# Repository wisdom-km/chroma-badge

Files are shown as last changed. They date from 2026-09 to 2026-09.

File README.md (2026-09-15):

# chroma-badge（BADGE-42C）：4.2 寸四色墨水屏 NFC 工牌

> **当前：** [状态](docs/06-current-status.md) · [交接](docs/03-handoff.md) · [流程](docs/09-process.md)（许可证 / CI / 贴胶 / 生产包）。2026-09-14 复审是**旧 564 段板**档案，不要当现板。

仓库：https://github.com/wisdom-km/chroma-badge

一块 **6.3 mm 厚**的电子工牌：4.2" 黑白红黄四色墨水屏 + ESP32-C3（Wi-Fi/BLE/原生 USB）+ ST25DV64KC NFC + ≤2 mm 超薄锂电 + USB-C。固件目前是 v0.2 上电自检；手机传图（F2）未写。

| 背面 PCB 渲染 | 外壳（FreeCAD） |
|---|---|
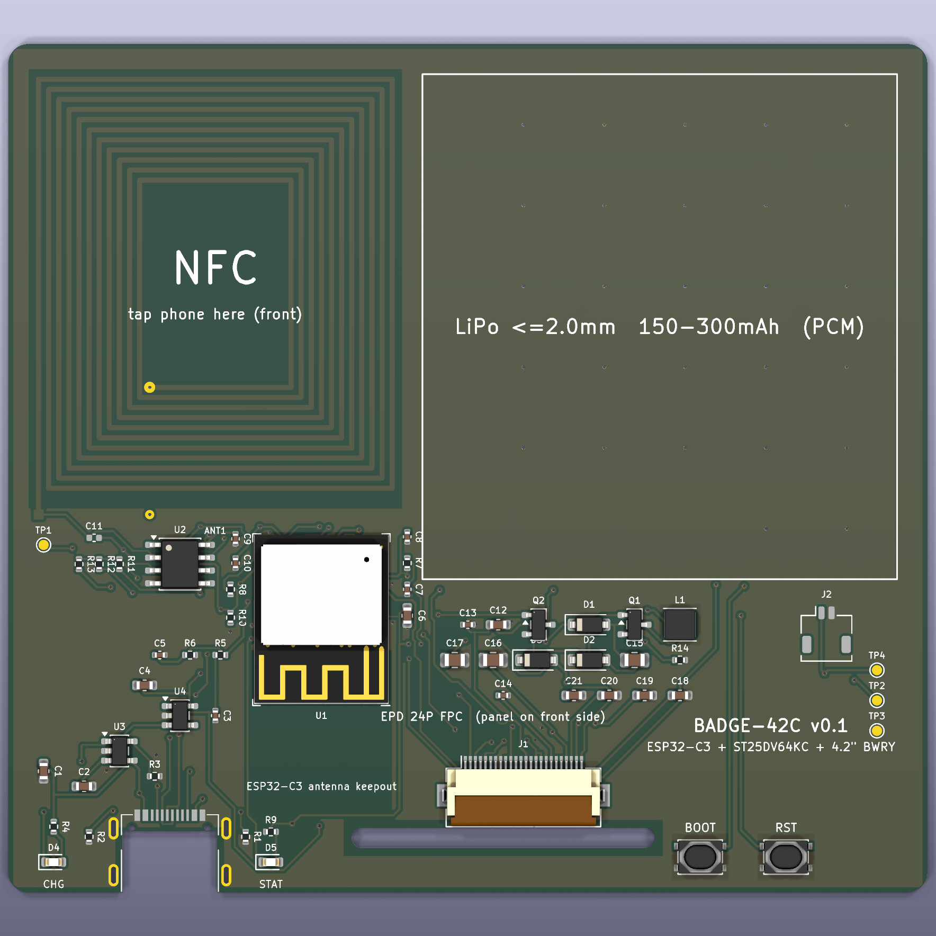
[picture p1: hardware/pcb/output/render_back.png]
pcb
|  | 见 `hardware/enclosure/output/badge_assembly.step` |

## 在本地接着做

```bash
git clone https://github.com/wisdom-km/chroma-badge.git
cd chroma-badge
```

用 Cursor **打开这个文件夹**（本地 Agent）。根目录 `AGENTS.md` 和 `.cursor/rules/badge.mdc` 会带上约定。

## 仓库

- `LICENSE.md`：硬件 CERN-OHL-P-2.0，固件/脚本 MIT
- `AGENTS.md`：硬性约定与当前进度
- `docs/01-architecture-decisions.md`：选型
- `docs/02-bom-and-cost.md`：BOM；屏贴胶 3M 467MP
- `docs/03-handoff.md`：复现步骤与**当前板**指纹
- `docs/09-process.md`：CI、生产包、贴胶
- `hardware/pcb/`：由 `scripts/design.py` 生成
- `firmware/README.md`：v0.2 自检；不要覆盖 `output/badge-42c-v0.1*.bin`

## 快速开始

全量 ERC/DRC 需要 KiCad **10.0.6**。不要把 `gen_pcb.py` 当日常命令（会清布线）。日常检查：

```bash
cd hardware/pcb
python3 scripts/check_netlist.py
./scripts/export.sh --check-only
```

自动布线流程见 `docs/03-handoff.md` 第 3 节。

## 状态

**H2（2026-09-15）：** 58 封装，PCB **680 段 / 115 过孔**，J1.7 NC。KiCad 10.0.6 全量 ERC/DRC 0。USB **0.8 mm**。固件 **v0.2 F1**。没有生产 zip。

下一步：打样实机；F2 须选定一条传图路线。

## 第三方内容

- 乐鑫 KiCad 库（ESP32-C3-MINI-1）：CC-BY-SA 4.0
- HRO TYPE-C-31-M-14 封装：jenschr/USB-C-Connectors，公有领域
- 其余符号/封装来自 KiCad 官方库

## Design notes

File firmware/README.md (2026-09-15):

# 固件

硬件引脚以 `hardware/pcb/scripts/design.py` 为准。本目录是 **v0.2 上电自检**：USB 日志、电池 ADC、ST25DV I²C 探测；正常启动后串口 5 s 内发 `W` 则按官方 OTP 刷一屏白（不要按住 BOOT 复位，那是 ROM 下载）。然后深睡，只由 `NFC_GPO`（GPIO1）低电平唤醒。GPIO9 不是深睡唤醒源。

屏：GDEM042F86 / SSD2683ZA，400×300，2 bit/像素（00 黑 01 白 10 黄 11 红）。初始化抄规格书 2026-06-17 **第 31 页** LUT from OTP，不写波形 RAM。

## 构建

ESP32-C3-MINI-1，原生 USB-Serial-JTAG（没有外置 UART）。

预编译基线（2026-09-14，不要覆盖）：

- `output/badge-42c-v0.1.bin`（应用，296 512 B）
- `output/badge-42c-v0.1-bootloader.bin`
- `output/badge-42c-v0.1-partitions.bin`

v0.2 用 `pio run` 生成到 `.pio/build/`，有板后再拷新版本号，不要覆盖上面三份。

```bash
cd firmware
pio run
pio run -t upload
pio device monitor
```

没有 PlatformIO 时：安装 [pio](https://platformio.org/) 或 Arduino-ESP32（板选 ESP32C3 Dev Module，CDC on boot）。不要把 PlatformIO IDE 的 `.vsix` 装进 Cursor（那是 VS Code 扩展）。

## 上电行为

1. GPIO2（`EPD_PWR_EN`）保持高：P-MOS 关，屏断电。
2. USB CDC 打 `BADGE-42C firmware v0.2`、电池电压、ST25DV 是否 ACK。
3. USB CDC 就绪后 **5 s 内发字符 `W`**：刷全白（约 20 s），BUSY 未完成周期则报 `TIMEOUT` 并断电。
4. 否则闪三下状态灯，深睡。只唤醒 `NFC_GPO`。**按住 BOOT + RESET = ROM 下载，不是刷白。**

还没做：NDEF URL、FTM 邮箱收图、完整工牌画面。

## 引脚表（ESP32-C3-MINI-1）

| GPIO | 信号 | 方向 | 说明 |
|---|---|---|---|
| 0 | `BAT_SENSE` | ADC1_CH0 | 电池电压 ÷2（1 MΩ / 1 MΩ），满电 4.2 V → 2.1 V |
| 1 | `NFC_GPO` | 输入，RTC 唤醒 | ST25DV GPO，开漏，100 kΩ 上拉。RF 场 / 邮箱新消息拉低 |
| 2 | `EPD_PWR_EN` | 输出 | 低有效。10 kΩ 上拉，P-MOS 默认关（strapping，上电为高） |
| 3 | `EPD_BUSY` | 输入 | 忙时为低（规格书 note 5-4） |
| 4 | `I2C_SDA` | I²C | ST25DV，4.7 kΩ 上拉 |
| 5 | `I2C_SCL` | I²C | 同上 |
| 6 | `EPD_SCK` | SPI CLK | 4 线 SPI（BS1 接地） |
| 7 | `EPD_MOSI` | SPI MOSI | |
| 8 | `LED_STAT_n` | 输出，低有效 | 绿色状态灯（strapping，空闲为高） |
| 9 | `BOOT_n` | 输入 | BOOT / 用户键 SW2，10 kΩ 上拉 |
| 10 | `EPD_CS` | 输出 | |
| 18 | `USB_D-` | USB | 原生 USB-Serial-JTAG |
| 19 | `USB_D+` | USB | |
| 20 | `EPD_DC` | 输出 | |
| 21 | `EPD_RST` | 输出 | |
| EN | RESET | | SW1，10 kΩ + 1 µF |

## 器件地址

- ST25DV64KC：I²C `0x53`（用户区）、`0x57`（系统区），FTM 邮箱 256 B
- 屏：GDEM042F86 = SSD2683ZA；不要用 GDEY042F51（HX8717）的 LUT

## 预算

- 每次刷新（含收图）：1.7–3 J
- 待机目标：≤ 15 µA

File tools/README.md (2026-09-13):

# 本机工具（Windows）

大软件装系统（KiCad / Git / 可选 FreeCAD），可移植的放这里。不要把 KiCad 或 FreeCAD 整个拷进仓库。

## 已约定路径

| 工具 | 路径 |
|---|---|
| KiCad 9 | `C:\Users\19612\AppData\Local\Programs\KiCad\9.0\` （当前用户安装；不是 `C:\Program Files\KiCad\9.0\`） |
| `kicad-cli` | `C:\Users\19612\AppData\Local\Programs\KiCad\9.0\bin\kicad-cli.exe` |
| KiCad Python | `C:\Users\19612\AppData\Local\Programs\KiCad\9.0\bin\python.exe` |
| 符号/封装库 | `...\9.0\share\kicad\symbols` 与 `...\9.0\share\kicad\footprints` |
| Freerouting 2.4.1 | `tools/freerouting/freerouting.jar` |
| 便携 JRE 25 | `tools/jre/bin/java.exe` |

`design.py` 会自动探测 `Program Files\KiCad` 和 `%LOCALAPPDATA%\Programs\KiCad`，并优先 9.x。若你改了安装位置，把实际路径写在上表。

## 装 KiCad 9（不要 8，也不要用 winget 默认的 10）

```powershell
winget install --id KiCad.KiCad -e --version 9.0.8 --accept-package-agreements --accept-source-agreements
```

装完**新开终端**，把 KiCad 加进 PATH（当前会话）：

本机实际路径（winget 当前用户安装）：

```powershell
$kicadBin = "$env:LOCALAPPDATA\Programs\KiCad\9.0\bin"
$env:Path = "$kicadBin;" + $env:Path
git --version
kicad-cli --version
where.exe kicad-cli
& "$kicadBin\python.exe" -c "import pcbnew; print('pcbnew ok')"
```

Git Bash：

```bash
export PATH="$LOCALAPPDATA/Programs/KiCad/9.0/bin:$PATH"
kicad-cli --version
```

`sexpdata` 必须装进 **KiCad 自带的 Python**，不是系统 Python：

```powershell
$py = "$env:LOCALAPPDATA\Programs\KiCad\9.0\bin\python.exe"
& $py -m pip install sexpdata
& $py -c "import sexpdata; print('sexpdata ok')"
```

## Freerouting 2.4.1 + 便携 JRE

jar 和 JRE 都 gitignore 了（体积大）。在仓库根目录执行：

```powershell
New-Item -ItemType Directory -Force -Path tools\freerouting, tools\_download | Out-Null

# Freerouting 2.4.1（不要 1.x）
curl.exe -L --fail -o tools\freerouting\freerouting.jar `
  https://github.com/freerouting/freerouting/releases/download/v2.4.1/freerouting-2.4.1.jar

# Eclipse Temurin JRE 25 x64 zip
curl.exe -L --fail -o tools\_download\OpenJDK25U-jre_x64_windows.zip `
  https://github.com/adoptium/temurin25-binaries/releases/download/jdk-25.0.4.1%2B1/OpenJDK25U-jre_x64_windows_hotspot_25.0.4.1_1.zip
```

把 zip 解压后，把里面那层 `jdk-*-jre\` 的内容挪到 `tools\jre\`，保证存在 `tools\jre\bin\java.exe`。

验证（相对路径；Freerouting 的 `-do` 必须在 `output` 目录下用相对文件名，绝对路径会得到 0 字节 `.ses`）：

```powershell
tools\jre\bin\java.exe -version
```

`route_pcb.py` 会优先用仓库里的 jar / JRE，找不到再回退 `/opt/freerouting/...` 或 PATH 里的 `java`。

**不要用 Python `subprocess` 跑 Freerouting。** 必须 `cd output` 再用相对 `-de`/`-do`。详见 `docs/03-handoff.md` 第 3 节。

## 冒烟测试

在仓库根目录：

```powershell
$kicadBin = "$env:LOCALAPPDATA\Programs\KiCad\9.0\bin"
$env:Path = "$kicadBin;" + $env:Path
cd hardware\pcb
& "$kicadBin\python.exe" scripts\check_netlist.py
# 若还没有 output\badge.net：
# kicad-cli sch export netlist -o output\badge.net badge.kicad_sch

kicad-cli pcb drc --severity-error --format json -o output\drc_tmp.json badge.kicad_pcb
```

期望：`netlist matches design.py`；`drc_tmp.json` 里 `violations` / `unconnected_items` 为空。

不要跑 `gen_pcb.py`（会清布线）。不要跑 Freerouting，除非要做 NFC 盖绿油。

## `export.sh`

Windows 用 Git Bash（不要改成只支持 cmd）：

```bash
cd hardware/pcb
export PATH="$LOCALAPPDATA/Programs/KiCad/9.0/bin:$PATH"
bash ./scripts/export.sh
```

`export.sh` 里的 `python3` 若找不到，用 KiCad Python 跑网表检查（KiCad 的 `python.exe` 一般没有 `python3` 这个名字）：

```bash
export PATH="$LOCALAPPDATA/Programs/KiCad/9.0/bin:$PATH"
"$LOCALAPPDATA/Programs/KiCad/9.0/bin/python.exe" scripts/check_netlist.py
```

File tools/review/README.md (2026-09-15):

# Cursor / Codex 本机审查执行手册（Windows）

本目录是**隔离审查工具**，不是替换 `hardware/pcb/scripts/export.sh` 的生产发布流程。它不重建PCB、不启动Freerouting、不修改产品固件。`postprocess_probe.py`在第二份副本上验证原`--skip-route`，不会碰工作区PCB。

阅读顺序：根AGENTS → 原交接/ADR → [当前状态](../../docs/06-current-status.md) → [合并计划](../../docs/reviews/2026-09-14/integrated-plan.md)。本轮基准的已知缺陷会使一些检查返回非零；正确记录失败，不要通过删掉警告获得“全绿”。

## 1. 环境发现与前置

本轮可用：KiCad9.0.8安装在 `D:/chroma-badge/agent-tools/kicad-9.0.8`；FreeCAD1.1.3在 `D:/FreeCAD`；PlatformIO6.2.0在 `D:/PlatformIO/penv`；MinGW GCC13.1.0来自CLion工具目录。工具体积大，`agent-tools/`在gitignore中，不入库。其他机器按实际路径修改变量。

```powershell
Set-Location D:/chroma-badge
git status --short
git log -5 --oneline
$kicadBin = 'D:/chroma-badge/agent-tools/kicad-9.0.8/bin'
$freecadPy = 'D:/FreeCAD/bin/python.exe'
$pio = 'D:/PlatformIO/penv/Scripts/pio.exe'
$gitBash = 'G:/BaseWare/Git/bin/bash.exe'
$compiler = 'G:/BaseWare/CodeProgram/CLion 2023.3.4/bin/mingw/bin/g++.exe'
& "$kicadBin/kicad-cli.exe" --version
& "$kicadBin/python.exe" -c "import pcbnew; print(pcbnew.Version())"
& $freecadPy -c "import FreeCAD, Part; print(FreeCAD.Version())"
& $pio --version
& $compiler --version
```

必须确认KiCad为9，不能因PATH上有10就直接采用。原文档记载的用户9.0路径在本轮开始时不存在，本机已有10。winget把安装9当成升级已有包而拒绝；本轮从`winget show --id KiCad.KiCad -e --version 9.0.8`查询官方安装包，校验SHA256后独立安装，没有卸载10。

9.0.8安装包SHA256：`f853f81dd6a90c769c521a35c438c5657fe39aaebe9967c8a74e743540920eb5`。
官方下载：[kicad-9.0.8-x86_64.exe](https://github.com/KiCad/kicad-source-mirror/releases/download/9.0.8/kicad-9.0.8-x86_64.exe)。静默安装需同时指定`/currentuser /S`，最后一个参数才是`/D=安装路径`；仅`/S`本轮返回666660。[KiCad官方打包问题记录](https://gitlab.com/kicad/packaging/kicad-win-builder/-/work_items/135)。安装软件前仍遵循当前任务授权，不把本文当无限安装授权。

受限运行环境可能无法访问用户安装目录/工具缓存。此时先核对权限与路径，不删除PlatformIO缓存、不反复重装。KiCad无需打开GUI即可执行这些测试。

## 2. 新建隔离输入副本

```powershell
$auditRoot = Join-Path (Get-Location) ('agent-tools/review-' + (Get-Date -Format 'yyyyMMdd-HHmmss'))
python tools/review/prepare.py --out $auditRoot
if ($LASTEXITCODE -ne 0) { throw 'prepare failed' }
```

`prepare.py`复制Git已跟踪的hardware/firmware文件，记录工作区输入SHA256、源提交与起始git状态。审查副本的`.kicad_pro`使用HEAD版本，原本机修改单独保存为`local-project.kicad_pro`。**如果硬件或固件文件有未提交修改，它们会被复制并在manifest中留痕，不能把该副本谎称纯HEAD。** 本轮只有工程配置有既有修改，已明确隔离。

输出目录必须全新；不复用已归档的 `docs/reviews/.../evidence`。安装器、SDK、模型和厂商PDF不得放到待提交集合。

## 3. KiCad全量检查与诊断导出

```powershell
python tools/review/kicad_checks.py --audit $auditRoot --kicad-bin $kicadBin --export
$auditExit = $LASTEXITCODE
Get-Content "$auditRoot/kicad/summary.json"
Get-Content "$auditRoot/kicad/commands.json"
```

这个审查程序故意继续收集完整诊断数据；任何子命令非零，最终程序返回1。**返回1不是可以忽略的发布成功**，应读 `commands.json` 与对应报告。不会发布制造包。

它逐项执行：

- 全量ERC、error级ERC，均加`--exit-code-violations`。
- 全量DRC加`--schematic-parity`、error级DRC；保留原始JSON。
- 重新导出网表后执行仓库原`check_netlist.py`。
- pcbnew读取PCB，逐个核对设计引脚/显式NC、板尺寸/层数、走线/过孔、网络宽度、3D模型引用和阻焊状态。
- `--export`时诊断导出Gerber、钻孔、BOM、位置、完整STEP，以及全板背面和J1特写。

本轮基准期望：error ERC0/DRC0/未连接0；全量ERC1条warning、DRC含parity148条warning；全量CLI返回5，审查程序返回1。报告类型：57 text_height、1 silk_over_copper、6 silk_overlap、62 footprint_symbol_mismatch、22 net_conflict。后三种不能都视为真实短路，详见复审解释。

模型文件缺失时KiCad STEP仍可能返回0，必须结合`board-audit.json`和`step.log`判断模型覆盖。板尺寸`91×84`取Edge.Cuts端点极值；含0.1mm线条笔画的包围盒是`91.1×84.1`，不要据此改板框。

补充原理图/板图诊断导出以及历史Gerber比较：

```powershell
python tools/review/extra_exports.py --audit $auditRoot --kicad-bin $kicadBin
if ($LASTEXITCODE -ne 0) { throw 'extra diagnostic export failed' }
Get-Content "$auditRoot/kicad/extra-exports.json"
```

比较只移除四类生成日期行，不移除坐标/孔径/属性；gbrjob单独未比较。本轮13份Gerber/钻孔文件中12份一致，背面丝印不同，不能交付旧ZIP当当前完整制造包。`--compare-only`可只重算已存在输出的比较。

## 4. 后处理幂等性（副本测试）

先验证原理图和NFC封装生成（可选扩展，本轮已执行）：

```powershell
& "$kicadBin/python.exe" -m pip install --target agent-tools/review-python-deps sexpdata==1.0.2
if ($LASTEXITCODE -ne 0) { throw 'generator dependency install failed' }
python tools/review/generators_probe.py --audit $auditRoot --kicad-bin $kicadBin --python-deps agent-tools/review-python-deps
if ($LASTEXITCODE -ne 0) { throw 'schematic/NFC generation probe failed' }
```

这会新建第三份副本，运行原生成器，再导出网表、运行原检查器和error ERC。KiCad自带Python的启动路径在本轮未采用外部PYTHONPATH，因此包装器显式添加隔离依赖目录；不改原生成器或Python安装。**不运行gen_pcb.py**。

```powershell
python tools/review/postprocess_probe.py --audit $auditRoot --kicad-bin $kicadBin
if ($LASTEXITCODE -ne 0) { throw 'postprocess changed routing or failed' }
Get-Content "$auditRoot/postprocess/summary.json"
```

它另复制一份PCB，执行两次`--skip-route`，每次保留原始日志和error级DRC，再比较走线/过孔的数量与精确坐标、层、网络、宽度、孔径指纹，以及设计网络分配。本轮三次快照均564/128、相同指纹。原路由日志仍可能写“若干几何islands未stitch”；本轮它们电气连通，不能用这句替代最终未连接检查。

这不验证“从未布线板重新Freerouting”的全链，也不证明任意新设计幂等。`--skip-route`源码仍可能修补走线，只在本轮输入上证实未改变。

## 5. FreeCAD生成和扩展交叠检查

```powershell
& $freecadPy tools/review/mechanical.py --snapshot "$auditRoot/snapshot" --out "$auditRoot/mechanical-saved-step.json"
if ($LASTEXITCODE -ne 0) { throw 'saved STEP geometry check failed' }
& $freecadPy tools/review/mechanical.py --snapshot "$auditRoot/snapshot" --step "$auditRoot/kicad/badge-fresh.step" --out "$auditRoot/mechanical-fresh-step.json"
if ($LASTEXITCODE -ne 0) { throw 'fresh STEP geometry check failed' }
& $freecadPy "$auditRoot/snapshot/hardware/enclosure/badge_enclosure.py"
if ($LASTEXITCODE -ne 0) { throw 'enclosure generation failed' }
& $freecadPy "$auditRoot/snapshot/hardware/enclosure/render_views.py"
if ($LASTEXITCODE -ne 0) { throw 'enclosure render failed' }
```

`mechanical.py`仅在内存中移除外壳脚本末尾`main()`调用后加载几何函数，原源文件不修改。实际原生成器另在副本运行。扩展检查5类物体两两10组，体积交叠容限0.05mm³并检查solid有效性。本轮都为0；但USB/电池座缺模型、FPC和电池等包络不完整，不能批准实装。检查源码后再检查对准的图；遵循`docs/05-visual-check.md`。

## 6. 固件构建、源映射和异常探测

```powershell
$env:PLATFORMIO_BUILD_DIR = Join-Path $auditRoot 'firmware-clean-build'
& $pio run -d firmware *> "$auditRoot/firmware-clean-build.log"
if ($LASTEXITCODE -ne 0) { throw 'firmware build failed' }
python tools/review/static_audit.py --out "$auditRoot/static.json" --build "$auditRoot/firmware-clean-build/badge-42c"
if ($LASTEXITCODE -ne 0) { throw 'source/pin audit failed' }
python tools/review/host_probes.py --compiler $compiler --out "$auditRoot/host"
if ($LASTEXITCODE -ne 0) { throw 'EPD characterization changed or compiler failed' }
python tools/review/fault_probes.py --bash $gitBash --out "$auditRoot/faults"
if ($LASTEXITCODE -ne 0) { throw 'failure-path characterization changed' }
```

这些probe里，**固件** host_probes 在 F1 之后：仅 `normal` 报成功；BUSY 恒高、卡低、关电超时、刷新超时必须失败。测试通过意味着假成功已堵住，不是实屏通过。H1 之后 `fault_probes.py` 已改为 **F04/F19 回归**：旧 DRC 报告注入必须失败；ERC/DRC 失败不得走到 Gerber。所有模拟输出中的毫秒都是替身时钟，不是屏幕测量。

静态审查比较模组符号脚名、design和pins.h，避免只照抄GPIO注释；检查9份原脚本AST、BOM/位置、旧ZIP目录一致性和三份bin哈希。它只记录ZIP/BOM问题，不把发现自动删除或重写。

## 7. export.sh（H1 之后）

H1 已改 `hardware/pcb/scripts/export.sh`：error 级 ERC/DRC 加 `--exit-code-violations`，去掉 DRC `|| true`；解释器为 `python3` / `python` / `py -3`；zip 用 `zip_dir.py`，不依赖 `zip` 命令。默认写入 `output/exports/<stamp>-candidate/`，**禁止**覆盖 `output/gerbers` 与 `output/badge_gerbers.zip`。`--production` 拒绝。全量 warning 见 `docs/hardware/drc-warning-register.md`，全部未豁免。

`fault_probes.py` 中的假 `kicad-cli` 仅用于隔离流程测试。不要仅放一个假的 python3 返回 0 来让真实脚本过关。候选目录不是生产包。

## 8. 证据与提交

本轮原始证据在`docs/reviews/2026-09-14/evidence/`，公开文件都列SHA256。今后新审查用新日期/轮次，不覆盖历史证据；不要提交整个`agent-tools`、安装包、SDK、缓存、厂商PDF或无关用户文件。

每次提交前检查：本轮变更是否只在预期范围、输入哈希是否还对应、报告是否保留失败、全量警告是否明确、网表/DRC是否当次运行、实际测试与未测是否分开。用户没有授权修硬件时不改网络，没有授权新PR时不创建PR；推送只按当前会话授权执行，禁止force push。

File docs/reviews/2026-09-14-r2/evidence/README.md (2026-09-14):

# 2026-09-14-r2 证据索引

隔离复跑目录：`agent-tools/review-20260914-234456`。本目录只收 **可入库的摘要与小文件**，不是生产包，也不覆盖 [首轮证据](../../2026-09-14/evidence/README.md)。大型 STEP/Gerber/SDK 留在 `agent-tools/`。

硬件/固件基准内容：`ee978f0`。审查时 HEAD：`11ab832`。

| 文件 | 用途 |
|---|---|
| [execution-summary.json](../execution-summary.json) | 退出码与“缺陷复现 vs 产品通过”区分 |
| [inputs.json](inputs.json) | 工作区 SHA256、起始 ` M badge.kicad_pro` / `?? tools/freerouting/` |
| [kicad-summary.json](kicad-summary.json)、[commands.json](commands.json) | 当次分类计数与命令返回码 |
| [erc-all.json](erc-all.json)、[erc-errors.json](erc-errors.json) | 全量 1 warning；error 0 |
| [drc-all-parity.json](drc-all-parity.json)、[drc-errors.json](drc-errors.json) | 148 warning；error/未连接 0 |
| [board-audit.json](board-audit.json) | 57/564/128、91×84×0.8、J2/J3 模型缺失、网络类别未进工程 |
| [extra-exports.json](extra-exports.json) | 诊断导出；B.Silk 归一化不相等 |
| [postprocess-summary.json](postprocess-summary.json) | 布线指纹三次相同 |
| [generators-summary.json](generators-summary.json) | 未跑 `gen_pcb.py` |
| [static.json](static.json) | AST、GPIO 映射、ZIP 内部一致、bin 哈希 |
| [firmware-clean-build.log](firmware-clean-build.log) | 干净目录构建 SUCCESS |
| [epd-probes.json](epd-probes.json)、[host-compile.log](host-compile.log) | 20 次替身；含假成功 |
| [faults.json](faults.json) | 旧 DRC 报告与 DRC 吞错 |
| [mechanical-*.json](mechanical-saved-step.json) | 10 组交叠 0；缺 FPC/真电池包络 |
| [original-export.log](original-export.log) | 原 export.sh：本轮 Git Bash 无 python3 |
| [step.log](step.log) | STEP 仍返回 0 |

预览是本轮新渲，不是实物照片：

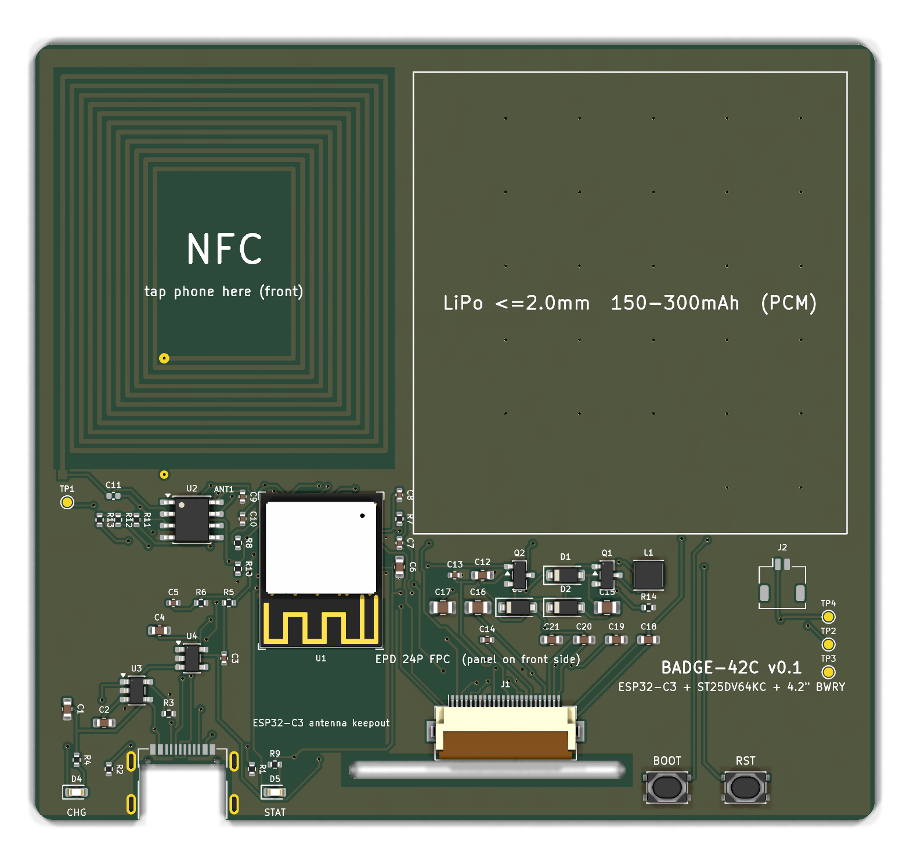
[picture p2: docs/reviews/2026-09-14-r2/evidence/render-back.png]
背面全板


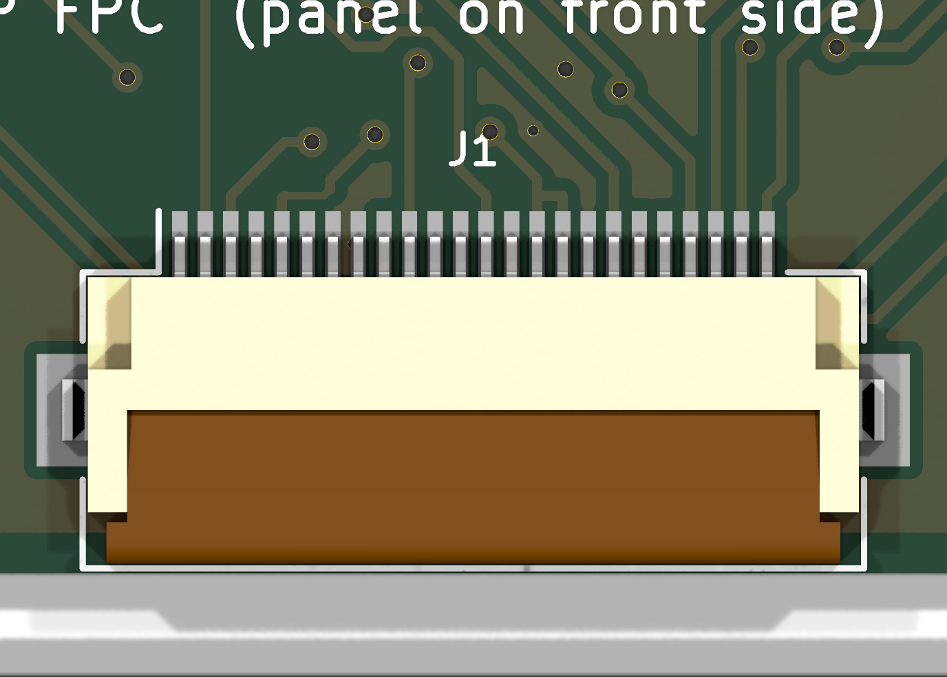
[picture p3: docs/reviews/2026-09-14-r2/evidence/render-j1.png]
J1 特写


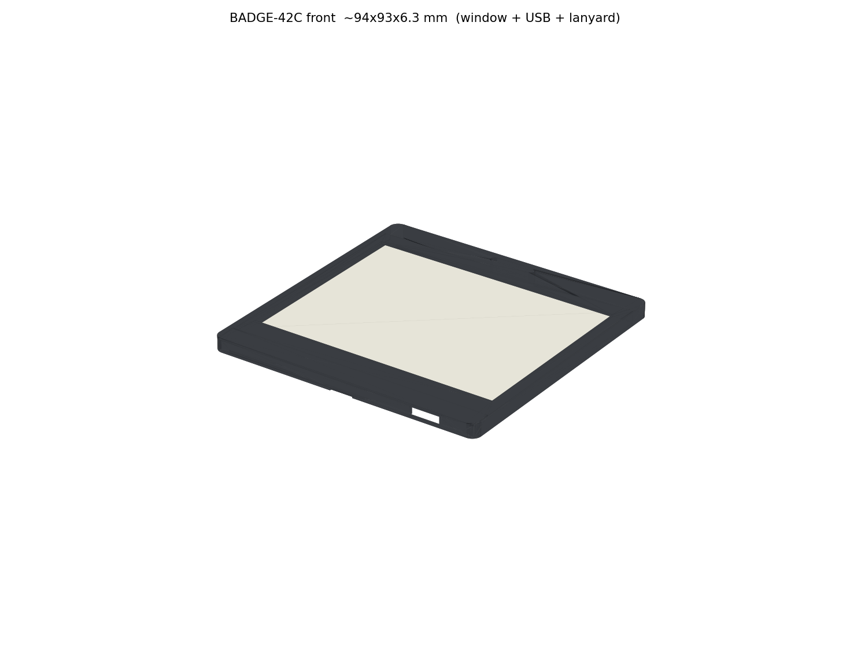
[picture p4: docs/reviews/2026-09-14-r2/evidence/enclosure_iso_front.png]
外壳正面结构


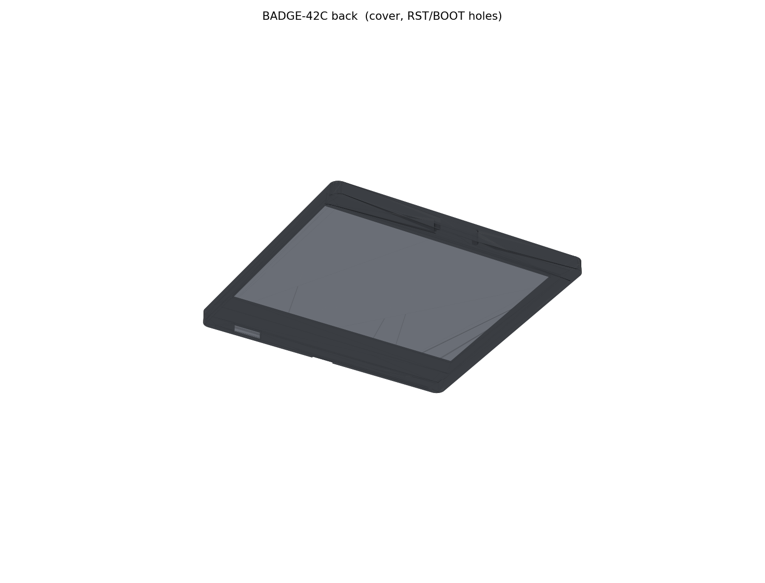
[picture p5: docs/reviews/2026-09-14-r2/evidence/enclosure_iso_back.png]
外壳背面结构


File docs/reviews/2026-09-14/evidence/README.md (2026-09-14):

# 2026-09-14 本机复审证据索引

硬件/固件基准：`ee978f08cbdb7b61bbe2c78fea0e9c7cd2c34a7b`。本目录包含诊断证据，**不是生产发布包**。缺陷仍未修复，实机测试尚未执行。完整结论见 [独立复审](../local-review.md) 和 [合并计划](../integrated-plan.md)。

## 输入与完整性

| 文件 | 内容 |
|---|---|
| [inputs.json](inputs.json) | 审查开始时工作区已跟踪文件的SHA256/大小、源commit和起始状态；审查副本用提交版工程配置 |
| [sources.json](sources.json) | 用户原审查、确切屏PDF、KiCad安装包SHA256；屏PDF印刷日期2026/06/17、Revision1.0、40页；PDF未入库 |
| [preservation.json](preservation.json) | 确认所有原硬件/固件及其输出文件字节未变；保留起始本机`.kicad_pro`改动 |
| [manifest.json](manifest.json) | 本目录各证据文件SHA256和字节数；清单不包含自身 |

目录属性禁止Git换行转换，以便原始日志与报告SHA256在不同机器检出仍一致。`inputs.json`的输入哈希描述审查时的工作区字节，而非声称所有输入文件等于Git规范化blob字节。

## 检查结果与原始报告

| 文件 | 结果与用途 |
|---|---|
| [commands.json](commands.json)、[summary.json](summary.json) | 当次KiCad命令/返回值和全量分类统计 |
| [erc-all.json](erc-all.json)、[erc-errors.json](erc-errors.json) | 全量1警告，error0；U1库符号问题未关闭 |
| [drc-all-parity.json](drc-all-parity.json)、[drc-errors.json](drc-errors.json) | 64板级+84parity警告，error0、未连接0 |
| [drc-localsettings.json](drc-localsettings.json) | 起始本机未提交配置下error级DRC仍0；使用的是副本 |
| [netlist-check.log](netlist-check.log)、[netlist-export.log](netlist-export.log) | 新导出网表后运行原检查器，匹配设计、63原理图网络 |
| [generators-summary.json](generators-summary.json)、[generated-erc.json](generated-erc.json) | 原理图/NFC生成器真实复跑；网表匹配、error ERC0；NFC封装忽略换行相同 |
| [execution-summary.json](execution-summary.json) | 补充命令退出码与测试性质，区分产品通过与旧缺陷复现 |
| [board-audit.json](board-audit.json) | 57封装/564段/128孔/91×84×0.8mm、引脚映射、网络统计、模型缺项、NFC阻焊与未落地类别 |
| [postprocess-summary.json](postprocess-summary.json) | 原板→第一次→第二次`--skip-route`的路由指纹一致 |
| [postprocess-cycle-1.log](postprocess-cycle-1.log)、[postprocess-cycle-2.log](postprocess-cycle-2.log) | 原后处理过程，未启动Freerouting；日志里几何岛描述不是未连接判定 |
| [postprocess-cycle-1-drc.json](postprocess-cycle-1-drc.json)、[postprocess-cycle-2-drc.json](postprocess-cycle-2-drc.json) | 两次独立最终error报告，违规/未连接均空 |
| [static.json](static.json) | 9份原Python脚本AST、13个GPIO映射、BOM/位置、当前ZIP内部比较、三份固件哈希 |
| [firmware-clean-build.log](firmware-clean-build.log) | 全新目录编译，包括真实依赖/内存占用；三份bin与原版本字节一致 |
| [epd-probes.json](epd-probes.json)、[host-compile.log](host-compile.log) | 20次原EPD代码的替身调用；有两种已复现假成功；fake_elapsed_ms不是实测时间 |
| [faults.json](faults.json) | ERC进程失败可阻断；DRC失败被吞；`drc_json`返回旧报告的故障注入 |
| [original-export.log](original-export.log)、[bash-prerequisites.log](bash-prerequisites.log) | 原导出脚本实际执行到python3退出49；WindowsApps别名及缺zip，不是制造包生成成功 |

## 制造与机械

| 文件 | 结果与局限 |
|---|---|
| [extra-exports.json](extra-exports.json) | 原理图PDF/SVG、PCB SVG、裸板STEP命令成功；13份新旧Gerber/孔数据的日期归一化比较 |
| [manufacturing-diff.json](manufacturing-diff.json)、[back-silkscreen.diff](back-silkscreen.diff) | 旧背面丝印与新导出真实坐标不同；旧ZIP内部一致却仍带旧丝印 |
| [step.log](step.log) | J3、J2模型无法加入，但完整STEP命令仍返回0 |
| [mechanical-saved-step.json](mechanical-saved-step.json) | 既有STEP下实体有效、扩展10组交叠为0 |
| [mechanical-fresh-step.json](mechanical-fresh-step.json) | 新导出STEP下同样通过；缺实体仍不能检验相应干涉 |
| [enclosure-generation.log](enclosure-generation.log)、[enclosure-render.log](enclosure-render.log) | 原FreeCAD生成器/5张预览真正运行，产物都在副本 |

其他同名`.log`保留对应CLI原输出。大型STEP、生成器副本、SDK、安装包、厂商PDF和模拟可执行文件留在忽略目录，不入库。新生成的Gerber只是诊断，不覆盖原制造包；既有生产包的来源不因本报告而获得批准。

## 对准的预览

这些是本轮新生成图片，不是实物照片。J1特写已对准连接器和槽；J2/J3缺外形必须与模型解析日志结合看，不能推断没放PCB元件。FreeCAD两图用于看结构，严格干涉判断来自OCC数值。

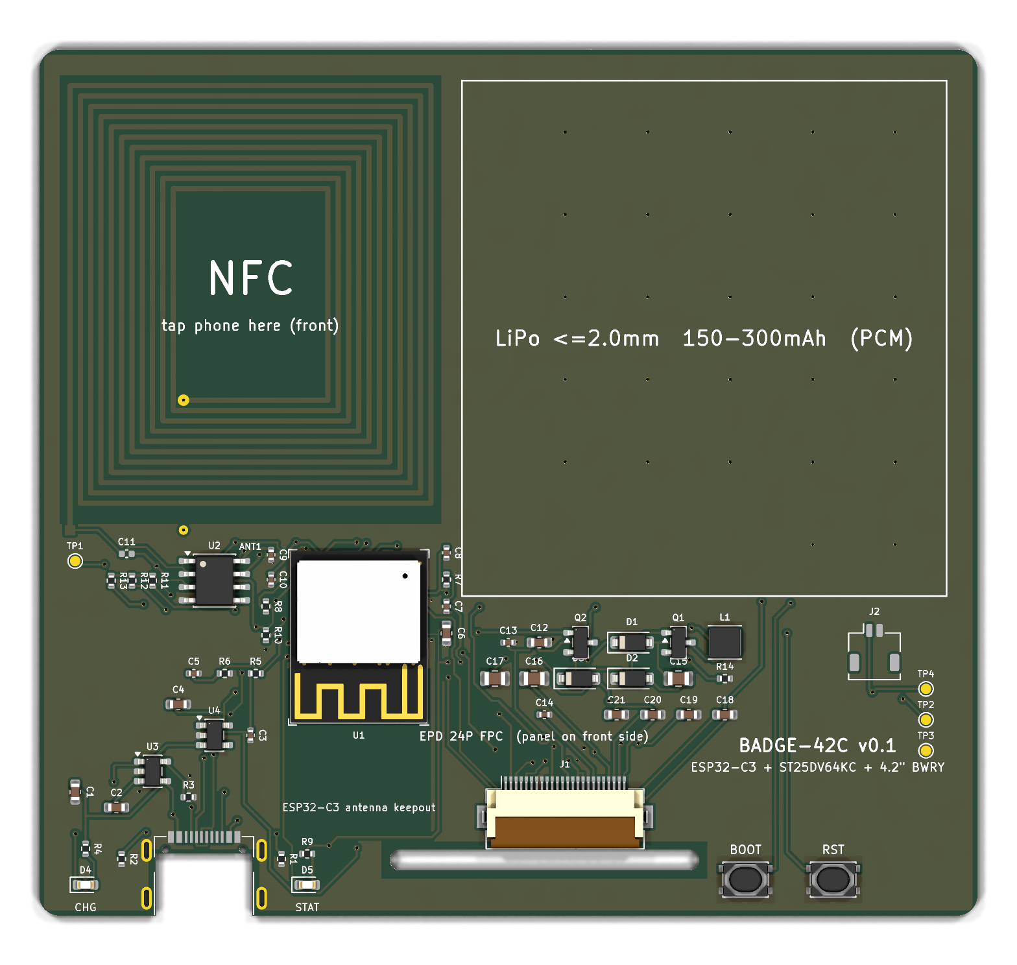
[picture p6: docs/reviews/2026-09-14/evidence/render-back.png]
本轮KiCad背面全板


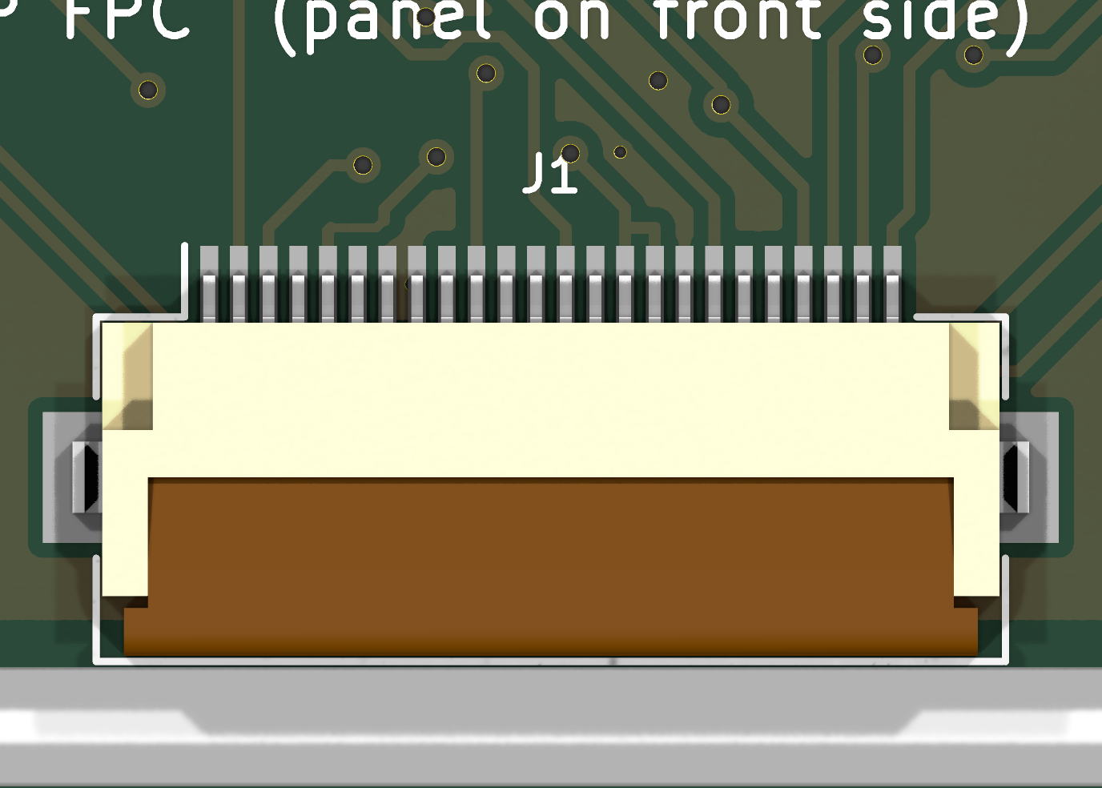
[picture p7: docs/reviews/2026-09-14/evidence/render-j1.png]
J1与FPC槽的对准特写


FreeCAD前框预览

FreeCAD后盖预览

## 复跑和判读

执行 [工具手册](../../../../tools/review/README.md)，每轮使用新的隔离目录。全量检查返回5表示发现违规，审查收集程序最终返回1是保留失败，不是测试工具意外全部崩溃。`host_probes`和`fault_probes`是旧缺陷特征测试；通过意味着缺陷被复现，修复后必须改成新的防回归预期。

能得出的结论：设计数据/当前error规则检查、编译及有限几何验证有证据；存在已确认缺陷和交付不同步。不能得出的结论：真实USB/显示/RF/充电/续航/装配已通过，或可立即生产。

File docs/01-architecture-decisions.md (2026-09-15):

# 架构决策记录（ADR）

本文记录 4.2 寸彩色墨水屏工牌的关键选型和取舍。所有数字来自 2026 年 9 月检索到的厂商公开资料，价格为参考价。

## 1. 屏幕：4.2 寸四色（BWRY），而不是六色

### 为什么 4.2 寸没有六色可选

E Ink Spectra 6（六色）目前的小尺寸型号只有 1.54"、1.69"、3.6"、3.7"、4.0"、5.9"、7.3"，**没有 4.2 寸**。
最接近的是 4.0 寸 GDEP040E01（600×400，外形 99×66 mm，偏宽屏）和 3.7 寸 GDEH037E01（480×720，58×85.6 mm，竖版）。

### 四色 vs 六色 显示效果

| | 4.2" 四色 GDEM042F86 | 4.0" 六色 GDEP040E01 |
|---|---|---|
| 颜色 | 黑 / 白 / 红 / 黄 | 黑 / 白 / 红 / 黄 / 蓝 / 绿 |
| 分辨率 / PPI | 400×300 / 119 | 600×400 / 180 |
| 全刷 | 20 s（快刷 12 s） | 14–19 s |
| 刷新功耗 | 12 mW（VCI=3.0 V） | < 70 mW |
| 工作温度 | 0–40 ℃ | 0–50 ℃ |
| 裸屏价格 | ≈ ¥70–100 | ≈ ¥100–330 |
| 驱动库 | 佳显官方 ESP32 示例；GxEPD2 支持同系列 HX8717 版 | GxEPD2 不支持 4.0"，需自写 |

**结论**：
- 显示"彩色照片 / 渐变 logo"六色明显更好（PPI 高 50%，色域大一倍）。
- 显示"姓名 + 职位 + 二维码 + 品牌色块"这类工牌内容，四色已经够用，红黄两色足够做强调色和公司标识。
- 六色刷新功耗是四色的 5–6 倍，直接决定了下面的供电方案能不能做薄、能不能无源。

因此 v1 选 **4.2 寸四色**。板子的屏接口是标准 24 pin 0.5 mm FPC，同族的
GDEM042F86（SSD2683ZA，现行型号）、Waveshare 4.2inch e-Paper (G)、GDEY042F51（HX8717，已 EOL）都能接，只需换固件驱动。

## 2. 供电：超薄锂电 + USB-C，而不是纯 NFC 无源

用户偏好是"最好不加电池"。这一节解释为什么自研板 v1 不走无源路线，以及无源路线怎么走。

### 2.1 一次刷新要多少能量

- 屏本身：12 mW × 20 s ≈ 0.24 J，加升压损耗按 ×1.3 → **≈ 0.32 J**
- 若用 ESP32-C3 收图（不开 Wi-Fi，只走 NFC 邮箱）：约 20 mA × 3.3 V × 25 s ≈ 1.7 J
- 若开 BLE 收图：约 3 J；开 Wi-Fi：5–9 J

### 2.2 手机 NFC 能供多少

| 芯片 | 手机场强下可采集功率 | 说明 |
|---|---|---|
| ST25DV64KC（ST） | "数 mW"，无规格值，不稳压 | 只能给 MCU 待机/唤醒，不够刷屏 |
| NTAG 5 boost（NXP） | 低场强模式 ≤ 20 mW，稳压 | 勉强够 12 mW 的屏，MCU 没余量 |
| FM1280（复旦微） | 足够驱动 4.2" 四色 | 佳显 NFC-D4-042 无源驱动板用的就是它 |
| TN2115S2（Chivotech） | 典型 60–150 mW，最高 300 mW | Waveshare 无源系列用它；已停产，佳显 DENFC-M01 因此不再支持二次开发 |

### 2.3 结论

**4.2 寸四色无源 NFC 是可行的，市面上有成品**：大连佳显 NFC-D4-042 驱动板（FM1280，91×77×1.0 mm，
刷新功率 ≤ 15 mW，兼容单色/三色/四色，配 App，官网有原理图），配 GDEM042F86 屏就是一块无电池工牌。

但作为**自研开源 PCB**，无源路线有三个硬伤：

1. 能做到的芯片只有 FM1280 / TN2115S2 这类"NFC 取电 MCU"，公开资料稀少，SDK 不对个人开放，
   Waveshare 的固件是社区逆向出来的。做成开源项目会卡在固件上。
2. 手机必须贴着不动 20–30 s（传图 + 刷新），iPhone 还有 20 s 会话限制需要特殊处理。
3. 无源方案没有 Wi-Fi/BLE，"网站图传"只能靠手机 NFC 中转，无法做到"网页点一下工牌自己更新"。

所以 v1 采用：

- **超薄锂电**：≤ 2.0 mm 厚软包，150–300 mAh，自带保护板（PCM），例如 202545 / 232535 规格
- **USB-C 充电**（沉板式 TYPE-C-31-M-14，Mid-mount，只高出板面约 1.6 mm）。
  座子产品页按 0.75 mm 板；嘉立创无 0.75 档，v1 **按 0.8 mm 打样**（2026-09-14）
- 预留无线充电升级：v2 可在电池仓背面贴 Qi 接收线圈（0.5–1 mm 厚）+ BQ51013B 类接收 IC；
  NFC 能量采集（mW 级）给锂电充电没有实际意义，不做。

### 2.4 续航估算

- 每次更新：1.7–3 J ≈ 0.13–0.23 mAh @3.7 V → 250 mAh 电池 ≈ **1000 次以上更新**
- 待机电流：**待测**。常供电 SO8 ST25DV 规格书典型待机约 76 µA，不能再用「ESP 5 + ST25DV <1 + LDO 5 + 分压 2 ≈ 13 µA / 两年」作为承诺。有板号、温度、电池、USB 断开条件的电流数据之前，禁止写续航年数。

## 3. NFC：ST25DV64KC 动态标签

作用：
- **手机碰一碰唤醒**：RF 场检测 → GPO 拉低 → 唤醒深睡的 ESP32-C3
- **NDEF 引导**：手机读到 URL，自动打开编辑网页（无需装 App）
- **快速传输模式（FTM）**：256 B 邮箱，RF 侧写入速率约 26 kbit/s，一张 400×300×2 bit = 30 KB 的图
  纯 NFC 传输约 10–15 s；也可以只传 Wi-Fi/BLE 配对信息，图走 BLE / SoftAP
- 双接口：I²C 连 MCU，同一片 EEPROM 手机和 MCU 都能读写

天线：PCB 环形天线，位于板上不与电池重叠的区域。ST25DV 内置调谐电容 28.5 pF，
目标电感 ≈ 4.8 µH。手机从**正面**贴屏幕右侧即可（NFC 场可穿透墨水屏玻璃，Waveshare/佳显无源方案的天线同样在屏背面）。

## 4. 主控：ESP32-C3-MINI-1 模组

- Wi-Fi + BLE 5，为后续"网页图传"保留能力
- 原生 USB（GPIO18/19）：USB-C 直接烧录和串口调试，不需要 CH340
- 模组厚 2.4 mm，是整机厚度的决定因素之一；选模组而不是裸片是为了避开天线匹配和认证风险
- 400 KB SRAM，30 KB 帧缓冲无压力

## 5. 厚度堆叠（目标 ≤ 6 mm）

从正面到背面：

| 层 | 厚度 |
|---|---|
| 前框（ABS/PETG 3D 打印，或后期开模） | 0.8 mm |
| 墨水屏 GDEM042F86 | 1.0 mm |
| PCB（2 层，0.8 mm） | 0.8 mm |
| 元件区 / 电池区（取最大：ESP32-C3-MINI-1 2.4 mm；电池 2.0 mm） | 2.4 mm |
| 后盖 | 0.8 mm |
| **合计** | **5.8 mm** |

对比：Waveshare 4.2" 无源 NFC 成品 9.9 mm；佳显 GDN042BW 10.2 mm。

屏 **91×77×1.0** 贴在 PCB 正面；PCB 在屏下加 7 mm 条（USB/按键），所以板是 **91×84×0.8**。FPC 从槽绕到背面插 J1。上表 5.8 mm 是目标叠层；FreeCAD 前框 `BEZEL_T=1.0` 加后腔间隙后整机约 **6.3 mm**。

## 6. 不做的事（v1）

- 固件与手机/网页端：另行开发，本仓库只给出引脚表和接口约定
- 无线充电：v2
- 六色屏：若后续需要，换 4.0" GDEP040E01 需重新设计外壳（99×66 mm）和升压电路参数

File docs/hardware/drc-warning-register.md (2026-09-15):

# 全量 ERC/DRC warning 登记表（非豁免）

日期：2026-09-15。检查器：**KiCad 10.0.6**（`C:\Users\19612\AppData\Local\Programs\KiCad\10.0\bin`）。来源：本机 `hardware/pcb/output/erc_all_h2.json`、`drc_all_h2.json`（官方 `sym-lib-table` + `KICAD10_SYMBOL_DIR` + 工程 `hardware/pcb/sym-lib-table`）。

**本表不是豁免批准。** 当前全量 warning **0**。error 级 0 仍不等于「可以下生产包」——候选 Gerber ≠ 生产 zip。

逐条列表：[drc-warning-register.csv](drc-warning-register.csv)（现为空）。2026-09-14 r2 的 148 条是旧 57 件板档案，不要和本表混用。KiCad 9.0.8 读不了工程 `Espressif.kicad_sym`（KiCad 10 格式）；全量以 10.0.6 为准。

## 规则

| 字段 | 含义 |
|---|---|
| 状态 | `未豁免` = 仍算未通过全量检查 |
| 对 error 级候选导出 | 不阻断（`--severity-error`） |
| 对生产包 | 阻断，直到有批准人或已修复 |
| 失效条件 | 换 KiCad 版本、改丝印/封装生成、改网络规则后必须重跑全量 |

## 汇总（H2 板：58 封装，680 段 / 115 过孔）

| 类型 | 条数 | 说明 |
|---|---|---|
| ERC 全量 | **0** | U1 `Espressif:ESP32-C3-MINI-1` 53 脚与封装、`design.py` 一致 |
| DRC 全量（含丝印） | **0** | 含 `schematic_parity` |
| 未连接 | **0** | |

## KiCad 10 相对 KiCad 9 已对齐的项

| 项 | 做法 |
|---|---|
| U1 符号库 | 用 KiCad 10 读工程 `lib/Espressif.kicad_sym`；引脚 1–53 与 `badge:ESP32-C3-MINI-1`、GPIO 映射一致 |
| J3 外壳脚 | KiCad 10 符号为 `SH`；封装/板上焊盘由 `S1` 改为 `SH`（四只沉板支架，仍接 GND） |
| Q1 封装 | 官方 10.0 SOT-323 已重生；活板实例写入 `badge:SOT-323_SC-70`，避免和官方库比丝印 |
| 字段 | Description / Datasheet / LCSC 在封装上隐藏于 `B.Fab` |
| 原理图 | `gen_schematic.py` 按 KiCad 10 符号库嵌入（不再剥 v10 token） |

不要为丝印再跑 `gen_pcb.py` / Freerouting。不要把候选 Gerber 当生产包。

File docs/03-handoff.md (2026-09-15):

# 项目交接文档

进度快照：**2026-09-15 H2 + 固件 v0.2 F1**。历史 2026-09-14 旧板（57 件 / 564 段 / 脚 7 GND）只在第 7 节。

给接手的下一位（人或 AI）：先读 [AGENTS.md](../AGENTS.md)、本文、[01-architecture-decisions.md](01-architecture-decisions.md)、[09-process.md](09-process.md)。**不要推翻 ADR。** 硬件改动一律先改 `hardware/pcb/scripts/design.py`，再跑生成脚本。不要手改 `.kicad_sch`。

## 新会话请直接粘贴这段

```
继续 BADGE-42C（4.2 寸四色墨水屏 NFC 工牌）。先读 AGENTS.md、docs/03-handoff.md、docs/01-architecture-decisions.md、docs/09-process.md。

用户 Wisdom，始终用中文回复。硬件改动从 hardware/pcb/scripts/design.py 开始，不要手改 .kicad_sch；不要跑 gen_pcb.py 除非铜皮/焊盘/板框变了并准备好重新 Freerouting（会清布线）。只改阻焊/丝印用 apply_hygiene.py，不要重布。Freerouting 必须按 docs/03-handoff.md 第 3 节从交互 shell、相对路径启动。文档和板上事实冲突时先问用户。3D/截图不确定时先读 docs/05-visual-check.md。

当前板：58 封装、680 段 / 115 过孔，J1.7 NC Keep Open。KiCad 10.0.6 全量 ERC/DRC 0。固件 v0.2 F1（深睡仅 GPIO1；串口 W 刷白）。不要覆盖 firmware/output/badge-42c-v0.1*.bin。不要把候选 Gerber 当生产包。

下一步：有板实测 USB/充电/BUSY/NFC/电流；F2 须 Wisdom 选定 NDEF/FTM 或 BLE/SoftAP 一条路线。

提交前：hardware/pcb 下 python scripts/check_netlist.py；有 KiCad 时 ./scripts/export.sh --check-only。不要建 PR，除非用户明确要求。
```

---

## 0. 一句话

4.2 寸四色墨水屏 NFC 工牌（**BADGE-42C**）：ESP32-C3-MINI-1-N4 + ST25DV64KC + 超薄锂电 + USB-C，整机约 6.3 mm。

**当前板已通过 KiCad 10.0.6 全量 ERC/DRC。** USB 按 0.8 mm 打样。J1.7 NC。固件 v0.2 是上电自检，不是工牌传图。没有授权生产 zip。

## 1. 仓库结构

```
LICENSE.md / LICENSES/MIT.txt     硬件 CERN-OHL-P-2.0；固件/脚本 MIT
.github/workflows/ci.yml          网表 + host_probes + pio（不是 DRC）
docs/
  01-architecture-decisions.md    选型（先读）
  02-bom-and-cost.md              人读 BOM；屏贴胶 3M 467MP
  03-handoff.md                   本文
  04-review-checklist.md          打样前人工复核
  05-visual-check.md              3D/截图：拍错 vs 板上问题
  06-current-status.md            审查状态入口
  07-defect-fix-project.md        H/F 工作包
  08-h2-h3-questions.md           已关闭拍板记录
  09-process.md                   许可证 / CI / 贴胶 / 生产包
  hardware/drc-warning-register.md  全量 warning（现为 0）
hardware/pcb/                     KiCad 工程（原理图由脚本生成）
  scripts/design.py               **唯一事实来源**
  scripts/gen_schematic.py
  scripts/gen_pcb.py              清全部布线；仅铜皮/焊盘/板框
  scripts/apply_hygiene.py        活板丝印/FPID/NC；不动走线
  scripts/route_pcb.py            导入 + GND 缝合 + DRC
  scripts/export.sh               默认候选目录，不是生产包
firmware/                         PlatformIO v0.2 自检；output/ 里 v0.1 是基线 bin
```

全量 ERC/DRC 用 **KiCad 10.0.6**（`C:\Users\19612\AppData\Local\Programs\KiCad\10.0\bin`）。KiCad 9 读不了工程里的 `Espressif.kicad_sym`（10 格式）。`pcbnew` 脚本（`apply_hygiene.py`）仍可用本机 KiCad 9 Python，以免改写板文件格式。

## 2. 环境

| 工具 | 版本 / 位置 |
|---|---|
| KiCad 全量检查 | **10.0.6**，`C:\Users\19612\AppData\Local\Programs\KiCad\10.0\bin` |
| KiCad pcbnew 脚本 | 可选 9.0.x `python.exe`（`apply_hygiene` / 部分生成） |
| FreeCAD | 本机 Windows：`D:\FreeCAD\bin\freecadcmd.exe`（1.1.3） |
| Freerouting | 2.4 + Java 25；jar 本机自备，不入库 |
| PlatformIO | **6.2.0** + `espressif32@7.1.3`（见 `firmware/platformio.ini`） |
| 固件 host 探针 | g++（本机 MinGW 13.1.0） |

## 3. 完整复现流程

不要把下面 `gen_pcb.py` 当成日常命令。只改丝印/阻焊：`apply_hygiene.py`。只补 GND：`--skip-route`。

```bash
cd hardware/pcb
python3 scripts/gen_nfc_footprint.py
python3 scripts/gen_schematic.py
kicad-cli sch export netlist -o output/badge.net badge.kicad_sch && python3 scripts/check_netlist.py
python3 scripts/gen_pcb.py                # 会清掉全部布线
python3 -c "import pcbnew; b=pcbnew.LoadBoard('badge.kicad_pcb'); pcbnew.ExportSpecctraDSN(b,'output/badge.dsn')"
cd output && rm -f badge.ses && java -jar <freerouting.jar> \
      -de badge.dsn -do badge.ses -mp 100 -mt 1 > freerouting.log 2>&1 && cd ..
python3 scripts/route_pcb.py --import-only
./scripts/export.sh --check-only          # 日常；不要 --production
```

Freerouting 必须从**交互 shell、相对路径**启动，输出重定向到文件。Python `subprocess` 或绝对 `-do` 会得到 0 字节 `.ses`。

只补 GND、不动走线：

```bash
cd hardware/pcb
python3 scripts/route_pcb.py --skip-route
```

只动丝印/封装前缀/NC 网（不清布线）：

```bash
cd hardware/pcb
python3 scripts/apply_hygiene.py
python3 scripts/gen_schematic.py
```

**已知坑**

1. Freerouting 必须交互 shell + 相对路径，见上。
2. `ZONE_FILLER` 对内存中新建的 `BOARD()` 会段错误，必须先保存再 `LoadBoard`。
3. `FOOTPRINT.Flip(LEFT_RIGHT)` 后要用 `GetOrientationDegrees()+rot` 叠加。
4. 乐鑫符号是 **KiCad 10** 格式。全量检查用 10.0.6；`gen_schematic.py` 按 10 嵌入，**不要再剥 v10 token**。
5. `.kicad_sch` 的 `lib_symbols` 子单元名必须是裸的 `Name_0_1`。
6. 板边铜间距 0.1 mm（沉板 USB-C 外壳焊盘贴边）。
7. **只改阻焊不要重布线。** 旧文档曾写「改 NFC 封装必须 `gen_pcb.py`」。线圈铜皮没变时清布线会丢掉已验证走线。
8. 文档和板上事实冲突：**先问用户**，不要自行换流程或 Freerouting。
9. 3D/截图看不清：`docs/05-visual-check.md`。拍错自己修图。
10. `export.sh --production` 会直接拒绝。候选目录不是下单包。

## 4. 当前状态（H2 板）

| 项 | 状态 |
|---|---|
| 原理图 | **58** 元件；KiCad 10.0.6 全量 ERC 0；网表 == `design.py`。J1 pin **7 = NC Keep Open** |
| PCB | 91×84 mm，2 层 0.8 mm，元件全在 B.Cu。**680 段 / 115 过孔**。全量 DRC 0、未连接 0、parity 0 |
| 线宽 | Power ≥0.3 mm（GND 靠铺铜）；NFC 0.5 mm；USB 0.8 mm |
| 过孔 | 最小 0.4 mm、钻孔 0.2 mm |
| U2 | `Badge:ST25DV64KC-SO8N`（8 脚，不是官方 UFDFPN+EP） |
| NFC 线圈 | 11 圈约 35×41.5 mm；SMD 盖绿油；通孔 pad 2 仍开窗；C11 **DNP** |
| 外壳 | 约 94×93×6.3 mm；`ACTIVE_TOP=6.7` |
| 固件 | **v0.2 F1**：USB 日志、VBAT、I²C ACK、串口 `W` 刷白、深睡仅 GPIO1。v0.1 bin 在 `firmware/output/` 作基线 |
| 制造 | 无生产 zip。旧 `output/gerbers` 不要当下单文件 |

`output/drc_all_h2.json` / `erc_all_h2.json`：全量 0。`drc_final.json`：error 级 0。全量 0 ≠ 生产包。

## 5. 下一步

1. 授权生产包后再打样（新目录 + manifest）。见 [09-process.md](09-process.md)。
2. 有板：USB、充电、`W` 刷白、NFC 唤醒、电流。
3. F2：Wisdom 选定 **一条** 传图路线后再写。
4. 不要重开 USB 0.8 mm、NFC 绿油、脚 7 NC。

## 6. 约定

- 硬件从 `design.py` 起手；`gen_pcb.py` 会清布线。
- 单位 mm。PCB：正面视角、原点左上、Y 向下。
- 提交前：`check_netlist.py`；有 KiCad 则 `export.sh --check-only`。
- 用户 Wisdom，回复中文。不要推翻 ADR。
- 许可证与 CI 见 [09-process.md](09-process.md)。

## 7. 历史：2026-09-14 旧板（不要当现板）

当时指纹：**57 件、564 段、128 过孔、J1.7 被后处理接到 GND**。复审证据在 `docs/reviews/2026-09-14/`。H2 已重布为 680/115，脚 7 空网；`apply_extra_gnd_pads` **禁止再把脚 7 接地**。

GND 缝合策略仍在 `route_pcb.py --skip-route`（现板应保持 680/115 幂等）。不要用「每个几何孤岛都打孔」或 `ZONE_CONNECTION_NONE` 那套已否决路径。

NFC 盖绿油的正确做法未变：只改 ANT1 SMD 的 Mask/Paste，不要为此 `gen_pcb.py`。

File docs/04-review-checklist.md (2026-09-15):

# 打样前人工复核清单

对照规格书逐项打勾。结论先写「通过 / 有风险 / 必须改」，再写页码或 URL。
`design.py` 是唯一事实来源；改脚序或电阻必须先改它再 `gen_schematic.py`。

**「还开着」= 还没拍板或还没实机，不是脚本没跑完。** 官方 GDEM042F86 规格书（2026-06-17，40 页）已对照。H2 规格项已落地，见 [08-h2-h3-questions.md](08-h2-h3-questions.md)。

已勾：USB 0.8 mm、脚 7 NC、RESE=2.2 Ω、ACTIVE_TOP=6.7、NFC 绿油。贴胶规格见 [09-process.md](09-process.md)（3M 467MP）。

仍要实机/生产授权的：电流、充电、USB 枚举、NFC 谐振、**生产 Gerber**（候选包不算）。

已用官方 PDF 勾掉：脚序（6/7=NC，8=BS1）、RESE=2.2 Ω、ACTIVE_TOP=6.7 mm（第 6 页机械图）。

调研日期：2026-09-13。GDEM042F86 官方 PDF 下载被站点 WAF 拦截，下列屏脚主要依据 **Waveshare 4.2inch e-Paper (G)** 用户手册（与 GDEM042F86 同外形 91×77、同 400×300 BWRY、同 24P 0.5 mm）。**打板前必须用佳显官方规格书复核。**

## 1. 屏幕 GDEM042F86 / 24P FPC

| 项 | 设计现状 | 调研结论 | 状态 |
|---|---|---|---|
| 外形 / 有效区 | 91×77×1.0，有效 84.8×63.6 | 与佳显产品页、Waveshare G 一致 | 通过（尺寸） |
| 驱动 IC | SSD2683ZA | 佳显产品页 | 通过 |
| 24P 脚序 | J1：2 GDR, 3 RESE, 5 VSH2, **7 NC**, 8 GND, 9 BUSY, 10 RST, 11 DC, 12 CS, 13 SCK, 14 MOSI, 15–16 VCI, 17 GND, 18 VDD, 20 VSH1, 21 VGH, 22 VSL, 23 VGL, 24 VCOM；NC = 1,4,6,**7**,19 | **GDEM042F86 第 7 页**：1/4/6/7 NC Keep Open。pin 8 接 GND = 4 线 SPI | **通过（H2 已按脚表：脚 7 空网）** |
| RESE（R14） | 2.2 Ω | 官方第 29 页参考电路 R2=**2.2 Ω**（RESE 到地） | **通过** |
| FPC 出线 | `FPC_SLOT=(27,77.6,57,79.6)`，J1 at (40, 73, 0) | 第 6 页：FPC 从短边下沿出，弯折区在屏下方。槽在板底、开口朝槽 | **通过** |

资料：

- 佳显产品页：https://www.good-display.com/product/1048.html
- 官方规格书 GDEM042F86（2026-06-17，40 页）：本机 `c:\Users\19612\Downloads\GDEM042F86.pdf`（版权文件，不入库）
- Waveshare G 手册（交叉核对）：https://files.waveshare.com/wiki/4.2inch%20e-Paper%20Module%20(G)/4.2inch_e-Paper_(G).pdf
- 不要用这份老 4.2" 规格（脚 6/7 是 TSCL/TSDA）：https://files.waveshare.com/upload/6/6a/4.2inch-e-paper-specification.pdf

## 2. USB-C TYPE-C-31-M-14

| 项 | 设计现状 | 调研结论 | 状态 |
|---|---|---|---|
| 型号 / LCSC | HRO TYPE-C-31-M-14，C223907 | 16P USB2.0 沉板母座 | 通过（选型） |
| 板厚 | `BOARD_THICKNESS=0.8` | 韩荣产品页写沉板 **0.75 mm**。嘉立创生产档只有 0.4/0.6/**0.8**/1.0/1.2/1.6/2.0，无 0.75。T&lt;1.0 mm 公差 ±0.1 → 下 0.8 实物 0.7–0.9，含 0.75 | **通过（拍板 0.8）**：2026-09-14 按嘉立创可做厚度打样，不换座。首件仍可量台阶 |
| 开口 | 板底边开槽，J3 at (75.0, BOARD_H-2.7) | 沉板中置，与外壳 USB 孔对准。外壳按 `PCB_T=0.8` | **通过（外壳 STEP）**：frame/cover vs USB 干涉 0 |

资料：LCSC C223907；https://en.krhro.com/Product-Details/728.html

## 3. LDO XC6220B331MR vs AP2112K

| 项 | 设计现状 | 调研结论 | 状态 |
|---|---|---|---|
| 符号 | `AP2112K-3.3` 符号，`U4` 取值 `XC6220B331MR-G` | SOT-25 脚序相同：1 VIN, 2 VSS/GND, 3 CE/EN, 4 NC, 5 VOUT | **通过（封装兼容）** |
| 电气 | 目标 Iq 8 µA、1 A | XC6220：1 A、PS 模式 ~8 µA；AP2112K：600 mA、~55 µA。BOM 主选 XC6220 正确 | 通过 |
| CE | 脚 3 接 `VBAT`，常使能 | 两颗都是高电平使能 | **通过** |

Torex XC6220 PDF：https://www.torexsemi.com/file/xc6220/XC6220.pdf

## 4. FPC 连接器 FH12-24S-0.5SH

| 项 | 设计现状 | 调研结论 | 状态 |
|---|---|---|---|
| 型号 | Hirose FH12-24S-0.5SH 或 JUSHUO AFC07-S24FCA-00，LCSC C262657 | 0.5 mm、24P、**Bottom contact**、前翻盖 ZIF、高 2.0 mm | 通过（型号） |
| 开口方向 | 元件在 B.Cu，J1 在槽上方 | Bottom contact：FPC 导电面朝 PCB。插拔方向应朝板下缘 `FPC_SLOT` | **通过（2026-09-14 3D）**：棕色翻盖朝槽，焊脚朝 ESP。图：`output/j1_back_close.png`、`j1_from_slot.png`。不用转 180° |
| FPC 厚度 | 未在设计里写 | FH12 推荐 0.30 mm FPC | 买屏时确认补强厚度 |

Hirose FH12：https://www.hirose.com/product/series/FH12

## 5. 外壳开窗 `ACTIVE_TOP`

| 项 | 设计现状 | 调研结论 | 状态 |
|---|---|---|---|
| `ACTIVE_TOP=6.7` | `design.py` → 外壳 | 官方第 6 页：外形 91.00×77.00×1.00，AA 84.80×63.60，左右各 **3.10**。竖直方向 AA 居中：(77−63.60)/2 = **6.70**。旧值 4.5 会挡住画面顶约 2.2 mm | **已改为 6.7**（2026-09-14） |

水平：左右各 (91-84.8)/2 = 3.1 mm，脚本用 `(PANEL_W-ACTIVE_W)/2`，与此一致。

## 6. 其它打样项（未在本轮展开）

- USB D+/D− 是否等长：Freerouting 结果能用但不好看，C3 全速不严格要求差分。
- 升压回路 L1/Q1/D1/C16 尽量短（已集中在 24–43, 57–65 一带）。
- 电池仓无零件（B.Cu rule area）。
- NFC 线圈盖绿油（ANT1 SMD 无 Mask；通孔 pad 2 仍开窗）。光线追踪里线圈是**绿的**（油盖铜），不是黄的；黄 = 露铜。圈内小黄点是通孔。铜皮 11 圈仍在，见 `output/nfc_coil_close.png`。
- 外壳脚本从 `design.py` 读 SW1/SW2、FPC 槽、电池仓、LED（2026-09-14 已按 PCB 对齐：BOOT `(22.5, 80.5)`，槽 `(27,77.6,57,79.6)`）。
- 屏贴胶：首件 **3M 467MP**（0.06 mm），只贴非 AA 边框。PETG 粘框用 300LSE。见 `docs/09-process.md`。

## 7. 建议的「通过才下单」门槛

1. ~~USB-C 沉板与 0.8 mm 板匹配或改料号~~：已拍板 0.8，见第 2 节。
2. 脚 7：官方 NC Keep Open，**H2 已空网**。不要再缝 GND。
3. ~~FH12 开口朝槽 / NFC 盖绿油 / ACTIVE_TOP=6.7 / RESE=2.2 Ω / 贴胶 467MP~~ 已写进 BOM 与 `docs/09-process.md`。
4. 生产包仍须 Wisdom 授权；CI 绿和全量 DRC 0 都不是下单文件。

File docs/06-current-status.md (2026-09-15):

# BADGE-42C 当前状态与接手入口

更新：2026-09-15 **H2 规格已按授权改到板上**（动线已完成）。H1 门禁仍有效。2026-09-14 复审档案仍是旧 57 件/564 段板的证据，不要和当前工程混读。

**当前阶段：硬件全量已过（KiCad 10.0.6）；固件 F1 源码已改（v0.2）。** error 级与全量 ERC/DRC 均为 0。没有生产 zip。不要把候选 Gerber 当下单包。F1 无实机。

## 先看哪些文件

1. [AGENTS.md](../AGENTS.md) → [原交接](03-handoff.md) → [架构决策](01-architecture-decisions.md)：既有约定和决定仍有效。
2. [本机独立复审](reviews/2026-09-14/local-review.md)：本轮工具执行、结果、证据边界及新发现。
3. [外部审查原文](reviews/2026-09-14/external-review.md)：用户提供，逐字归档；其中建议不是修改指令。
4. [合并整改计划](reviews/2026-09-14/integrated-plan.md)：F01–F20及N01/N02的入口、顺序、关闭标准、实物操作单。
5. [审查工具执行手册](../tools/review/README.md)：Cursor/Codex可直接复跑的命令、预期返回、失败处理。
6. [证据索引](reviews/2026-09-14/evidence/README.md)：原始JSON、日志、预览及SHA256清单。
7. [r2 复跑](reviews/2026-09-14-r2/rerun.md)：新隔离目录复跑；结论与首轮一致，缺陷仍未修。
8. [缺陷修复项目（先硬件后固件）](07-defect-fix-project.md)：未修项、注意点、H1/F1 提示词。
9. [H2/H3 拍板记录（已关闭）](08-h2-h3-questions.md)、[流程（许可证/CI/贴胶/生产包）](09-process.md)、[全量 warning 登记](hardware/drc-warning-register.md)。

## 已完成与验证到什么程度

| 模块 | 状态 | 本轮结果 | 未覆盖 |
|---|---|---|---|
| 架构 | 已决策 | 四色屏/ESP32-C3/ST25DV/电池+USB/0.8mm保持 | 不把审查当改架构授权 |
| 原理图 | 本机检查通过（全量） | **58** 元件；KiCad 10.0.6 全量 ERC 0；网表与 design.py 一致；J1.7 **NC**；U2 用 `Badge:ST25DV64KC-SO8N` | 未做电气模拟 |
| PCB | 本机检查通过（全量） | 91×84×0.8mm，两层，全在B.Cu，**680段/115过孔**；全量 DRC 0、未连接 0、parity 0；Power 走线≥0.3mm（GND靠铺铜）；NFC 0.5mm；USB_DP/DN 分网 | 旧 564/128 仅备份；未跑 gen_pcb 清线 |
| GND后处理 | H2 重布后幂等 | `--skip-route` 保持 680/115；J1.7 不再接地 | 不等于任意新布局均可靠 |
| 制造输出 | 档案仍旧；候选目录 | 旧 ZIP 与 `output/gerbers` **未改**；`export.sh --check-only` 已过 | 候选 ≠ 生产包 |
| 三维输出 | 包络已就位 | J3/J2 仓库包络 STEP 存在；`--fail-missing` 0；包络 ≠ 官方 CAD | 装配干涉不能只靠包络 |
| 外壳 | 本机几何验证 | 未因 H2 重做外壳 | FPC/胶/实电池仍未测 |
| 固件构建 | v0.2 源码 | F01/F02/F09 已改；`host_probes` 新期望（仅 normal 成功）；勿覆盖 v0.1 bin | 无烧录、USB 或实屏；pio 构建见本机日志 |
| 自检/显示/深睡 | 源码已修，待实机 | 深睡仅 GPIO1；刷白用串口 W；BUSY 恒高/关电超时报失败 | 实屏 BUSY、深睡电流、NFC 真场未测 |
| NFC | 最小探测已实现 | 仅I²C ACK探测 | 身份/事件配置、NDEF、FTM、手机传图均未完成 |
| 流程/文档 | 已对齐现板 | 许可证、CI、贴胶、交接不再写 564/脚7GND 当现状 | CI 不是 DRC；无生产 zip |

状态词严格区分：**已决策**是用户选择；**已实现**是有代码/设计；**已构建**是编译成功；**本机验证**是明确的软件/几何检查；**实机通过**需要真实设备及条件。本轮没有任何新增“实机通过”项，不使用虚构完成百分比。

## 现在最难、最先处理的事项

1. **有板后：** USB 枚举、充电、BUSY 波形、NFC 装机、电流。F1 源码不能替代实装。
2. **固件 F2：** NDEF/FTM 收图（须 Wisdom 选定一条路线）。
3. **不要**把候选 Gerber 当生产包。

建议执行顺序（审查原文）：固件与检查门禁 → 硬件待决项/规格冻结 → …  
**Wisdom 已指定先硬件后固件**，排期见 [07-defect-fix-project.md](07-defect-fix-project.md)。具体验收见合并计划。

## 给新会话的可直接粘贴任务

```text
继续 BADGE-42C。先读 AGENTS.md、docs/06-current-status.md、docs/03-handoff.md。
始终中文。H2 铜皮已落地（680/115，J1.7 NC），不要再问 F06/N01 拍板。
不要因为 DRC error 0 声称可以下生产包。不要把候选 Gerber 当生产包。
不要覆盖用户已有 tools/freerouting。F1 源码已改，不要再当未修缺陷去改 GPIO9。
下一步默认：有板实测；F2 须 Wisdom 选定 NDEF/FTM 路线。
提交前 check_netlist.py 和 export.sh --check-only。未经明确要求不要建 PR。
```

历史交接里的 564 段表已收进 [03-handoff.md](03-handoff.md) 第 7 节，不要当现板。本文是审查状态入口，不修改已接受的架构决定。

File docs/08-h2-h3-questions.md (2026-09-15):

# H2/H3 拍板记录（已关闭）

日期：2026-09-15。本文是**决定日志**，不是待办问卷。不要再按文末「请选 A/B」执行。

**Wisdom 授权（同日）：矫枉必须过正。** USB 0.8 mm 与 NFC 线圈盖绿油保持已决策，不重开。

现板：**58 封装、680 段 / 115 过孔**，KiCad 10.0.6 全量 ERC/DRC 0。旧 564/128 备份 `agent-tools/badge-pre-h2.kicad_pcb`。仍禁止把候选 Gerber 当生产包。

流程口径（C11 DNP、USB 不重布、贴胶）见 [09-process.md](09-process.md)。

## 已落地

| 编号 | 决定 | 板上事实 |
|---|---|---|
| F06 | 跟第 7 页：脚 7 **NC Keep Open** | `design.py` pin 7 进 `nc`；`apply_extra_gnd_pads` 禁止再接地 |
| N01 | 跟第 29 页升压 | L1=47µH FNR4018S470MT；C15=4.7µF/25V；R15=1M；Q1=Si1308EDL；R14=2.2Ω 0603 |
| F07 | 跟 Torex 3.3V 表 | 近端 CIN C3=10µF、CL C4=4.7µF |
| F17 | 锁一颗充电器 + 电芯 | U3=**TP4054** C32574；202545 250mAh 2.0mm 带 PCM；J2-1=VBAT |
| F05 | 强制最小宽度 | Power 0.3 mm、NFC 0.5 mm，不够宽已重布 |
| F03 | 禁止假续航 | ADR 待机为待测，禁止写 13µA/两年 |
| F16 | 包络 3D | `lib/3d/` 有 J3/J2 仓库包络 STEP。包络 ≠ 官方 CAD |
| F14 | C11 | 首件 **DNP**，SMT 不贴；封装仍 0402；测谐振后再填 |
| F13 | USB | 只做路径笔记。**未批准不要重布** |

原问卷（方案 A/B、旧料号 68µH / C3=1µF 等）是授权**之前**的证据，已过期。需要对照当时论证时读 [local-review.md](reviews/2026-09-14/local-review.md)，不要把那些表里的「当前设计」当成现板。

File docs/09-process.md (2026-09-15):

# 流程（许可证、CI、贴胶、生产包）

日期：2026-09-15。把「文档和板上事实打架、没有 CI、没许可证、没贴胶规格」从口头债变成可执行约定。架构仍以 [01-architecture-decisions.md](01-architecture-decisions.md) 为准。

## 1. 许可证

见根目录 [LICENSE.md](../LICENSE.md)。硬件 **CERN-OHL-P-2.0**，固件/脚本/文档 **MIT**。第三方库保持原许可。要改成 CERN-OHL-W/S 必须 Wisdom 改 `LICENSE.md`。

## 2. 文档哪份是当前板

| 文件 | 角色 |
|---|---|
| [AGENTS.md](../AGENTS.md) | 硬性约定 + **当前** 进度一行表 |
| [06-current-status.md](06-current-status.md) | 审查状态入口 |
| [03-handoff.md](03-handoff.md) | 复现步骤与**当前**板指纹（680/115） |
| [08-h2-h3-questions.md](08-h2-h3-questions.md) | **已关闭的拍板记录**，不是待办问卷 |
| [reviews/2026-09-14/](reviews/2026-09-14/) | 旧 57 件 / 564 段板的证据档案，不要当现板 |

正文里再写「57 元件 / 564 段 / 脚 7 GND / v0.1 BOOT 刷白」即为过期，应改或标成「历史」。

## 3. CI（GitHub Actions）

工作流：[`.github/workflows/ci.yml`](../.github/workflows/ci.yml)。依据 [PlatformIO GitHub Actions](https://docs.platformio.org/en/stable/integration/ci/github-actions.html)，并按 ESPHome 做法把 `platformio.ini` 哈希放进 cache key。

CI **会做**：Python 编译、`check_netlist.py`、`host_probes`、钉死版本的 `pio run`、确认 v0.1 三份 bin 仍在且应用 296 512 B。

CI **不会做**：KiCad 全量 ERC/DRC、Freerouting、生产 Gerber、实机。那些仍须本机 KiCad **10.0.6**。CI 绿 ≠ 可以下单。

固件钉死：`espressif32@7.1.3` + CI 里 `platformio==6.2.0`（本机 v0.2 构建）。espressif32 7.x 不要搭配 Core 6.1.18。

## 4. 生产包 vs 候选包

- `export.sh` 默认写入 `output/exports/<stamp>-candidate/`。**候选 ≠ 生产。**
- 覆盖 `output/gerbers` 或 `output/badge_gerbers.zip` 必须有 Wisdom 书面「生产包」授权，并带 commit、KiCad 版本、BOM、全量 ERC/DRC 报告 SHA。
- 旧 zip 若 B.Silk 与现板不一致，禁止当下单文件。

## 5. 屏贴胶（首件）

屏 FR4 背面贴到 PCB 正面（元件在 B.Cu）。佳显未公布指定胶带；按 3M 图形/铭牌粘接惯例锁首件料：

| | 规格 |
|---|---|
| 主选 | **3M 467MP**（200MP 丙烯酸转移胶，标称 **0.06 mm / 2.3 mil**） |
| 为什么 | 金属与高表面能塑料（FR4、ABS）常用；薄，不顶高 6.3 mm 叠层。数据页：[3M 467MP](https://multimedia.3m.com/mws/media/1854916O/3m-adhesive-transfer-tape-467mp.pdf) |
| 贴法 | 只贴 **非 AA 边框**：左右各 3.1 mm、顶/底各 6.7 mm 里靠外侧的一圈，**不要**贴到 84.8×63.6 有效区、FPC 根、线圈对应区域加厚块 |
| PETG 后盖/前框若粘不牢 | 改 **3M 300LSE**（低表面能，0.06–0.13 mm）。前框是 3D 打印 PETG/ABS 时优先考虑 300LSE 粘框、467MP 贴屏到 PCB |
| 禁止 | 泡棉胶把屏顶离 FPC 翻盖工作行程；丙酮类清洗液碰屏 |

未指定宽度的裁切：用 6–8 mm 宽转移胶条沿边框，总胶厚按 **0.06 mm** 计入装配，不改 `ACTIVE_TOP`。

## 6. C11 / USB 走线（流程口径，不是改板）

- **C11**：首件 **DNP**，SMT 按装配 BOM 不贴。封装保持 0402。测谐振后再填容值并记调谐表。
- **USB**：不把网络总长差当差分失配去重布。未批准不要 Freerouting USB。

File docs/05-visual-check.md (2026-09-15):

# 3D / 截图：先分清「拍错了」还是「板上真有问题」

给 Wisdom 和之后任何模型。**3D、渲染、截图看不清时，禁止直接说「没法 100% 断定」或把猜测当板上问题。**

每次遇到「图上看起来不对 / 不确定插口朝哪 / 字是不是叠了」这一类问题：

1. **先读本文**（含下面的案例）。
2. **再查源文件**：`hardware/pcb/scripts/design.py`（事实来源）、`badge.kicad_pcb` 焊盘/丝印坐标、必要时封装 3D。
3. **证据要对准目标**。近景必须能认出那个元件；拍到绿油、过孔、电池仓角，等于没拍。
4. 自己先下结论，只分两种：

| 判定 | 你怎么做 |
|---|---|
| **拍错了**（相机/pivot/镜像/看的层不对） | 自己重拍、自己核对。不要当成板上缺陷去问，更不要动铜皮。 |
| **板上真有问题** | **先问 Wisdom，讨论后再改。** 不要自行 `gen_pcb.py` / 重布。 |

不确定就再拍一次、再对一次坐标，直到能指着图说清。还是分不清，把「源文件怎么说 / 图上看到什么 / 还缺哪一张对准的图」一起问，不要用含糊句结束。

新踩的坑写进本文「案例」节，再推 GitHub。不要只留在对话里。

---

## 渲染怎么才算拍到了

元件全在 **B.Cu**。看背面用 `kicad-cli pcb render --side bottom`。

- 板 91×84 mm，中心约 `(45.5, 42)` mm。
- `--pivot` 是相对板中心、单位 **厘米**。PCB Y 向下；3D 的 Y 通常相反。
- 目标 `(x, y)` mm：`dx = (x - 45.5) / 10`，`dy = -(y - 42) / 10`。
- 例：J1 `(40, 73)` → `--pivot "-0.55,-3.1,0"`，`--zoom 7`～`10`。
- 交图前自检：图上要有目标丝印/外形（如 `J1`、棕色翻盖），不能只是一块绿油。

Windows：`%LOCALAPPDATA%\Programs\KiCad\9.0\bin\kicad-cli`。图放 `hardware/pcb/output/`（`render_back.png`、特写另存）。

全板背面看不清细节时，必须再出一张 **对准的特写**，不能靠全板缩略图下机械结论。

---

## 案例

以后同类事先对这两条。新案例往下追加。

### 2026-09-14 J1 翻盖哪边是插口

- **当时说法**：「3D 没法 100% 断定翻盖哪边是插口。」
- **实际**：第一次近景 pivot 没对准 J1，拍到的是绿油和过孔。**拍错了，不是座子装反。**
- **源文件**：`J1 at=(40.0, 73.0, 0)`，槽 `FPC_SLOT=(27.0, 77.6, 57.0, 79.6)`。FH12 棕色是翻盖，FPC 从翻盖侧插入。
- **对准后的图**：银色焊脚朝 ESP，棕色翻盖朝槽。开口朝槽，**不用转 180°**，不用重布。
- **教训**：没拍到目标就不能下「不确定 / 可能要转 180°」这种结论。

### 2026-09-14 NFC 线圈 3D 不黄

- **当时**：Wisdom 红框里的线圈是黄线，重渲的 `render_back.png` 没有黄线。
- **实际**：铜皮还在，**不是拍丢、也不是线圈没了。** ANT1 pad 1 仍是 11 圈螺旋，现板层只有 `"B.Cu"`（无 Mask）。盖绿油之后，实物和光线追踪里线圈被阻焊盖住，看起来是绿的；黄/金 = 开窗露铜（沉金）。圈内那颗小黄点是仍开窗的通孔 pad 2。
- **你红框里发黄**：多半是 KiCad 3D/编辑器按铜层颜色画（B.Cu 默认偏黄），或盖绿油之前那版渲染。`kicad-cli pcb render` 默认 `follow_plot_settings`，按加工后外观画，所以不黄。
- **对准的图**：`hardware/pcb/output/nfc_coil_close.png`（绿线圈 + 一颗金通孔）。
- **教训**：3D 少了「铜的黄」先对 Mask：有铜无窗 = 应该绿。不要为了渲成黄色去把 Mask 加回去。

### 2026-09-14 FreeCAD 装配全灰、不像板渲染

- **当时**：Wisdom 把 FreeCAD `badge_assembly.FCStd` 和 KiCad `render_back.png` 并排：装配灰、正视、几乎看不出零件；板渲是绿油+元件。
- **实际**：**不是没开对功能，也不是外壳没做。** 图2 是 `kicad-cli pcb render` 光线追踪（只渲 PCB）。图1 是机械装配：前框/后盖按 3D 打印件做成深灰实体，用来对尺寸和干涉，不是产品效果图。脚本里有颜色（框深灰、屏米色、板绿），但 `freecadcmd` 无 GUI，`ViewObject.ShapeColor` 写不进 `.FCStd`，打开就全是默认灰。选中零件会变成亮绿（FreeCAD 选中色），不是屏本身是绿的。
- **怎么看**：关掉右侧 Transform；右上导航立方点角变成斜视，或中键拖旋转。左侧树：`FrontFrame` / `BackCover` / `EPaperPanel_4p2` / `PCB_from_KiCad` / `LiPo_2mm`，取消勾选就能透过看。板外观仍以 `hardware/pcb/output/render_back.png` 为准。
- **教训**：FreeCAD 装配素 ≠ 外壳没设计。要看绿油/丝印/线圈用 KiCad 渲染；要看开窗/USB/按键孔用 FreeCAD 转角度、开关零件。

### 2026-09-14 B.Silk 叠字（BOOT / 芯片说明）

- **当时**：Wisdom 在 `render_back.png` 上标了红箭头。
- **实际**：**板上真有问题。** `ESP32-C3 + ST25DV64KC + 4.2" BWRY` 写在 `y=73.2`，和 J1 `(40, 73)` 同一高度，字穿座子；`SW1`/`SW2` 位号又压在 `RST`/`BOOT` 上。
- **改法**（只动丝印，**没跑 `gen_pcb.py`**）：坐标收到 `design.py` 的 `SILK_BACK`；现板改 `gr_text`；隐藏 SW1/SW2 位号。
- **教训**：用户标了图，先对 `badge.kicad_pcb` 里的 `gr_text` / footprint `Reference`，不要猜是不是渲染看错。真叠字就拿图和坐标一起问，再改。

---

### 2026-09-14 本机复审：缺少3D模型不等于缺少PCB封装

- KiCad9.0.8对准全板和J1重拍后，J1开口仍朝FPC槽，NFC铜仍盖阻焊。J3和J2在图中无完整连接器外形，先检查源模型引用：J3的项目USB STEP不存在；J2所引用STEP在本机官方9.0.8模型库无法解析。
- `pcb_audit.py`直接读取仍有57个封装，J2/J3焊盘和网络存在。`step.log`明确记录无法添加这两个模型，但导出命令仍返回0；不是“板上没放连接器”。
- 新STEP下交叠体积0也无法检查不存在的实体。先补模型来源与覆盖检查，再谈实装结论。证据见 `docs/reviews/2026-09-14/evidence/`，本轮没有修改封装或板。
- 同轮尺寸检查：`GetBoardEdgesBoundingBox()`包含Edge.Cuts线宽得到91.1×84.1mm；板框中心线实际91×84mm。核对几何后再判断尺寸，不为包围盒笔画修改板框。

### 2026-09-15 底边绿色方块 = J3 USB-C 包络，不是多出来的元件

- **当时**：3D 里 USB 槽口伸出一块亮绿长方体，看起来不像座子。
- **实际**：**拍到了目标，板上也没有多焊一颗方块料。** 那是 `J3`（HRO TYPE-C-31-M-14 沉板 USB-C）的 **包络 STEP**：`lib/3d/TYPE-C-31-M-14.step`，`make_envelope_3d.py` 按 8.94×7.3×3.25 mm 做的盒子。H2 补模型门禁用，**不是韩荣官方外形**。焊盘和开槽仍在 `badge:TYPE-C-31-M-14` 封装上。
- **源文件**：`J3 at=(75.0, BOARD_H-2.7, 0)`，即约 `(75.0, 81.3)`，底边 USB 槽。旁边 `CHG`/`STAT` 是 D4/D5，不是这块绿方。
- **教训**：缺官方 CAD 时 3D 会显示占位盒子。要看真 USB-C 外形，换官方 STEP 或看实物/datasheet；不要按绿方去改封装或铜皮。

## 不要做的事

- 近景没对准就说「3D 看不清」。
- 把拍错当成要改封装、要 `rot=180`、要 Freerouting。
- 确认是板上问题之后不讨论就改铜皮/布线。
- 同类错误只在聊天里认，不写进本文。

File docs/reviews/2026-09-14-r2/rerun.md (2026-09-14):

# BADGE-42C 审查复跑（2026-09-14-r2）

日期：2026-09-14 23:44（UTC+8）。隔离目录：`agent-tools/review-20260914-234456`（gitignore，不入库整包）。

**工作包：** 按 `tools/review/README.md` 在新目录复跑审查与测试文档。不修产品固件/硬件缺陷，不跑 `gen_pcb.py`，不跑 Freerouting，不覆盖 [2026-09-14 归档证据](../2026-09-14/evidence/README.md)，不发布生产包。本地 `hardware/pcb/badge.kicad_pro` 与 `tools/freerouting/` 未改、未提交。

审查输入 HEAD：`11ab832815d8f10327e432e152d641957101a5e1`。硬件/固件内容仍对齐 [ee978f0](https://github.com/wisdom-km/chroma-badge/commit/ee978f08cbdb7b61bbe2c78fea0e9c7cd2c34a7b)。F01–F20 / N01 / N02 关闭标准仍见 [integrated-plan.md](../2026-09-14/integrated-plan.md)；本轮没有把任何项改成“已修复”或“实机通过”。

## 1. 本机工具

| 工具 | 本轮 |
|---|---|
| KiCad | 9.0.8，`D:/chroma-badge/agent-tools/kicad-9.0.8`（审查用独立安装，不因 PATH 上的 10 改版本） |
| 用户 KiCad | 亦存在 `%LOCALAPPDATA%\Programs\KiCad\9.0`；本轮 CLI 用 agent-tools 副本 |
| FreeCAD | 1.1.3，`D:/FreeCAD/bin/python.exe` |
| PlatformIO | 6.2.0，`D:/PlatformIO/penv/Scripts/pio.exe` |
| 主机 g++ | MinGW 13.1.0 |
| Git Bash | `G:/BaseWare/Git/bin/bash.exe` |

`prepare.py` 快照使用 **HEAD 的** `.kicad_pro`；工作区未提交工程文件另存为隔离目录内 `local-project.kicad_pro`。

## 2. 正常路径（本机软件/几何）

这些只证明当前数据在本机工具下可重复，**不是** 生产通过或实机通过。

| 路径 | 结果 |
|---|---|
| error 级 ERC | 0，CLI 0 |
| error 级 DRC | 0 错误、0 未连接，CLI 0 |
| 新网表 + `check_netlist.py` | 通过；57 元件、41 功能网络 |
| 原理图/NFC 生成器副本 | 成功；`gen_pcb.py` **未执行**；NFC 封装忽略换行后相同 |
| `--skip-route` 两次 | 三次快照均为 564 段 / 128 过孔；指纹 `2d96f2751cfe29874e19817df79bebdc1da593ffc553671f2aa7306423b1d7c4`，与 2026-09-14 轮相同 |
| 干净固件构建 | SUCCESS；RAM 15312、Flash 283588；三份 bin SHA256 与仓库 `firmware/output` 一致 |
| EPD 替身 **normal** 四色 | 各 30000 字节，编码 00/55/AA/FF，请求关电 |
| FreeCAD 外壳重建 | 94×93×6.3 mm；扩展 10 组交叠 0（新旧 STEP 各一次） |
| 诊断 Gerber/钻孔/BOM/STEP/渲染 | 各 KiCad 命令返回 0（诊断用，不是下单包） |

## 3. 故障路径（旧缺陷仍复现）

`host_probes` / `fault_probes` 通过 = **缺陷被再次抓住**，不是产品正确。

| 路径 | 结果 | 对应项 |
|---|---|---|
| 全量 ERC + DRC+parity | 审查程序返回 **1**；全量 ERC 1 warning（`lib_symbol_issues`）；DRC 148 warning（57+1+6+62+22） | 不得写成“所有检查通过” |
| BUSY 恒高 / 关电超时 | 四色均 `reported_success=true` | F09 未修 |
| `drc_json` 注入返回码 5 | 读回带 `OLD_REPORT` 的空旧报告 | F19 |
| `export.sh` ERC 失败 | 脚本退出 5，未到 Gerber | ERC 可阻断 |
| `export.sh` DRC 失败 | Gerber 哨兵 99，**已走到** `pcb export gerbers` | F04，`\|\| true` |
| 原 `export.sh` 在 Git Bash | `python3` 不存在，退出 127，未到制造导出 | 原入口本机仍不可作为发布路径 |
| 背面丝印归一化比较 | 13 份中 12 份相同，`badge-B_Silkscreen.gbr` **不同** | N02 仍在 |
| J3/J2 3D 模型 | 源 STEP 缺失/官方库无法解析；完整 STEP 命令仍返回 0 | F16；缺模型不是板上没封装 |

F01 GPIO9 深睡、F02 BOOT 入口冲突、F06 J1.7、N01 升压差异：**未改代码，状态仍为未修复/待讨论。**

## 4. 未覆盖的实物场景

本轮 **没有** 板、屏、电池、手机、示波器、电流表、VNA。下列全部仍是 [操作单](../2026-09-14/integrated-plan.md) 第 4 节未执行项：

首次供电、USB 枚举/烧录、LDO 波形、EPD 真刷新、NFC/GPO、深睡 100 次、传图、充电温升、装机 RF、FPC/胶/真电池装配、续航电荷。

主机毫秒是替身时钟，不是屏实测。

## 5. 给 Wisdom 仍待讨论（未改板）

与首轮相同，本轮只重复证据，不代替批准：J1.7 Keep Open vs GND；升压 L1/C15/GDR/Q1；XC6220 近端电容；续航 13 µA 叙述；全量 warning 豁免表；是否重建同步制造包（N02）。

## 6. 结论

工程样机闭环验证阶段不变。error 级 DRC 0 **且** 全量 warning 148 **同时成立**。产品缺陷未修。诊断导出不是生产发布。下一工作包仍是计划阶段 A（A1 固件错误可见，或 A2 导出门禁），需 Wisdom 明确授权后才改产品代码或 `design.py`。

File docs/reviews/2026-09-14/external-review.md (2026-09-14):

# chroma-badge / BADGE-42C 详细审查报告

审查日期：2026-09-14  
基准提交：[ee978f08cbdb7b61bbe2c78fea0e9c7cd2c34a7b](https://github.com/wisdom-km/chroma-badge/commit/ee978f08cbdb7b61bbe2c78fea0e9c7cd2c34a7b)  
范围：项目定位、设计数据、原理图导出网表、PCB文本、制造输出、固件、外壳脚本、工程复现与后续软件闭环。

## 1. 结论

项目已经具备实质性的工程样机设计基础：4.2寸四色屏、ESP32-C3、ST25DV、参数化PCB与外壳、制造输出，以及最小上电自检固件。保留现有总体架构是合理的。

当前最需要投入的是跨模块验证与首件闭环。仓库已有“设计数据一致、已保存的错误级ERC/DRC报告为空”的证据，但尚不足以支持“稳定唤醒、可靠刷屏、完整手机传图、年级别续航、可直接交付生产”的判断。

本次发现的关键问题：

1. GPIO9被配置为ESP32-C3深睡唤醒脚；配置返回值被忽略。
2. 文档要求按住BOOT复位触发刷白，实际与ROM下载模式冲突。
3. SO8封装ST25DV常供电的待机电流，被误按低功耗模式估算。
4. ERC/DRC没有作为制造导出的可靠阻断条件。
5. design.py声明的Power/NFC网络规则未落实到工程。
6. 屏幕pin 7接地与仓库引用的Keep Open要求存在未关闭的偏离。
7. 更换LDO后，稳定性验证仍主要停留在引脚兼容。
8. “NDEF打开网页”和“网页经FTM传图”之间存在平台能力缺口。

这些发现不意味着整块板必须推倒重来；它们意味着需要在冻结下一版之前，把明确的软件缺陷和硬件验证缺口逐项关闭。

## 2. 本次实际完成的核查

| 核查 | 结果 | 能证明什么 |
|---|---|---|
| 固定提交并读取仓库树 | 90个已跟踪文件，包含输出件 | 审查版本可定位 |
| 读取项目文档与关键源码 | 9个Python文件、3个C++文件，以及头文件、配置与导出脚本等 | 覆盖主要实现链 |
| 运行原check_netlist.py | 通过；解析63个原理图网络，其中设计有41个功能网络，其余包含未连接脚网络 | 已提交网表与design.py一致 |
| 独立解析PCB文本 | 57个封装、564段走线、128个过孔，全部封装在B.Cu | 与仓库进度记录一致 |
| 比较PCB焊盘网络与design.py | 预期连接引脚未见网络不一致或缺少焊盘；显式NC脚未见接入功能网络 | 验证引脚网络分配，不等于验证实际铜连接与电气功能 |
| NFC封装层检查 | 线圈主体在B.Cu，无Mask；桥在F.Cu，通孔保留Mask | 支持“线圈铜仍在、已盖阻焊”的记录 |
| Python AST语法检查 | 9个Python文件通过 | 只证明语法可解析 |
| 导出脚本故障注入 | 模拟DRC返回5，原脚本仍进入Gerber导出 | 已复现导出门禁缺陷 |
| ZIP更新行为实验 | 旧文件从目录删除后仍残留于旧ZIP | 已复现制造包残留风险 |
| 原epd.cpp主机模拟 | BUSY恒高、关电BUSY超时两种情况下均返回成功 | 已复现驱动错误状态表达不足 |
| 官方资料对照 | Espressif、ST、Torex、KiCad、Chrome | 支撑引脚、功耗、稳定性、导出与平台限制判断 |

本环境未安装KiCad、pcbnew、FreeCAD或PlatformIO，且没有实物。因此没有重新运行完整ERC/DRC、目标固件构建、3D布尔干涉、射频、充电或实屏测试。仓库中的既有ERC/DRC记录只覆盖error级别；不能把它表述成所有告警均已消除。

屏幕官方规格下载页可以访问，但本次没有取得仓库所引用的2026-06-17完整规格书。涉及pin 7及驱动时序的判断，分别明确使用仓库自述证据或标为待厂商/实测确认。

## 3. 优先修复的问题

优先级定义：P1为冻结设计或扩展功能前应关闭的问题；P2为首件验证、可靠性与维护改进；P3为后续产品化。优先级与证据强度分开，不把“风险”写成“已实测故障”。

### F01｜P1｜深睡唤醒配置包含不支持的GPIO9

**证据：** [main.cpp](https://github.com/wisdom-km/chroma-badge/blob/ee978f08cbdb7b61bbe2c78fea0e9c7cd2c34a7b/firmware/src/main.cpp) 第31–42行，将NFC_GPO与BOOT_n一起组成唤醒mask；[pins.h](https://github.com/wisdom-km/chroma-badge/blob/ee978f08cbdb7b61bbe2c78fea0e9c7cd2c34a7b/firmware/include/pins.h) 将二者分别定义为GPIO1和GPIO9，调用后没有检查返回值。

ESP32-C3深睡支持的RTC GPIO为0–5，GPIO9不在其中。官方API明确：mask包含无效深睡引脚时返回ESP_ERR_INVALID_ARG。[GPIO说明](https://docs.espressif.com/projects/esp-idf/en/v4.4.8/esp32c3/api-reference/peripherals/gpio.html)、[睡眠API](https://docs.espressif.com/projects/esp-idf/en/v4.4.8/esp32c3/api-reference/system/sleep_modes.html)。

**影响：** BOOT不能按当前方式唤醒深睡。在所核对的ESP-IDF v4.4.8实现中，循环检查到GPIO9后提前返回，最终GPIO唤醒源使能语句不会执行；因此不能假设GPIO1仍可正常唤醒。固件也没有计时唤醒兜底。[官方实现](https://github.com/espressif/esp-idf/blob/v4.4.8/components/esp_hw_support/sleep_modes.c)。

**建议：** 当前硬件先只启用GPIO1深睡唤醒并检查错误；RESET保持作为恢复入口。若用户键必须唤醒深睡，应重新分配支持的引脚，或另行评估light-sleep的功耗代价。记录复位原因、唤醒原因以及失败原因。

**验收：** 唤醒配置返回ESP_OK；反复休眠/触碰可恢复；没有NFC事件时维持稳定待机；无效配置不能打印“唤醒已就绪”。

### F02｜P1｜刷白自检入口与BOOT下载模式冲突

**证据：** [firmware/README.md](https://github.com/wisdom-km/chroma-badge/blob/ee978f08cbdb7b61bbe2c78fea0e9c7cd2c34a7b/firmware/README.md) 的上电步骤要求“按住BOOT复位”；[main.cpp](https://github.com/wisdom-km/chroma-badge/blob/ee978f08cbdb7b61bbe2c78fea0e9c7cd2c34a7b/firmware/src/main.cpp) 第68–73行在setup中等待这个条件。

GPIO9复位时为低会进入ROM下载模式，应用通常不会运行到setup。[Espressif启动模式](https://docs.espressif.com/projects/esptool/en/latest/esp32c3/advanced-topics/boot-mode-selection.html)。

**建议：** 正常复位后设置一个明确的短暂用户输入窗口，或使用串口命令启动显示自检。BOOT下载操作与应用自检操作分别说明。不要依赖用户卡准启动采样后的几十毫秒。

**验收：** 按文档操作能稳定触发自检；下载固件入口保持可用；串口输出能区分下载模式、正常启动与自检状态。

### F03｜P1｜待机预算错误地套用了ST25DV低功耗模式

**证据：** [design.py](https://github.com/wisdom-km/chroma-badge/blob/ee978f08cbdb7b61bbe2c78fea0e9c7cd2c34a7b/hardware/pcb/scripts/design.py) 中U2为SO8器件，VCC直接接+3V3；[ADR](https://github.com/wisdom-km/chroma-badge/blob/ee978f08cbdb7b61bbe2c78fea0e9c7cd2c34a7b/docs/01-architecture-decisions.md) 2.4节按ST25DV小于1µA、整机约13µA推算约两年待机。

ST规格书说明LPD功能仅在10-ball/12-pin封装提供；表249给出常供电静态待机在3.3V下典型约76µA。不能将本SO8设计视为已进入LPD模式。[ST25DVxxKC规格书，第7页及第141页](https://www.st.com/resource/en/datasheet/st25dv64kc.pdf)。

采用仓库的ESP32 5µA假设、Torex PS模式8µA以及1M/1M分压约1.85µA，可得到一个简化基线：

| 项 | 电流 |
|---|---:|
| ST25DV常供电静态待机 | 76µA典型 |
| XC6220 PS静态电流 | 8µA典型 |
| ESP32深睡 | 5µA，沿用仓库估算，未实测 |
| 电池分压，按3.7V | 1.85µA |
| 简化合计 | 90.85µA |

XC6220静态电流来源：[Torex规格书](https://product.torexsemi.com/system/files/series/xc6220.pdf)。

在这个理想化模型下，250mAh约对应115天纯待机，且还没有扣除更新耗电、电池自放电、保护电路、温度、漏电、可用容量及低电压限制。**115天是量级估算，不是实测续航承诺。**

**建议：** 先决定首版是否接受较短续航；若必须一年以上，重新评估NFC供电控制或封装选择。供电控制还会影响I²C、GPO与FTM，不能只加一个关电动作。更新功耗表时同时列明工作模式、供电条件、典型值与实测值。

**验收：** 完整装机、USB断开条件下取得稳定待机电流与一次更新电荷量，用实际电池容量重新计算续航。

### F04｜P1｜制造导出没有可靠的ERC/DRC门禁

**证据：** [export.sh](https://github.com/wisdom-km/chroma-badge/blob/ee978f08cbdb7b61bbe2c78fea0e9c7cd2c34a7b/hardware/pcb/scripts/export.sh) 第9–11行：

- ERC/DRC没有使用--exit-code-violations。
- DRC额外使用“|| true”吞掉失败。
- 后续照常生成Gerber与贴片文件。
- 只筛error，且没有启用schematic-parity。

KiCad需要显式开启按违规返回非零退出码的选项。[KiCad 9 CLI](https://docs.kicad.org/9.0/en/cli/cli.html)。

**本次复现：** 在临时目录运行原export.sh，用模拟kicad-cli让DRC写出错误并返回5；脚本仍越过网表检查，到达Gerber导出。模拟器在那里主动终止，未生成真实生产文件。

**建议：** ERC与DRC明确采用失败阻断；保留完整报告，对允许的警告维护可追踪清单。把检查通过与发布包生成放在同一个受控流程中。检查失败不能覆盖上一次可用生产包。

**验收：** 人为构造检查失败时，生产导出命令不被调用；输出能指出失败阶段及报告位置。

### F05｜P1｜Power/NFC规则没有落地，DRC通过范围比预想更窄

**证据：** [design.py](https://github.com/wisdom-km/chroma-badge/blob/ee978f08cbdb7b61bbe2c78fea0e9c7cd2c34a7b/hardware/pcb/scripts/design.py) 第282–287行声明Default/Power/NFC；但脚本中没有使用NET_CLASSES的代码；[badge.kicad_pro](https://github.com/wisdom-km/chroma-badge/blob/ee978f08cbdb7b61bbe2c78fea0e9c7cd2c34a7b/hardware/pcb/badge.kicad_pro) 的net_settings仅有Default，网络分配为空。

本次从PCB提取到：

| 网络 | 设计声明的track值 | 当前实际线段宽度 |
|---|---:|---|
| VBUS | 0.3mm | 0.2mm |
| VBAT | 0.3mm | 0.15、0.2mm |
| +3V3 | 0.3mm | 0.15、0.2mm |
| EPD_SW | 0.3mm | 0.15、0.2mm |
| NFC_AC0/AC1馈线 | 0.5mm | 0.15、0.2mm |

线圈本体为自定义铜焊盘，不计入上述馈线宽度统计。上述宽度也不能单独用来断言载流或射频失效。

**建议：** 把网络类别、分配和需要强制执行的约束真正写入工程。KiCad中“默认走线宽度”与“DRC强制最小宽度”应分别设置。电源按电流与压降预算、USB按信号完整性、EPD开关回路按回流与寄生参数制定规则。

**验收：** 工程可读到正确分类；导出DSN保留所需规则；故意画一段违反强制约束的线能够被检查拦截。

### F06｜P1｜pin 7的Keep Open偏离应正式关闭，修复不能只改design.py

**证据：** [复核清单](https://github.com/wisdom-km/chroma-badge/blob/ee978f08cbdb7b61bbe2c78fea0e9c7cd2c34a7b/docs/04-review-checklist.md) 引用GDEM042F86第7页为NC Keep Open，但当前[design.py](https://github.com/wisdom-km/chroma-badge/blob/ee978f08cbdb7b61bbe2c78fea0e9c7cd2c34a7b/hardware/pcb/scripts/design.py)及PCB将J1.7接地。

更重要的是，[route_pcb.py](https://github.com/wisdom-km/chroma-badge/blob/ee978f08cbdb7b61bbe2c78fea0e9c7cd2c34a7b/hardware/pcb/scripts/route_pcb.py) 第302–313行的apply_extra_gnd_pads会强制把J1.7接地，第945行无条件调用。即使今后只改design.py，这个补线流程也会把PCB改回去。

**判断：** 已确认存在规格偏离记录和双重网络赋值逻辑；未实测证明屏一定损坏或一定不能工作。本次未独立读取该版屏幕PDF，不能把仓库摘录冒充独立厂商确认。

**建议：** 在没有该确切屏型号、修订版的书面许可前，按Keep Open处理更稳妥。同步修正生成数据与后处理器，禁止布线器擅自改变器件功能网络。恢复NC属于引脚约束修正，不需要推翻四色/电池/ESP32总体选型。

**验收：** 屏幕脚表、design.py、原理图、PCB一致；执行允许的后处理后仍一致；任何偏离有可追溯依据。

### F07｜P1｜XC6220替换验证需要补上电容与动态稳定性

**证据：** [design.py](https://github.com/wisdom-km/chroma-badge/blob/ee978f08cbdb7b61bbe2c78fea0e9c7cd2c34a7b/hardware/pcb/scripts/design.py) 使用AP2112符号、XC6220料号，近端C3=1µF、C4=2.2µF。[复核清单](https://github.com/wisdom-km/chroma-badge/blob/ee978f08cbdb7b61bbe2c78fea0e9c7cd2c34a7b/docs/04-review-checklist.md)确认引脚兼容，但没有关闭环路稳定性问题。

XC6220厂商推荐表将输入电容与输出电容组合关联；在3.0–3.5V输出档，CIN=10µF时推荐CL=4.7µF，CIN=4.7µF时推荐CL=47µF，并要求近端布置与考虑有效容量下降。[Torex规格书，第11页](https://product.torexsemi.com/system/files/series/xc6220.pdf)。

板上还有C2、C6等同网电容，不能忽略它们，也不能把它们的标称容量直接当作LDO引脚处的等效高频电容。因此这是**有依据的稳定性风险，尚不是已实测振荡**。

**建议：** 用实际主选型号重新核对近端CIN/CL、有效容量、ESR及布线；评估睡眠到射频发射、刷屏启动等负载变化。替代料表除pinout还要记录电容条件、压差与静态电流。

**验收：** 电压范围与负载转换下供电稳定，没有异常纹波、复位或明显超调。

### F08｜P1｜手机传图路线需要先做端到端能力验证

**证据：** [ADR](https://github.com/wisdom-km/chroma-badge/blob/ee978f08cbdb7b61bbe2c78fea0e9c7cd2c34a7b/docs/01-architecture-decisions.md) 同时规划NDEF URL、FTM、BLE/SoftAP与网页下发；[nfc.cpp](https://github.com/wisdom-km/chroma-badge/blob/ee978f08cbdb7b61bbe2c78fea0e9c7cd2c34a7b/firmware/src/nfc.cpp)目前只初始化I²C并探测ACK。

Chrome Web NFC仅暴露NDEF读写，不提供这里需要的厂商邮箱底层命令能力。[Chrome官方文档](https://developer.chrome.com/docs/capabilities/nfc)。

**结论：** 手机碰NDEF打开网页可作为入口，但这不意味着网页能直接操作ST25DV FTM。NFC Type 5标签的支持，也不等于Web API开放厂商自定义命令。

**建议：** 先选一个首版闭环：

| 路线 | 用户体验 | 主要工程条件 |
|---|---|---|
| 原生手机端＋NFC FTM | 保持贴靠传完图片 | 验证目标手机命令能力与会话流程 |
| NFC作入口＋原生端BLE | 碰一下后无线传图 | 手机应用、配对、恢复与协议 |
| NFC作入口＋设备SoftAP网页 | 本地网页编辑与传输 | 入网步骤、本地页面、浏览器连接与认证 |
| 已配网设备按需拉取 | 后台管理与批量更新 | 明确唤醒方式、联网时间与续航代价 |

暂时不需要同时实现四种路线。先用真实目标手机完成“一张非纯色图片发到屏幕”，再扩展模板和后台。

深睡时Wi-Fi/BLE连接不维持，因此“后台随时主动推送”还需要另一个唤醒/轮询机制。[Espressif睡眠说明](https://docs.espressif.com/projects/esp-idf/en/v4.4.8/esp32c3/api-reference/system/sleep_modes.html)。

## 4. 固件与协议可靠性

### F09｜P2｜显示驱动可以在异常BUSY状态下报告成功

[epd.cpp](https://github.com/wisdom-km/chroma-badge/blob/ee978f08cbdb7b61bbe2c78fea0e9c7cd2c34a7b/firmware/src/epd.cpp)第43–51、106–152行：

- wait_idle只等待低电平结束，没有证明刷新确实开始。
- power_on内部等待返回值被忽略；refresh_solid随后再次等待，形成隐式重试。
- power_off等待返回值被忽略，最终返回值只表达刷新阶段等待结果。

本次使用原epd.cpp加主机I/O替身运行：

| 模拟条件 | 原驱动返回 |
|---|---|
| BUSY始终为高 | true |
| 关电阶段BUSY一直为低并超时 | true |

第一项证明它无法区分正常空闲与“BUSY从未进入忙”；第二项直接证明关电超时被丢失。模拟中的65ms、5067ms只是替身时钟累计，不能当作真实屏幕时序。

**建议：** 将显示流程的启动、传输、刷新完成、关电结果分别报告；按确切屏规格处理最小命令延迟和BUSY转换，避免盲目要求所有命令都出现相同边沿。增加结构化错误码、有限恢复、低电量拒绝刷新与最小刷新间隔。

**验收：** 模拟异常得到可区分错误；实屏获得时序记录；仅在完整流程成功后更新“显示完成”状态。

### F10｜P2｜NFC探测需要升级成状态明确的驱动

当前ACK只表明地址有人响应，不等于型号、NDEF、邮箱和事件配置均就绪。

建议加入型号/UID识别、配置读回、用户区与系统区封装、I²C错误处理、邮箱状态、超时与恢复。初始化要支持“新芯片”和“已被改过配置的芯片”。

注意：不能断言“没有写GPO配置，所以出厂芯片绝对不产生事件”。KC规格书说明默认提供RF场变化检测；本项目的问题是没有验证、恢复或管理所需配置。[ST规格书](https://www.st.com/resource/en/datasheet/st25dv64kc.pdf)。

### F11｜P2｜图像传输应先定义协议，再写长流程

400×300×2bit为30,000字节；ST25DV64KC用户EEPROM为8KB，FTM为256字节邮箱。[ST规格书](https://www.st.com/resource/en/datasheet/st25dv64kc.pdf)。

推导：未压缩完整图片不能直接放入这8KB EEPROM。按每包最多256字节且忽略头部计算，至少118包；真实协议需要更多空间。邮箱用于分片交换，完整图可在MCU RAM组装，若要求断电恢复则增加可靠持久化。

建议协议明确：

- 版本、图像宽高、像素编码、长度与图像ID。
- 会话ID、分包序号、分片偏移、校验。
- ACK、超时、重试、重复包与断点恢复。
- 完整图验证成功后才允许刷屏。
- “传输完成”和“显示完成”分别确认。
- 上限约束，避免错误长度造成越界或资源耗尽。

无需一开始引入复杂协议框架，先形成一页可执行的协议规范和黄金测试图片。

### F12｜P2｜电源与休眠应成为统一状态机

main负责休眠、epd负责电源开关、NFC未来又需要独立会话，若各自操作电源容易产生时序交叉。

建议采用一个明确的应用流程：启动诊断 → 判断唤醒原因 → 接收会话 → 完整性验证 → 刷屏 → 关电与日志 → 休眠；超时和低电量统一进入恢复分支。电源状态只能有一个管理入口。

同时复核SPI外设停止后引脚是否真的到达预期电平、GPIO hold的设置与释放顺序，以及屏断电后的I/O漏电。当前调用digitalWrite后并不能仅凭源码断言所有外设复用脚都已实现物理隔离，此项需要实测。

## 5. PCB、制造与机械

### F13｜P2｜USB与EPD关键回路需要针对性布线审查

仓库复核清单中的“C3全速不严格要求差分”容易让维护者误解。Espressif仍建议USB并行差分、连续参考地、控制阻抗并减少换层。[USB布局指南](https://docs.espressif.com/projects/esp-hardware-design-guidelines/en/latest/esp32c3/pcb-layout-design.html)。

当前PCB中USB_DP有4个过孔，USB_DN有2个；它们的全部平面线段总长分别约30.20mm和35.08mm。**这些是网络总量统计，包含分支，不能直接解释为端到端差分长度误差。** 需要沿连接器到芯片路径核查。

EPD_RESE网络全部平面线段合计约31.35mm并有2个过孔，应重点检查电流采样回路和参考地。连接正确不保证动态波形良好。

建议优先人工审查USB、电源主干、升压开关回路、采样回路及NFC馈线，再让自动布线处理一般控制信号。检查USB调试元件预留与接口ESD设计，具体参数按器件指南与测试确定。[USB原理图建议](https://docs.espressif.com/projects/esp-hardware-design-guidelines/en/latest/esp32c3/schematic-checklist.html)。

### F14｜P2｜NFC与Wi-Fi天线的最终表现仍需装机验证

线圈盖阻焊已由PCB文本证实，不应为了截图显黄而重开窗。几何电感计算适合初选，无法替代装机后的谐振、耦合和手机兼容性测试。

屏幕层、电池、外壳、贴胶、人体与手机壳都应纳入测试条件。C11预留调谐位置是优点，但需要记录实际装配状态、器件值和测量结果。Wi-Fi模组也需验证最终外壳中的净空与实际连接表现。[Espressif模组天线布局建议](https://docs.espressif.com/projects/esp-hardware-design-guidelines/en/latest/esp32c3/pcb-layout-design.html)。

不要把“目前能清DRC”作为天线设计验收指标，也不应在没有测量的情况下直接断言现有线圈无效。

### F15｜P2｜制造包存在DNP与非贴装项目混入

[位置文件](https://github.com/wisdom-km/chroma-badge/blob/ee978f08cbdb7b61bbe2c78fea0e9c7cd2c34a7b/hardware/pcb/output/badge_pos_back.csv)包含DNP的C11；[BOM](https://github.com/wisdom-km/chroma-badge/blob/ee978f08cbdb7b61bbe2c78fea0e9c7cd2c34a7b/hardware/pcb/output/badge_bom.csv)包含ANT1和TP1–TP4这类板上铜图形/测试焊盘。当前BOM有34行，其中21行没有LCSC编号；部分为空合理，但可采购器件需要补全。

建议区分：

1. 工程全量BOM，包含DNP与板级元素。
2. 实际贴装BOM，仅含装配器件及锁定料号。
3. 贴装位置表，与实际装配BOM一一对应。
4. 备选物料表，列电气、机械和固件兼容条件。

这主要是交付歧义与返工风险，不能据此断言工厂一定会错贴。

### F16｜P2｜模型完整性与机械验收范围不足

[USB封装](https://github.com/wisdom-km/chroma-badge/blob/ee978f08cbdb7b61bbe2c78fea0e9c7cd2c34a7b/hardware/pcb/lib/badge.pretty/TYPE-C-31-M-14.kicad_mod)引用项目内lib/3d/TYPE-C-31-M-14.step，但该文件不在本次仓库树中。仓库内ESP32 STEP存在；不能因为没有下载到本地审查副本就误报它缺失。

缺少USB源模型会影响干净环境下重新导出与机械核查。已有badge_full.step是否包含从旧环境嵌入的USB实体，本次未独立解析，因此不作结论。

[外壳脚本](https://github.com/wisdom-km/chroma-badge/blob/ee978f08cbdb7b61bbe2c78fea0e9c7cd2c34a7b/hardware/enclosure/badge_enclosure.py)还存在以下验证边界：

- 未建立FPC弯折实体、连接器翻盖开启空间、插拔操作空间。
- 电池为仓位简化体，没有实际电芯、保护板、导线和连接器的完整包络。
- 胶层与材料公差尚未完整纳入厚度堆叠。
- 按键目前是后盖孔，没有明确的可触达执行件设计。
- 有干涉时仅打印CHECK，没有失败退出；并且输出文件在检查之前已写入。
- 缺少部分实体之间的检查，例如实际电池/导线与PCB组件的装配关系。

因此“干涉0”只覆盖已建模、已检查对象。建议把模型完整性、最小间隙、实体有效性、运动空间与实际装配公差纳入机械发布门槛。

0.8mm板厚是已接受的首版选择，保留这个决策；但“0.8±0.1包含0.75”不能证明公差区间全部适配连接器。通过供应商允许范围与首件尺寸记录补全验证。

### F17｜P2｜电池与供电路径还没有形成确定的装配规格

仓库明确电池自带PCM，这是合理约束。但具体电芯料号未锁定，充电器仍写TP4054/MCP73831两个选择，且系统从VBAT取电，没有独立系统电源路径管理。

建议先锁定具体受保护电池包和充电器版本，由具备相关经验的硬件人员核对允许充电条件、保护方案、机械包络和热条件；验证系统负载对充电终止、低电压恢复及USB供电启动的影响。保护板存在不等于上述条件已经全部满足。

软件应定义低电量行为、充电期间是否允许传图/刷新、异常重启恢复。此处不将“无电池插USB一定失败”当作已证实结论，而将它作为应测试的用户场景。

### F18｜P2｜制造输出的版本一致性需要加强

[export.sh](https://github.com/wisdom-km/chroma-badge/blob/ee978f08cbdb7b61bbe2c78fea0e9c7cd2c34a7b/hardware/pcb/scripts/export.sh)会清空gerbers目录，却更新既有ZIP，旧ZIP成员可能留下。本次最小实验确实复现：旧文件已从目录删除，重新zip后压缩包仍同时包含旧、新文件。

另一个问题是export.sh只更新drc_final.rpt，不更新drc_final.json；后者来自route_pcb.py，今后容易与当前板产生不同步。

建议每次在新的临时目录生成完整发布包，通过后整体替换。记录源提交、PCB/原理图哈希、工具版本、BOM版本、检查报告与生产文件SHA-256。生产包文件清单应与本次输出严格一致，不保留旧成员。

## 6. 工程维护与产品化

### F19｜P2｜生成器与自动补线器需要收敛为可验证流程

保留design.py作为集中定义是正确方向，但需要让它真正控制所有关键结果：

- pins.h目前是手写副本：增加自动生成或引脚映射一致性检查。
- route_pcb.py不应硬编码改功能网络；检查器应对后处理结果再次比对。
- check_netlist.py仅比对已导出网表，不直接检查PCB；本次独立比对通过不代表未来自动得到保障。
- drc_json未检查子进程退出状态，又复用固定文件名，可能在命令失败时读到旧报告。
- 原理图生成器使用随机UUID及当天日期；无功能修改也会产生大量diff。建议为元件、引脚、标签用稳定标识，并分离生成时间与设计版本。
- 原理图“全局标签拼接”易生成但难审查关键回路；按USB、电源、主控、NFC、EPD分区画清电流路径，特别是升压与采样。
- 外壳模块导入会执行main，渲染脚本靠删除末尾字符串规避；应拆分纯几何函数与命令入口。
- GND聚类和碰撞搜索逻辑有重复；未来提取几何、连通性、修复策略和CLI层，保留有代表性的回归板。
- 简化“--skip-route不动走线”的说法：代码仍执行join_duplicate_pads与repair，应明确它是跳过自动布线，而非严格只读或保证不修改信号线。
- 根README快速开始直接生成未布线PCB后接导出，容易覆盖现有路由并导出未完成板；应提供“检查现有板”与“重新生成并布线”两条清晰入口。

按AGENTS约定，目前不用重跑生成器来验证这些问题，也不需要修改既有ADR来完成本次审查。

### F20｜P2/P3｜构建、文档与产品边界

当前platformio.ini未固定espressif32版本，虽然固件README记录了生成二进制的工具版本。建议固定已验证依赖，保留固件哈希、构建日志和源码提交；先建立编译、网表/引脚一致性、协议边界、检查失败阻断这些少量高价值测试。

当前树未见自动化工作流、测试目录或项目自身LICENSE。建议增加轻量CI、开源许可声明及第三方内容清单；正式分发前确认各资源许可，不把README中的一句来源说明等同于完整许可资料。

文档有局部不同步：

- BOM文档指向不存在的export.py，实际是export.sh。
- ADR写固件另行开发，实际上已有v0.1自检。
- 状态表、复核清单中的“通过”有时表示工程决策，有时表示规格验证或实测。
- 早期erc.rpt有大量库配置警告，较新erc_errors.rpt只是错误级筛选。
- 不应把NDEF、FTM、BLE、Wi-Fi列为同一种“已支持”能力。

建议统一使用“设计完成 / 静态通过 / 已构建 / 实机通过 / 待验证 / 已接受偏离”这些状态，并关联证据。

产品第一阶段建议专注：姓名、职位/组织、品牌色块、二维码、少量模板，以及稳定更新。四色屏适合这类用途；任意照片与渐变效果留到后续。增加离线二维码可读性、模板最小字高与刷新进度反馈。

安全设计应围绕实际写入入口：允许公开读取名片，不代表允许任何邻近手机覆盖工牌。在实现写入前定义设备所有权、授权窗口、传输完整性、重放处理和设备重置。UID用于识别，不能单独作为写权限凭证。当前还没有完整网络服务，不能把未来设计要求写成现存可利用漏洞。

成本方面，仓库150–225元是既有估算，本次没有做实时采购报价核验。后续预算加入SMT装配、测试治具、损耗、装配工时、包装、物流与返修；不能将元件合计直接当成最终交付成本。

## 7. 建议执行顺序

| 阶段 | 工作 | 完成标志 |
|---|---|---|
| A：修复明确阻塞 | F01、F02、F04、F05、F06；复核F07；重算F03 | 启动/睡眠可解释；规则落地；失败阻断；规格偏离关闭 |
| B：冻结首件规格 | 电池/充电器/屏版本锁定；USB与关键回路审查；装配与模型补齐 | 同一提交可导出一致的工程包与装配清单 |
| C：单板闭环 | 串口诊断、四色/条纹测试、NFC事件、一次完整图像更新、异常恢复 | 能重复运行，失败可定位 |
| D：目标手机闭环 | 只选择一条首版传图路线，验证目标机型 | 图片验证成功后刷新，掉线不会显示半图 |
| E：可靠性 | 待机/更新耗电、低电压、装机射频、充电与机械场景 | 用实测修正续航、性能与可用性描述 |
| F：产品化 | 模板、权限、批量配置、生产测试、发布包与许可 | 可交给其他人复现、使用和维护 |

这不是按日历承诺工期。优先把“会不会稳定工作”的证据补齐，再决定是否进入外壳精修与批量生产。

## 8. 最小验收清单

| 场景 | 通过标准 |
|---|---|
| 正常启动 | 日志可读，版本/复位原因明确 |
| 自检入口 | 文档操作可重复触发，且不与下载模式混淆 |
| 深睡与唤醒 | 合法配置；触碰恢复；连续重复不丢失唤醒 |
| NFC身份与事件 | 型号/配置可读回，事件原因清晰 |
| 显示 | 四色、方向、边界、二维码正确；超时不会报告成功 |
| 图像传输 | 错长、错序、重复、断链均可控；完整校验后才刷屏 |
| 低电量 | 不反复刷屏或重启；恢复路径明确 |
| 功耗 | 待机和单次更新分别测量，给出条件与波动范围 |
| USB | 可重复枚举/下载/查看日志，覆盖正反插与典型线缆 |
| 制造包 | 错误会阻断；BOM与位置表一致；无旧ZIP成员 |
| 装配 | 真实FPC/电池/连接器与胶层可装入；按键/USB可操作 |
| 复现 | 固定版本的干净环境可得到通过检查且可追溯的输出 |

建议项目下一里程碑命名为“工程样机闭环验证”，用这些证据定义完成度。

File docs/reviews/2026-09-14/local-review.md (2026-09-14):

# BADGE-42C 本机独立复审报告

审查日期：2026-09-14。审查对象：[基准提交 ee978f0](https://github.com/wisdom-km/chroma-badge/commit/ee978f08cbdb7b61bbe2c78fea0e9c7cd2c34a7b)。本机起始 HEAD 与远端 main 均为该提交。审查输入包括用户提供的报告、本机源码、KiCad 工程、已有制造输出、FreeCAD 几何、固件工具链及官方规格资料。

## 1. 结论和证据边界

项目已经形成可编辑的硬件设计、已布线 PCB、可生成外壳和可构建固件。当前里程碑应定义为 **工程样机闭环验证**，不能定义为“已可交付生产”或“仅剩手机传图”。

外部审查的核心方向成立。本机复审进一步独立核对了确切屏幕 PDF，完成固件干净构建和异常路径探测、FreeCAD 实体/交叠检查、制造包内部一致性和固件引脚映射检查。新的重要发现是屏升压参考电路与当前物料存在多处尚未说明的差异；不要把 RESE 电阻值相同视为升压方案全部核准。

**本轮未接入实物板、电池、屏幕、逻辑分析仪、示波器、VNA或目标手机。** USB枚举/刷机、真实刷屏、RF通讯、续航、充电热行为、实际装配和耐久均未测试。主机 I/O 替身不会模拟显示器模拟电路，也不会证明任何真实波形。

本轮没有改 `design.py`、原理图、PCB、现有生产输出或产品固件。根 AGENTS 要求规格/文档冲突先讨论，本报告将冲突作为待决项，不覆盖历史 ADR，也不批准硬件偏离。

## 2. 审查基准和环境

会话开始前存在 `hardware/pcb/badge.kicad_pro` 本地修改，以及未跟踪 `tools/freerouting/`。工程差异主要为新版本 KiCad 增加的配置字段；它们不属于本轮成果，保留原样、不推送。审查副本首先使用 HEAD 中的 `.kicad_pro`，防止混淆已提交设计与本地编辑器状态。输入文件 SHA256、大小和起始状态存于 [inputs.json](evidence/inputs.json)。

| 工具 | 本轮环境 / 用途 |
|---|---|
| FreeCAD | 1.1.3，`D:/FreeCAD/bin/python.exe` 可直接导入 FreeCAD/Part；真实 OCC 布尔运算 |
| PlatformIO Core | 6.2.0；已有安装 `D:/PlatformIO/penv/Scripts/pio.exe` |
| PlatformIO 平台 | espressif32 7.1.3 |
| Arduino framework | `4.20017.260907+sha.dcc1105b`；实际 SDK 头文件为 ESP-IDF 4.4.7 |
| 目标编译器 | riscv32-esp 8.4.0+2021r2-patch5 |
| 主机测试编译器 | MinGW GCC 13.1.0；直接编译未修改的 `firmware/src/epd.cpp` |
| PDF | 本地 `GDEM042F86.pdf`，40页；逐页渲染核对6/7/29/31页；原PDF及页面图不入库 |
| GitHub | 起始远端 main 与本地 HEAD 一致；提交只包含本轮文档、证据、审查脚本 |

KiCad 9.0.8 已校验官方安装包后独立安装到 `agent-tools/kicad-9.0.8`（不入Git）。全量报告见 [证据索引](evidence/README.md)。所有诊断导出保存在隔离目录；即使 CLI 导出成功，也不能将其视为生产许可。

### 2.1 当次 KiCad 结果和制造输出同步性

| 检查 | 当次结果 | 判断 |
|---|---|---|
| ERC error级 | 0错误，CLI返回0 | 缓存原理图可检查 |
| ERC全量 | 1条 `lib_symbol_issues`，CLI返回5 | U1来源Espressif符号库解析/查找未闭合，不能写全量零警告 |
| DRC error级 | 0错误，0未连接，CLI返回0 | 当前规则下通过 |
| DRC全量+parity | 64条板级warning +84条parity warning，CLI返回5 | 全量检查不通过，需分类处理 |
| 本机未提交工程配置交叉检查 | error DRC仍0 | 起始配置变化没有改变本轮error结论；原本机文件保留 |
| 新网表 | 原检查器通过，63个原理图网络，其中41个功能网络 | 其余为未连接脚网络 |
| 生成器复现 | 隔离副本重跑`gen_nfc_footprint.py`、`gen_schematic.py`成功；再导出网表/检查匹配，生成原理图ERC error0 | sexpdata1.0.2隔离依赖；NFC封装忽略换行后与原文件相同；未运行`gen_pcb.py` |
| PCB直接读取 | 57封装，全B.Cu，91×84×0.8mm，两层，564段/128过孔；设计引脚/NC分配无差异 | 包围盒含Edge.Cuts笔画会得到91.1×84.1，不能误报为板变大 |
| 后处理两次 | 每次564/128，布线指纹 `2d96f2751cfe29874e19817df79bebdc1da593ffc553671f2aa7306423b1d7c4` 不变，DRC error0 | 本输入上幂等，没启动Freerouting |
| 模型覆盖 | J3项目USB模型缺失；J2引用模型在已安装官方9.0.8库无法解析 | STEP导出仍返回0，缺模型不是板上没封装 |
| 诊断输出 | Gerber、钻孔、BOM、位置、整板/裸板STEP、原理图PDF/SVG、PCB SVG及两张渲染均成功 | 原export.sh入口未跑通，但上述KiCad命令分别已执行 |
| 新旧制造数据 | 13份Gerber/钻孔类文件去除生成日期后12份一致 | 背面丝印不同，有真实坐标变化；旧ZIP包含旧丝印，见N02 |

148条warning分布：`text_height`57、`silk_over_copper`1、`silk_overlap`6、`footprint_symbol_mismatch`62、`net_conflict`22。57条封装名告警主要是PCB保存裸封装名而原理图有库前缀，另外5条是ANT1/TP1–TP4的BOM排除属性差异。22条net_conflict为原理图命名的unconnected网络与PCB无网表示不同；直接引脚核对没有发现功能网错接。它们仍需生成流程和明确规则处理，不能把warning全部当真短路或全部默认忽略。

真实丝印项包括D3参考文字被阻焊截断、Q2轮廓与D3文字重叠、若干小于0.8mm的文字；本轮只是定位，没有改板。原DRC只取error所以这些不在原“DRC0”语义内。

USB_DP网络平面线段总长30.19643mm/4过孔，USB_DN35.077666mm/2过孔；EPD_RESE31.350637mm/2过孔。它们是含分支的网络总量，不能直接当端到端长度差。Power/NFC馈线宽度实际包含0.15/0.2mm，和未落地的声明宽度0.3/0.5mm不同。

### 2.2 新发现N02：旧制造包背面丝印未同步

本机用同版KiCad9.0.8、当前PCB重新导出，比较只移除生成日期，不移除坐标、孔径或其他属性。铜层/阻焊/焊膏/板框/正面丝印/孔数据一致，`badge-B_Silkscreen.gbr`不一致。坐标命令多重集合也不同，因此不是文件块重排：例如一组线端Y从`-78263855`变到`-77963855`（Gerber 4.6单位mm，对应0.3mm）。

当前ZIP与旧目录内部一致，所以也携带该旧丝印。此项从外部报告的“版本一致性风险”升级为**已证实的交付文件不一致**。见 [manufacturing-diff.json](evidence/manufacturing-diff.json) 与 `extra-exports.json`。本轮未替换原制造包；修复发布门禁、确认警告处理后应重新导出并一次性发布同步包，禁止只更新渲染截图。

## 3. 本轮已执行的非 KiCad 测试

| 检查 | 实际结果 | 证明范围 |
|---|---|---|
| 9个原有Python脚本 AST | 全部通过 | 语法可解析，不代表生成与硬件功能正确 |
| `pins.h` 对照 design + 库中模组脚名 | 13个固件GPIO定义一致，0差异 | 自动从符号脚名取GPIO，避免只抄注释；GPIO9用途是否合法另行核查 |
| 干净目标构建 | 通过，RAM 15,312 / 327,680 B，Flash 283,588 / 1,310,720 B | 能构建，不代表板上能运行 |
| 二进制可重复性 | 应用296,512 B、bootloader13,248 B、partitions3,072 B；三份SHA256均与仓库既有bin相同 | 本机现有工具链可字节复现这三份固件；不保证未锁依赖的新机器未来仍相同 |
| EPD替身场景 | 5种BUSY场景 × 4色，共20次调用 | 真实生产代码的字节输出、返回状态、关电请求 |
| 正常四色路径 | 每色发送30,000字节；00/55/AA/FF编码正确；请求关断屏电源 | 不验证真实颜色、方向或刷新波形 |
| BUSY恒高 | 四色均报告成功 | 驱动无法区分空闲与刷新从未启动 |
| 关电BUSY超时 | 四色均报告成功 | 明确丢失关电超时状态 |
| BUSY恒低 / 刷新超时 | 均返回失败；请求关电 | 有部分失败处理，但阶段信息不完整 |
| DRC命令失败注入 | 返回5后仍走到Gerber命令；测试哨兵退出99 | `export.sh` 中 `|| true` 确实破坏门禁 |
| ERC命令失败注入 | 返回5后脚本立即停止，没有走到Gerber | 不应笼统声称任何ERC进程失败都会被吞掉 |
| 旧DRC报告注入 | 命令返回5，`drc_json`仍返回带 `OLD_REPORT` 标记的空旧报告 | 已复现旧证据误当本次通过，建议优先修复 |
| 当前ZIP与gerbers目录 | 14个文件成员，无多余/缺少/内容不同 | 当前包内部一致；不证明它们与当前板同源，也不排除以后原地更新残留 |
| BOM/位置表 | BOM34行，21行无LCSC；C11(DNP)仍在位置表 | 工程清单不能直接作为无歧义的SMT交付清单 |
| FreeCAD原生成脚本 | 隔离副本真实运行成功，前框/后盖/装配STEP、STL、FCStd成功写出 | 没有覆盖仓库生产文件 |
| FreeCAD原渲染脚本 | 5张预览重新生成成功 | 外壳预览可重现；不是实物装配照片 |
| OCC扩展交叠检查 | 5类实体两两10组，交叠体积均0；所有实体有效 | 只覆盖已建模物体；原始脚本9组检查也均为0 |

上述结果分别见 `static.json`、`firmware-clean-build.log`、`epd-probes.json`、`faults.json`、`mechanical-saved-step.json`、`enclosure-generation.log` 和 `enclosure-render.log`。详情与复跑命令见 [证据索引](evidence/README.md) 和 [工具手册](../../../tools/review/README.md)。

## 4. 固件审查

### 4.1 GPIO9深睡唤醒：与真实构建SDK核对

`main.cpp::go_sleep` 将GPIO1与GPIO9同时加入mask，忽略 `esp_deep_sleep_enable_gpio_wakeup` 返回值，随后无条件打印可由NFC或BOOT唤醒并进入深睡。本轮使用的SDK `soc_caps.h` 明确只允许 BIT0–BIT5；实际 `esp_idf_version.h` 为4.4.7，不能将外部报告引用的4.4.8当作本机构建版本。

核对 [ESP-IDF v4.4.7实现](https://github.com/espressif/esp-idf/blob/v4.4.7/components/esp_hw_support/sleep_modes.c) 与 [睡眠API说明](https://docs.espressif.com/projects/esp-idf/en/v4.4.8/esp32c3/api-reference/system/sleep_modes.html)：非法脚会导致配置失败。修复应检查返回码，并保留可解释的恢复入口；不能假定GPIO1虽合法就一定已经成功启用。

GPIO9同时是启动strap。[官方启动模式说明](https://docs.espressif.com/projects/esptool/en/latest/esp32c3/advanced-topics/boot-mode-selection.html) 支持“按住BOOT复位进入ROM下载”这一判断。现有文档将相同操作描述成应用自检入口，存在冲突。建议正常启动后明确输入窗口/串口命令；变更操作文档之前先按AGENTS讨论确认。

### 4.2 显示流程与官方程序

独立读取GDEM042F86第31页后，`init_otp()` 的10组初始化命令与图中参数一致；400×300、2bit编码及30,000字节帧大小一致。这个正面结果应保留，不能因错误处理缺陷否定全部驱动实现。

主要缺陷在流程状态：`power_on()` 丢弃首次等待结果；`power_off()` 丢弃关电等待结果；`refresh_solid()` 的最终bool仅能反映刷新阶段的一次空闲等待。BUSY卡高和关电超时均已本机复现假成功。完整证据不是真实毫秒测量；`fake_elapsed_ms`只是替身虚拟时钟。

还需实物验证：最小命令延迟、BUSY实际变化、电源开关、断电后SPI复用脚电平、GPIO hold跨睡眠行为、低电拒绝刷新。不要在没有屏时序依据时简单要求每条命令都必须出现相同BUSY边沿。结构化错误应至少区分上电、数据、刷新、关电。

### 4.3 NFC、协议和手机路线

`nfc.cpp`目前只有Wire初始化、100kHz设置和用户区地址ACK检查；NDEF、FTM、UID/配置管理、会话恢复均不存在。ACK成功只能证明某地址应答。

30,000字节整图大于ST25DV64KC的8KB EEPROM，256B邮箱适用于分片交换；忽略头部至少118包，实际协议更多。定义长度/版本/编码/偏移/序号/CRC、重复包幂等、超时和授权窗口，完整校验后才刷屏。型号/容量依据 [ST规格书](https://www.st.com/resource/en/datasheet/st25dv64kc.pdf)。

[Chrome Web NFC文档](https://developer.chrome.com/docs/capabilities/nfc) 将能力限制在NDEF。由此推断，“碰NDEF打开网页”不能自动形成“网页向ST25DV厂商邮箱传图”闭环。首版必须选定真实目标手机和一条可实现路线，先完成一张非纯色图再扩展模板。

## 5. 电气、器件和电源审查

### 5.1 屏脚7：本轮已取得独立规格证据

本地40页PDF第7页将1/4/6/7标NC Keep Open，19为VPP Keep Open。当前J1.7在design、原理图、PCB和后处理硬编码均为GND。第29页参考电路对6/7又采用TSCL/TSDA标识，存在资料内部差异；不能据此自行免除脚表约束。

结论是**规格偏离未关闭**，不是“已测到损坏”，也不是“NC接地通常没事所以通过”。如要保持GND，需精确屏版本的认可依据；如要恢复NC，需讨论后同步全部赋值位置，防止 `apply_extra_gnd_pads` 再次接地。

### 5.2 新发现N01：升压电路不能只复核RESE

| 对象 | 当前设计 | 第29页参考 / 本轮判断 |
|---|---|---|
| 电感L1 | 68µH；描述Isat≥0.2A；C2827366 | 图为47µH/500mA；不是同一参数组合，需确切器件DCR/饱和电流和动态依据 |
| 飞跨/泵电容C15 | 1µF/50V，0805 | 参考相应C3为4.7µF/25V；较高耐压不等于满足容量条件 |
| GDR下拉 | 当前GDR网络只有屏脚和Q1栅极 | 参考R1为1M到地；缺少该件需解释关断/浮空行为，不直接断言必定失效 |
| Q1 | AO3400A，备选描述Si1304BDL | 参考Si1308EDL；应比对驱动电压下Rds(on)、栅电荷、耐压及封装，而非只看N-MOS |
| RESE R14 | 2.2Ω、默认0402，额定功率未锁定 | 阻值一致；参考元件表给0603/0805及功率要求，脉冲能力仍需依据 |

本轮未更换任何元件。应将此项列为首件电源/显示验证前的P1调查任务，并核对供应商例程是否对应当前屏修订。不能未经讨论拿参考值机械替换现有设计后直接重布线。

### 5.3 LDO与续航

XC6220引脚兼容不能证明动态稳定性。[Torex第11页](https://product.torexsemi.com/system/files/series/xc6220.pdf) 的3.0–3.5V档将CIN/CL成对规定；当前近端C3=1µF、C4=2.2µF，尚缺实际电容有效容量和布局依据。同网的C2/C6不能忽略，也不能仅把标称值相加当近端补偿容量。

SO8的ST25DV未提供其他封装的LPD控制脚。[ST表249](https://www.st.com/resource/en/datasheet/st25dv64kc.pdf) 的3.3V常供电静态待机为76µA典型。用76+8+5+1.85=90.85µA作简化基线，250mAh纯待机约115天；这是估算，未计刷新、自放电、保护、漏电、温度、有效容量等。现有“13µA/约两年/一年充一次”尚无支撑，待讨论后统一修订ADR、固件和design说明。

### 5.4 USB、充电和射频

USB0.8mm是用户已确认的首版决策，保持。公差范围包含0.75mm不能证明整个区间适配座子。须补供应商机械范围、实际座子型号与首件量测。[Espressif布局指南](https://docs.espressif.com/projects/esp-hardware-design-guidelines/en/latest/esp32c3/pcb-layout-design.html) 仍要求关注USB差分与回流；应沿端到端路径分析，网络总长统计包含分支。

充电器主料仍写TP4054/MCP73831，实际电池未锁；系统从VBAT取电，没有独立负载电源路径管理。需要指定充电允许条件、受保护电池包、极性和连接器，测试系统负载对终止/恢复的影响。不能宣称无电池USB一定失败，也不能将此场景视为已验证。

NFC铜线圈盖阻焊是既有设计，不因截图颜色改变而重开窗。电感公式不能替代带屏、电池、外壳、人体后的谐振和手机兼容性测量；C11初始DNP与后续调谐状态都应在装配表中明确。

## 6. 机械审查

FreeCAD重建得到94×93×6.3mm，前框有效体积7827.4907mm³、后盖7095.0721mm³，两者均单一有效solid。既有STEP含403个solid，经OCC读取有效。10组扩展两两交叠为0，包含此前未显式检查的电池占位与PCB STEP。

新导出的STEP同样含403个有效solid；扩展10组检查仍全部0，见 `mechanical-fresh-step.json`。这是严格限定的几何结果：电池为45×48×2mm占位体，未包含实际保护板/出线/连接器；屏是平板、没有FPC；按键为孔而无执行件；胶厚和公差链不足；J3源STEP在仓库缺失，J2源模型也无法从本机官方库解析。原脚本会在检查前先写文件，发现交叠仅打印CHECK，未形成发布阻断。后续应先验证实体及干涉，再原子发布。

屏第6页开窗位置支持ACTIVE_TOP=6.7mm，0.30mm补强尾端信息可用于FPC厚度复核；动态弯折包络、翻盖开启/插拔空间和实际接触面仍需实装。图片若未对准目标必须重拍，遵循 `docs/05-visual-check.md`。

## 7. 工程与制造流程审查

- `NET_CLASSES`没有被生成流程使用；Default、Power、NFC的声明不能自动约束当前PCB。应区分首选走线宽度与DRC强制最小宽度。
- `check_netlist.py`只检查导出网表，不读PCB，也依赖固定输出路径。新增审查工具补充了设计→PCB焊盘和符号→固件GPIO比较，但不是产品生产门禁的替代。
- `route_pcb.py::drc_json`在失败时读旧报告已复现。应让失败不能产生PASS；每次报告使用独立路径/输入指纹并验证返回码。
- `export.sh`的ERC真实进程失败可停止；DRC进程失败被吞。两者都缺少违规退出码，完整warnings与原理图一致性检查没有形成生产要求。
- 原地更新ZIP存在未来旧成员残留风险；本轮当前ZIP成员与目录完全一致，不能把流程风险写成当前包已污染。此机未独立重复原报告所用zip工具的旧成员更新实验。
- BOM工程清单包括ANT1与测试点；位置表包括C11。需另做装配清单和对应的位置文件，不应自动删除工程记录中的这些对象。
- UUID随机/当天日期会制造非功能diff；外壳模块导入即运行main，渲染通过删末尾调用绕开；这些是可维护性工作，不应为审查而大幅重构。
- README快速开始会重建未布线PCB再导出；`tools/README.md`尾部仍有“盖绿油才Freerouting”的旧说法，和根AGENTS冲突；BOM文档指向不存在的export.py。这些冲突在本轮登记，未擅自改写旧流程。
- 依赖版本未固定、许可决定未完整、缺少自动化CI。当前二进制可复现是正面证据，但不能取代版本锁和长期发布追溯。

## 8. 如何使用本报告

原审查原样保存在 [external-review.md](external-review.md)，没有把其中命令当作用户授权。逐项F01–F20与新增N01的合并结论、优先级、修改入口、批准点和关闭标准见 [integrated-plan.md](integrated-plan.md)。后续执行请使用 [tools/review/README.md](../../../tools/review/README.md)，不要覆盖本次审查证据。

没有实测的项保持“待验证”；没有修改的缺陷保持“未修复”。审查提交不是硬件生产发布，也不是下一版固件发布。

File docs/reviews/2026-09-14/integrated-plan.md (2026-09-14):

# 合并审查与可执行整改计划

日期：2026-09-14。审查硬件/固件基准：`ee978f08cbdb7b61bbe2c78fea0e9c7cd2c34a7b`。

本文件将 [外部审查原文](external-review.md) F01–F20 与 [本机独立复审](local-review.md) 合并。**建议不等于已修复；审查通过不等于实机通过。** 本轮交付审查、证据和执行工具，没有改硬件网络、重新布线或修改产品固件。具体命令见 [执行手册](../../../tools/review/README.md) 的正确入口：仓库根目录 `tools/review/README.md`（下方执行路径均相对仓库根目录）。

## 1. 下一位 Cursor / Codex 的第一步

1. 先读根 `AGENTS.md`、`docs/03-handoff.md`、`docs/01-architecture-decisions.md`，再读 `docs/06-current-status.md` 与本文件。旧文档中的进度描述保留历史语境。
2. 执行 `git status --short` 和 `git log -5 --oneline`。本轮开始前 `badge.kicad_pro` 已有本地改动，`tools/freerouting/` 已有未跟踪内容；不得把它们顺手提交、清理或重置。
3. 复查 `tools/review/README.md` 的环境路径。不要把开发者的绝对路径当成其他机器的事实。
4. 用户尚未确认的硬件规格偏离，只能调查和提出具体变更。根 AGENTS 要求发现文档与板上事实冲突先讨论；本报告不是对任何偏离的批准。
5. 不运行 `gen_pcb.py` 来做普通审查，不运行 Freerouting 来美化图片，不把本轮诊断导出目录当生产发布包。

## 2. 逐项合并矩阵

证据等级：**复现** = 本机执行或直接读取确定；**规格** = 厂商资料与设计比较；**风险** = 有依据但没有实物故障；**待开发** = 能力尚未实现。所有条目的关闭都要新提交、测试证据与负责人。

| 编号 | 优先级 / 当前结论 | 实际修改入口与下一动作 | 关闭证据 |
|---|---|---|---|
| F01 | P1 / 复现配置缺陷，尚未修复 | `firmware/src/main.cpp::go_sleep`：去掉不支持的 GPIO9 深睡 mask；检查 API 返回值，失败不宣布就绪；先保留 RESET 恢复 | 构建通过；合法/非法配置测试；实板重复 NFC 唤醒至少 100 次，记录每次原因 |
| F02 | P1 / 启动入口冲突，尚未修复 | `main.cpp::setup` 与 `firmware/README.md`：设计正常启动后的明确自检窗口或串口命令；区分 ROM 下载入口 | 按新文档从冷启动、RESET、烧录后三种情况均可重复自检；不依赖按键时机碰运气 |
| F03 | P1 / 规格支持，续航未测 | `design.py` 的 POWER 说明、ADR 2.4、固件预算均需讨论后同步；先测常供电 SO8 的真实电流，再决定接受续航还是设计改版 | USB 断开、指定电池/温度/装机条件的待机电流和更新电荷；计算表含损耗，不再沿用 13 µA 未验证前提 |
| F04 | P1 / DRC 故障穿透已复现 | `hardware/pcb/scripts/export.sh`：违规退出码、命令错误退出、完整报告、显式豁免、临时目录发布；去掉 DRC `|| true` | ERC/DRC 命令失败与违规两类故障各测试；均不得调用生产导出或覆盖上次可用包 |
| F05 | P1 / 规则未落地已确认 | `design.py::NET_CLASSES`、工程规则生成流程：先批准电流/压降/USB/NFC规则；分类默认宽度与强制最小约束分开实现 | 工程及 DSN 读回分类；故意违反强制约束得到失败；现板按新规则重新检查，不能仅新增分类就声称已满足 |
| F06 | P1 / 独立 PDF 确认偏离 | 讨论 J1.7 Keep Open；若批准修复，先 `design.py`，再同步原理图、PCB与 `route_pcb.py::apply_extra_gnd_pads`；重新验证缝合和网络 | 精确屏版本书面依据或恢复 NC；后处理不会重新接地；网表/焊盘/铜连接/DRC均通过 |
| F07 | P1 / LDO 稳定性风险 | `design.py` U4/C3/C4 及实际物料：核对 XC6220 3.3 V 档 CIN/CL 组合、有效容值和近端回路；不得仅凭 pinout 通过 | 指定电容料号与 DC bias 曲线；低电压到满电、睡眠到射频/刷屏的示波器波形与复位记录 |
| F08 | P1 / 平台缺口确认，路线未选 | 明确目标手机与首版路线：原生 FTM，或 NFC 入口加 BLE/SoftAP；先做最小一图闭环 | 一张非纯色 30,000 B 图从目标手机正确显示；记录时长、掉线与恢复；纯网页 NDEF 不能冒充 FTM |
| F09 | P1（本轮建议提高）/ 显示假成功复现 | `firmware/src/epd.cpp`：传播上电/刷新/关电结果；对确切屏规格管理 BUSY、超时、命令间隔；日志区分失败阶段 | 四色编码仍正确；正常/卡低/卡高/关电超时/刷新超时均有预期结果；实屏验证 BUSY 时序后才能承诺完成 |
| F10 | P2 / ACK 探测已实现，驱动未完成 | `nfc.cpp/.h`：读 UID/型号/系统配置，错误可诊断，GPO 事件配置读回；初始化兼容出厂和改配芯片 | 新芯片、旧配置、地址无响应、I²C故障、RF事件日志；不要把 ACK 当 NDEF/FTM ready |
| F11 | P2 / 协议未开发 | 新增一页协议规范，随后实现有边界的分片接收；8 KB EEPROM 不容纳 30 KB 原图，256 B 邮箱用于交换 | 长度/分包/重复/错序/CRC/超时/断链测试；完整图校验后才刷新；区分收到与显示完成 |
| F12 | P2 / 应用状态与电源管理未闭合 | `main.cpp` 统一状态流；检查 SPI 外设复用、hold 释放、屏关电反灌、GPO 已低时再次睡眠行为 | 所有异常退出路径屏电源关闭；示波器/电流表证实断电无非预期供电；重复唤醒不进入风暴 |
| F13 | P2 / 布线质量需专项审查 | 以当前 PCB 为基线追 USB 端到端路径及回流，检查升压/RESE；按厂商准则提出局部改线范围再讨论 | USB 正反插/不同线缆下载日志、波形或一致性依据；RESE与升压波形；不得以网络总长当差分端到端失配 |
| F14 | P2 / RF 未实测 | 保持线圈阻焊现状；建立 C11 DNP/实装调谐记录；整机含屏、电池、胶、人体测试 | 谐振/读写成功率/方向距离/不同手机壳与机型；模组天线净空审查；不以 DRC 代替 RF 验收 |
| F15 | P2 / 制造资料歧义确认 | 导出工程全量BOM与实际贴装BOM；DNP、ANT1、测试点分类；位置表只保留实际贴装项 | 装配 BOM 位号集合与位置表一致；C11装配策略明确；每个可采购器件锁定料号与允许替代条件 |
| F16 | P1（模型完整性），P2（实装）/ 部分验证通过 | 补 USB 源模型和覆盖检查；机械加入 FPC、翻盖运动、真实电池/导线/胶/执行件；几何失败要阻断发布 | 新环境全部模型可解析；重新导出STEP且源哈希可追溯；零干涉同时给最小间隙与公差；实装照片/尺寸 |
| F17 | P1（电池/充电规格冻结）/ 待定 | 锁定受保护电池、极性、连接器与充电器唯一主料；明确5.1k设定及系统VBAT负载的影响；制定低电行为 | 电芯书面充电条件；电压/负载/温升/终止/恢复数据；无电池USB场景结果，失败也要明确记录 |
| F18 | P1（同步包）/ 当前ZIP内部一致，但B.Silk已证实旧版，见N02 | 每次新建包，统一更新 JSON/RPT，manifest记录源与工具版本；禁止原地更新旧zip当干净发布 | 删除/改名文件的包回归测试；包成员与目录严格一致；同一审查commit的输入/输出SHA256 |
| F19 | P1（旧DRC误读），其余P2 / 部分新增审查工具 | 修复 `route_pcb.py::drc_json` 返回码/旧报告问题；长期建立PCB引脚检查、稳定ID、明确后处理范围 | 命令返回5且已有旧空报告时必须失败；检查器发现注入的引脚错误；无变更生成不产生随机ID噪声 |
| F20 | P2/P3 / 依赖未锁，构建本轮可重复 | 固定已验证PlatformIO平台/包；增加轻量CI；梳理许可、文档引用与二进制追溯；不自行替用户选择项目许可证 | 干净目录构建通过，三份bin与清单对应；文档入口可执行；许可证决定由项目所有者确认 |
| N01 | P1 / 新发现：升压参考值存在未闭合差异 | 官方屏第29页对照 `design.py` L1、C15、GDR泄放、Q1/R14：制作完整偏离表，依据确切料号/波形评估，不自动换件 | 屏供应商参考电路或认可说明；实际饱和电流、DCR、采样功耗/封装依据；满幅四色及低电刷新波形 |
| N02 | P1 / 新发现：旧B.Silk Gerber与当前板不一致 | `output/gerbers/badge-B_Silkscreen.gbr`及旧ZIP：门禁问题处理后重新导出完整一致包；本轮已保留新旧坐标差异证据 | 忽略仅日期的新旧数据对照；发布包包含当前板的背面丝印；禁止仅更新截图或单独留下旧ZIP |

## 3. 按依赖顺序执行，不按日历许诺

### 阶段 A：让错误可见、可停止

工作包 A1：F01/F02/F09，范围限固件启动、睡眠、自检错误表达。先固定本轮可构建依赖，保留 `v0.1` 原二进制作基线，新增修订版本号。不要在此包同时实现 FTM、BLE、UI。

工作包 A2：F04/F18/F19，范围限检查与导出门禁。每个检查都必须有当前输出、返回码与输入指纹。先测试 fail，再测试 pass。全量 warning 不能默认吞掉；按类型、对象、理由、批准人和失效条件登记豁免。检查失败只产生诊断报告，不产生看似可下单的包。

A1/A2完成后才把状态从“缺陷已确认”改为“已修复并测试”。本轮新增的 probes 是诊断工具，部分断言要求旧缺陷确实复现；修复后应转换为防回归期望，不能靠继续通过旧缺陷断言验收新版本。

### 阶段 B：关闭硬件待决项

提交给 Wisdom 的讨论材料应包含：J1.7 两种处理方式及影响；LDO 与升压候选BOM、有效容值和电流依据；电池充电约束；网络规则变化；USB模型及公差来源。先做这些材料，最后才请求批准具体改动。保持四色屏、ESP32-C3、ST25DV、电池+USB、0.8 mm 主架构。

若批准网络/铜皮改变：从 `design.py` 出发，明确是否必须重建板。重建前另存当前布线版本及hash；Freerouting仍严格遵循原交接第3节。若只是文档、阻焊、显示错误修复，不清走线。每次后处理之后再次检查设计网络、原理图网络和PCB焊盘，而不是只看DRC。

### 阶段 C：工程样机闭环

按“电源 → MCU启动/下载 → I²C身份与事件 → 供电/显示 → 深睡唤醒 → 图像传输 → 整机功耗/RF → 装配”的顺序带板。任何一步失败留日志，不继续宣称后续通过。建议先做3块带编号样机，以区分个体焊接问题与系统问题；数量是建议，不是已批准采购。

### 阶段 D：产品功能与维护

只选择一条首版手机传图路线；建立所有权/写入授权窗口、完整性与异常恢复后做姓名、组织、二维码、四色模板。没有目标机型实测不能标“支持iPhone/Android”。批量发布再做治具、离线配置、返修与许可清单。

## 4. 实物测试操作单（尚未执行）

| 测试 | 前置和步骤 | 记录与判定 |
|---|---|---|
| 首次供电 | 电源/电池方案已核准；目检与断电阻值检查；用适合该电路的限流电源分阶段供电 | 板号、输入条件、电流、3V3、屏电源；异常发热/压降立即停止排查 |
| USB | 正反插，至少两条确认支持数据的线缆；冷插、RESET、ROM下载、下载后运行 | 枚举和烧录成功率，串口完整日志；确认9低进ROM，与自检入口分开 |
| LDO | 输入覆盖所选电池有效范围；睡眠到CPU/射频负载、刷屏开关 | VIN/VOUT/电流波形、纹波、超调和复位原因；按器件规格判定 |
| EPD | 先验证电源与BUSY；白/黑/红/黄、边框、条纹、四角编号、二维码 | 颜色/方向/边界、刷新时间与电荷；采样GDR/RESE/高压节点需合适探头；记录超时阶段 |
| NFC | 读型号/UID/配置；RF场进入离开；邮箱通知；重复贴靠 | GPO极性/脉冲/持续状态、事件读回、失败率；避免未清事件导致反复唤醒 |
| 深睡 | USB断开；分别正常睡眠、GPO已低、连续贴靠、RESET恢复 | API返回、原因、100次循环、稳态电流；BOOT不能被写成GPIO9深睡唤醒 |
| 传图 | 一张非纯色黄金图；中途移开/断链/重复/乱序/CRC错误/超长 | 完整图校验前不刷新；收到与显示完成分别ACK；不会越界或显示半图 |
| 电池与充电 | 由实际电芯规格确定电流；覆盖充电中系统负载、低电、保护恢复、无电池USB | 充电电流、终止、温升、恢复路径、极性；不把两个充电器按“引脚相同”默认等价 |
| RF装机 | 裸板/带屏/装壳/佩戴；目标手机、壳厚与方向矩阵 | 谐振与调谐值、读写距离/成功率、Wi-Fi/BLE连接；参数与测试条件一起存档 |
| 机械 | 实际电池PCM/导线/FPC/胶全部放入；插拔USB/FPC、操作翻盖/按键、闭合后盖 | 尺寸、最小间隙、挤压/弯折/卡扣状况；打印材料与参数、装配照片 |
| 续航 | 记录待机电流、一次完整更新电荷、日更新频次、可用容量 | 用测量计算且写条件和误差；90.85 µA/115天只作简化量级参考 |

## 5. 问题关闭模板

```text
编号：Fxx/Nxx
负责人 / 日期：
基准提交 / 修复提交：
触发场景与原始证据：
决定（需批准的附 Wisdom 确认记录）：
修改文件与为何这样改：
工具版本 / 完整命令：
正常路径与故障路径结果：
实测条件 / 日志 / 波形 / 照片 / SHA256：
仍不覆盖的场景：
状态：待决 / 已实现未验证 / 本机验证 / 实机通过 / 已接受偏离
```

任何“已接受偏离”必须列精确型号/版本、适用批次、证据与批准人，不能写“通常没事”。不要把“排上计划”“编译通过”“DRC无error”替代关闭标准。

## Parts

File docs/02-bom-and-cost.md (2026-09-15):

# BOM 与成本估算

机器可读清单由 `hardware/pcb/scripts/classify_bom.py`（读 `design.py`）写出，不要用 KiCad 分组 BOM 当唯一真相：

| 文件 | 用途 |
|---|---|
| `output/badge_bom_engineering.csv` | 工程全量：含 ANT1、TP1–TP4、**C11 DNP** |
| `output/badge_bom_assembly.csv` | 贴装：只含实际 SMT；与 `badge_pos_back_assembly.csv` 位号一致 |
| `output/badge_bom.csv` | 历史 KiCad 分组导出，**会漏掉 C11**，不能当贴装清单 |
| `output/badge_pos_back.csv` | 历史位置表，含 C11；贴装请用 `*_assembly.csv` |

**C11 策略（已写死，首件）：DNP，不贴。** ST25DV 内部 28.5 pF；测线圈谐振后再决定实装容值并记调谐表（F14）。不要让 SMT 按「有位号就贴」。ANT1 是 PCB 铜线圈，不是贴装件。TP1–TP4 是测试焊盘。

U3 充电器已锁 **TP4054**（C32574）。电芯首件：**202545 / 250 mAh / 2.0 mm / 带 PCM**，J2-1=VBAT。下表是人读版本和单件成本估算，价格为 2026 年 9 月立创商城 / 淘宝零售参考价，小批量（1–10 件）口径，仅供预算。

## 主要器件

| 位号 | 器件 | 规格 / 型号 | 数量 | 单价 ¥ | 备注 |
|---|---|---|---|---|---|
| — | 4.2" 四色墨水屏 | GDEM042F86（SSD2683ZA）或 Waveshare 4.2" (G) 裸屏 | 1 | 70–100 | 24P 0.5 mm FPC，91×77×1.0 |
| U1 | Wi-Fi/BLE 模组 | ESP32-C3-MINI-1-N4 | 1 | 12–15 | 2.4 mm 厚，决定整机厚度 |
| U2 | NFC 动态标签 | ST25DV64KC-IER6S3（SO8N） | 1 | 12–16 | 64 Kbit EEPROM，FTM 邮箱，能量采集 |
| U3 | 锂电充电 | TP4054（SOT-23-5）C32574 | 1 | 0.5–1 | R3 = 5.1 kΩ → ≈ 200 mA。不再并列 MCP73831 |
| U4 | LDO 3.3 V | XC6220B331MR-G（SOT-25，Iq 8 µA） | 1 | 2–3 | 近端 CIN C3=10 µF、CL C4=4.7 µF |
| J1 | FPC 连接器 | Hirose FH12-24S-0.5SH 或 JUSHUO AFC07-S24FCA-00 | 1 | 1.5–4 | 24P 0.5 mm 下接翻盖；脚 7 NC |
| J3 | USB-C | HRO TYPE-C-31-M-14，16P 沉板 | 1 | 1–1.5 | LCSC C223907，需 PCB 开槽 9.35×6.05 |
| J2 | 电池座 | JST SM02B-SHLS-TF 1.0 mm 2P | 1 | 0.5–1 | 也可直接焊线；3D 为仓库包络 |
| Q1 | N-MOS | Si1308EDL（SOT-323）C469327 | 1 | 0.3–1 | 符号仍用 AO3400A（GSD 兼容） |
| Q2 | P-MOS | AO3401A（SOT-23） | 1 | 0.3 | 面板电源开关 |
| D1–D3 | 肖特基 | MBR0530（SOD-123） | 3 | 0.2 | 升压 / 电荷泵 |
| L1 | 电感 | 47 µH FNR4018S470MT，4.0×4.0×1.8，Isat 700 mA | 1 | 0.8–2 | LCSC C167813（第 29 页 47 µH/500 mA） |
| R14 | RESE | 2.2 Ω 0603 | 1 | 0.05 | 第 29 页 R2 |
| R15 | GDR 下拉 | 1 MΩ 0402 | 1 | 0.02 | 第 29 页 R1 |
| D4, D5 | LED 0603 | 红（充电）/ 绿（状态） | 2 | 0.2 | |
| SW1, SW2 | 轻触按键 | C&K PTS810，1.5 mm 低矮 | 2 | 0.8 | |
| C15 | 4.7 µF / 25 V | 0805 X5R 飞电容（第 29 页 C3） | 1 | 0.15 | |
| C16–C17 | 1 µF 50 V | 0805 X7R | 2 | 0.15 | VGH / VGL |
| C18–C21 | 1 µF 25 V | 0603 X7R | 4 | 0.08 | VSH1 / VSH2 / VSL / VCOM |
| 其余 R/C | 0402 / 0603 | 见 BOM | ≈ 20 | 0.02–0.1 | |
| — | PCB | 91×84 mm，2 层，0.8 mm，绿油 | 1 | 6–10 | 嘉立创 5 片起 ≈ ¥40（含开槽） |
| — | 锂电池 | 202545，250 mAh，2.0 mm，带 PCM | 1 | 15–25 | J2-1=VBAT。无电池 USB 允许失败并记日志 |
| — | 外壳 | 3D 打印 PETG/ABS 两件 | 1 | 15–30 | 前框 + 后盖，约 15 cm³ |
| — | 挂绳 / 卡扣 | | 1 | 2–5 | |

## 合计（单件）

| 项 | ¥ |
|---|---|
| 屏 | 70–100 |
| 电子料（不含屏） | 40–55 |
| PCB | 6–10 |
| 电池 | 15–25 |
| 外壳 + 挂绳 | 17–35 |
| **合计** | **≈ 150–225** |

对比：Waveshare 2.9" 四色无源 NFC 成品 ≈ ¥190；佳显 4.2" 无源 NFC 单色成品 ≈ ¥200+。
上量到 100 件以上时屏和模组单价下降约 20–30%，PCB+SMT 贴片每片约 ¥25–35。

## 机械件（除 PCB 铜皮外）

屏是外购件，外壳脚本从 `design.py` 读尺寸。CAD：`hardware/enclosure/`（前框+后盖 STL/STEP）。

| 件 | 尺寸 / 规格 | 状态 |
|---|---|---|
| 墨水屏 GDEM042F86 | 外形 **91.00×77.00×1.00** mm；有效区 **84.80×63.60**；左右边框各 3.10；顶/底边框各 **6.70**（`ACTIVE_TOP`）；24P 0.5 mm FPC 从短边下沿出 | 外购。开窗/FPC 槽已按官方第 6 页写入 |
| PCB | **91×84×0.8**（屏下多 7 mm 条放 USB+按键） | 已设计、已布线。嘉立创下 0.8 mm |
| USB 沉板槽 | 9.35×6.05，J3 `(75.0, 81.3)` | 已开槽；座子仍用 M-14 |
| FPC 过板槽 | `(27.0, 77.6)–(57.0, 79.6)` | 已开槽；J1 翻盖朝槽 |
| 电池仓 | 板上禁布 `(3,3)–(50,53)`，厚 **≤2.0** mm；首件 **202545 250 mAh 带 PCM** | 口袋已开，料号已锁 |
| 前框 + 后盖 | 约 **94×93×6.3** mm；AA 开窗；挂绳槽 16×2.6；RST/BOOT 后盖孔；USB 底边开口 | STL/STEP 已出，按 `BOARD_THICKNESS=0.8` |
| 挂绳 / 卡扣 | 用前框槽 | 外购，无单独零件图 |
| 屏贴胶 | 屏贴 PCB 正面，仅非 AA 边框 | 首件 **3M 467MP**（0.06 mm）。PETG 粘框改 300LSE。见 [09-process.md](09-process.md) |

## 选型说明与替代

- **屏**：接口按 Good Display 24P 标准引脚定义。GDEY042F51（HX8717）已 EOL，GDEM042F52（JD79668）也已 EOL，
  现行为 GDEM042F86（SSD2683ZA）；Waveshare 4.2" (G) 模组的裸屏同样可用。三者硬件兼容，固件驱动不同。
- **RESE（R14）**：GDEM042F86 官方第 29 页参考电路 R2=**2.2 Ω**（已按此下）。换别的 4.2" 面板再核对该屏规格书。
- **LDO**：XC6220 引脚（VIN/VSS/CE/NC/VOUT）与 AP2112K、TLV75533 一致；封装用 AP2112K 的 SOT-23-5。焊接前核对。
- **USB-C**：HRO TYPE-C-31-M-14（C223907）产品页写沉板 **0.75 mm**。嘉立创/JLCPCB 两层标准档无 0.75，
  v1 **按 0.8 mm 下单**（2026-09-14）。0.8 mm 公差 ±0.1 mm，实物可落到 0.75。不要改 1.0 mm（须换座）。
- **电池**：必须自带保护板（PCM），板上没有独立的过放/过流保护。

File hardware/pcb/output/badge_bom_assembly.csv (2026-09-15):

Ref | Value | Footprint | Description | LCSC | Qty
C1 | 4.7u | Capacitor_SMD:C_0603_1608Metric | 4.7uF 10V X5R 0603 |  | 1
C10 | 1u | Capacitor_SMD:C_0402_1005Metric | 1u 0402 |  | 1
C12 | 10u | Capacitor_SMD:C_0603_1608Metric | 10uF 6.3V X5R 0603 |  | 1
C13 | 1u | Capacitor_SMD:C_0402_1005Metric | 1u 0402 |  | 1
C14 | 1u | Capacitor_SMD:C_0402_1005Metric | 1u 0402 |  | 1
C15 | 4.7u/25V | Capacitor_SMD:C_0805_2012Metric | 4.7uF 25V X5R 0805 flying cap (GDEM042F86 p.29 C3) |  | 1
C16 | 1u/50V | Capacitor_SMD:C_0805_2012Metric | 1uF 50V X7R 0805 |  | 1
C17 | 1u/50V | Capacitor_SMD:C_0805_2012Metric | 1uF 50V X7R 0805 |  | 1
C18 | 1u/25V | Capacitor_SMD:C_0603_1608Metric | 1uF 25V X7R 0603 |  | 1
C19 | 1u/25V | Capacitor_SMD:C_0603_1608Metric | 1uF 25V X7R 0603 |  | 1
C2 | 4.7u | Capacitor_SMD:C_0603_1608Metric | 4.7uF 10V X5R 0603 |  | 1
C20 | 1u/25V | Capacitor_SMD:C_0603_1608Metric | 1uF 25V X7R 0603 |  | 1
C21 | 1u/25V | Capacitor_SMD:C_0603_1608Metric | 1uF 25V X7R 0603 |  | 1
C3 | 10u | Capacitor_SMD:C_0603_1608Metric | 10uF 6.3V X5R 0603 LDO CIN (Torex table, 3.3V with CL=4.7uF) |  | 1
C4 | 4.7u | Capacitor_SMD:C_0603_1608Metric | 4.7uF 10V X5R 0603 LDO CL near VOUT (Torex 3.00-3.50V + CIN=10uF) |  | 1
C5 | 100n | Capacitor_SMD:C_0402_1005Metric | 100n 0402 |  | 1
C6 | 10u | Capacitor_SMD:C_0603_1608Metric | 10uF 6.3V X5R 0603 |  | 1
C7 | 100n | Capacitor_SMD:C_0402_1005Metric | 100n 0402 |  | 1
C8 | 1u | Capacitor_SMD:C_0402_1005Metric | 1u 0402 |  | 1
C9 | 100n | Capacitor_SMD:C_0402_1005Metric | 100n 0402 |  | 1
D1 | MBR0530 | Diode_SMD:D_SOD-123 | Schottky 30V 0.5A SOD-123 | C77896 | 1
D2 | MBR0530 | Diode_SMD:D_SOD-123 | Schottky 30V 0.5A SOD-123 | C77896 | 1
D3 | MBR0530 | Diode_SMD:D_SOD-123 | Schottky 30V 0.5A SOD-123 | C77896 | 1
D4 | RED | LED_SMD:LED_0603_1608Metric | LED 0603 red, charging indicator |  | 1
D5 | GREEN | LED_SMD:LED_0603_1608Metric | LED 0603 green, status |  | 1
J1 | EPD FPC 24P 0.5mm | Connector_FFC-FPC:Hirose_FH12-24S-0.5SH_1x24-1MP_P0.50mm_Horizontal | 24P 0.5mm FPC connector, bottom contact, flip lock (Hirose FH12-24S-0.5SH or JUSHUO AFC07-S24FCA-00). Pin 7 NC Keep Open (GDEM042F86 p.7). | C262657 | 1
J2 | BATT JST-SHL 1.0mm | badge:JST_SHL_SM02B-SHLS-TF_1x02-1MP_P1.00mm_Horizontal | JST SM02B-SHLS-TF 1.0mm 2P; pin1=VBAT red, pin2=GND; cell 202545 250mAh 2.0mm with PCM | C145956 | 1
J3 | USB-C 16P 沉板 (TYPE-C-31-M-14) | badge:TYPE-C-31-M-14 | HRO TYPE-C-31-M-14, 16P USB 2.0 mid-mount receptacle | C223907 | 1
L1 | 47uH | Inductor_SMD:L_Changjiang_FNR4018S | 47uH shielded, Isat 700mA Irms 650mA, 4.0x4.0x1.8mm FNR4018S470MT (GDEM042F86 p.29 47uH/500mA) | C167813 | 1
Q1 | Si1308EDL | Package_TO_SOT_SMD:SOT-323_SC-70 | Vishay Si1308EDL-T1-GE3 N-MOS 30V SOT-323 GSD (GDEM042F86 p.29). Symbol AO3400A is pin-compatible GSD. | C469327 | 1
Q2 | AO3401A | Package_TO_SOT_SMD:SOT-23 | P-MOSFET load switch for panel + boost | C15127 | 1
R1 | 5.1k | Resistor_SMD:R_0402_1005Metric | 5.1k 0402 1% |  | 1
R10 | 10k | Resistor_SMD:R_0402_1005Metric | 10k 0402 1% |  | 1
R11 | 4.7k | Resistor_SMD:R_0402_1005Metric | 4.7k 0402 1% |  | 1
R12 | 4.7k | Resistor_SMD:R_0402_1005Metric | 4.7k 0402 1% |  | 1
R13 | 100k | Resistor_SMD:R_0402_1005Metric | 100k 0402 1% |  | 1
R14 | 2.2R | Resistor_SMD:R_0603_1608Metric | RESE 2.2 ohm 0603 >=0.1W (GDEM042F86 p.29; 0402 pulse rating not locked) |  | 1
R15 | 1M | Resistor_SMD:R_0402_1005Metric | GDR 1M pulldown to GND (GDEM042F86 p.29 R1) |  | 1
R2 | 5.1k | Resistor_SMD:R_0402_1005Metric | 5.1k 0402 1% |  | 1
R3 | 5.1k | Resistor_SMD:R_0402_1005Metric | 5.1k -> ~200mA charge current |  | 1
R4 | 1k | Resistor_SMD:R_0402_1005Metric | 1k 0402 1% |  | 1
R5 | 1M | Resistor_SMD:R_0402_1005Metric | 1M 0402 1% |  | 1
R6 | 1M | Resistor_SMD:R_0402_1005Metric | 1M 0402 1% |  | 1
R7 | 10k | Resistor_SMD:R_0402_1005Metric | 10k 0402 1% |  | 1
R8 | 10k | Resistor_SMD:R_0402_1005Metric | 10k 0402 1% |  | 1
R9 | 1k | Resistor_SMD:R_0402_1005Metric | 1k 0402 1% |  | 1
SW1 | RESET | Button_Switch_SMD:SW_SPST_PTS810 | C&K PTS810 low-profile tactile 1.5mm | C221929 | 1
SW2 | BOOT/USER | Button_Switch_SMD:SW_SPST_PTS810 | C&K PTS810 low-profile tactile 1.5mm | C221929 | 1
U1 | ESP32-C3-MINI-1-N4 | badge:ESP32-C3-MINI-1 | Espressif ESP32-C3-MINI-1-N4 Wi-Fi/BLE module, 13.2x16.6x2.4mm | C2934569 | 1
U2 | ST25DV64KC-IER6S3 | Package_SO:SOIC-8_3.9x4.9mm_P1.27mm | ST25DV64KC dynamic NFC tag, 64Kbit, FTM mailbox, energy harvesting, SO8N | C2830253 | 1
U3 | TP4054 | Package_TO_SOT_SMD:SOT-23-5 | TP4054 Li-ion linear charger 4.2V SOT-23-5; R3=5.1k -> ~200mA. Not MCP73831. | C32574 | 1
U4 | XC6220B331MR-G | Package_TO_SOT_SMD:SOT-23-5 | LDO 3.3V Iq 8uA 1A SOT-25 VIN/GND/CE/NC/VOUT. Torex 3.0-3.5V pair: CIN=10uF CL=4.7uF near U4. | C86534 | 1

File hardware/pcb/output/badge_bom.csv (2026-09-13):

Ref | Value | Footprint | Description | LCSC | Qty | DNP
ANT1 | PCB loop 35x41.5mm 11T | badge:NFC_Loop | PCB spiral antenna, net-tie footprint generated by gen_nfc_footprint.py; tune with C11 |  | 1
C1,C2 | 4.7u | Capacitor_SMD:C_0603_1608Metric | 4.7uF 10V X5R 0603 |  | 2
C3,C8,C10,C13,C14 | 1u | Capacitor_SMD:C_0402_1005Metric | 1u 0402 |  | 5
C4 | 2.2u | Capacitor_SMD:C_0603_1608Metric | 2.2uF 10V 0603 |  | 1
C5,C7,C9 | 100n | Capacitor_SMD:C_0402_1005Metric | 100n 0402 |  | 3
C6,C12 | 10u | Capacitor_SMD:C_0603_1608Metric | 10uF 6.3V X5R 0603 |  | 2
C15-C17 | 1u/50V | Capacitor_SMD:C_0805_2012Metric | 1uF 50V X7R 0805,1uF 50V X7R 0805 charge pump |  | 3
C18-C21 | 1u/25V | Capacitor_SMD:C_0603_1608Metric | 1uF 25V X7R 0603 |  | 4
D1-D3 | MBR0530 | Diode_SMD:D_SOD-123 | Schottky 30V 0.5A SOD-123 | C77896 | 3
D4 | RED | LED_SMD:LED_0603_1608Metric | LED 0603 red, charging indicator |  | 1
D5 | GREEN | LED_SMD:LED_0603_1608Metric | LED 0603 green, status |  | 1
J1 | EPD FPC 24P 0.5mm | Connector_FFC-FPC:Hirose_FH12-24S-0.5SH_1x24-1MP_P0.50mm_Horizontal | 24P 0.5mm FPC connector, bottom contact, flip lock (Hirose FH12-24S-0.5SH or JUSHUO AFC07-S24FCA-00) | C262657 | 1
J2 | BATT JST-SH 1.0mm | Connector_JST:JST_SHL_SM02B-SHLS-TF_1x02-1MP_P1.00mm_Horizontal | JST SM02B-SHLS-TF 1.0mm 2P horizontal; LiPo <=2.0mm thick, 150-300mAh with PCM | C145956 | 1
J3 | USB-C 16P 沉板 (TYPE-C-31-M-14) | badge:TYPE-C-31-M-14 | HRO TYPE-C-31-M-14, 16P USB 2.0 mid-mount receptacle | C223907 | 1
L1 | 68uH | Inductor_SMD:L_Changjiang_FNR3015S | 68uH shielded power inductor, Isat>=0.2A, h<=1.5mm (Sunlord SWPA3015S680MT / FNR3015S680MT) | C2827366 | 1
Q1 | AO3400A | Package_TO_SOT_SMD:SOT-23 | N-MOSFET for EPD boost (alt. Si1304BDL SOT-323) | C20917 | 1
Q2 | AO3401A | Package_TO_SOT_SMD:SOT-23 | P-MOSFET load switch for panel + boost | C15127 | 1
R1-R3 | 5.1k | Resistor_SMD:R_0402_1005Metric | 5.1k -> ~200mA charge current,5.1k 0402 1% |  | 3
R4,R9 | 1k | Resistor_SMD:R_0402_1005Metric | 1k 0402 1% |  | 2
R5,R6 | 1M | Resistor_SMD:R_0402_1005Metric | 1M 0402 1% |  | 2
R7,R8,R10 | 10k | Resistor_SMD:R_0402_1005Metric | 10k 0402 1% |  | 3
R11,R12 | 4.7k | Resistor_SMD:R_0402_1005Metric | 4.7k 0402 1% |  | 2
R13 | 100k | Resistor_SMD:R_0402_1005Metric | 100k 0402 1% |  | 1
R14 | 2.2R | Resistor_SMD:R_0402_1005Metric | RESE current-sense resistor: confirm value from GDEM042F86 spec (0.47R / 2.2R / 3R variants) |  | 1
SW1 | RESET | Button_Switch_SMD:SW_SPST_PTS810 | C&K PTS810 low-profile tactile 1.5mm | C221929 | 1
SW2 | BOOT/USER | Button_Switch_SMD:SW_SPST_PTS810 | C&K PTS810 low-profile tactile 1.5mm | C221929 | 1
TP1 | V_EH | TestPoint:TestPoint_Pad_D1.0mm | test pad (energy harvesting output) |  | 1
TP2 | 3V3 | TestPoint:TestPoint_Pad_D1.0mm | test pad |  | 1
TP3 | GND | TestPoint:TestPoint_Pad_D1.0mm | test pad |  | 1
TP4 | VBAT | TestPoint:TestPoint_Pad_D1.0mm | test pad |  | 1
U1 | ESP32-C3-MINI-1-N4 | badge:ESP32-C3-MINI-1 | Espressif ESP32-C3-MINI-1-N4 Wi-Fi/BLE module, 13.2x16.6x2.4mm | C2934569 | 1
U2 | ST25DV64KC-IER6S3 | Package_SO:SOIC-8_3.9x4.9mm_P1.27mm | ST25DV64KC dynamic NFC tag, 64Kbit, FTM mailbox, energy harvesting, SO8N | C2830253 | 1
U3 | TP4054 / MCP73831T-2ACI/OT | Package_TO_SOT_SMD:SOT-23-5 | Li-ion linear charger 4.2V, SOT-23-5 (TP4054 pin-compatible) | C32574 | 1
U4 | XC6220B331MR-G | Package_TO_SOT_SMD:SOT-23-5 | LDO 3.3V, Iq 8uA, 1A, SOT-25 (pinout VIN/GND/CE/NC/VOUT). Alt: TLV75533PDBV, AP2112K-3.3 | C86534 | 1

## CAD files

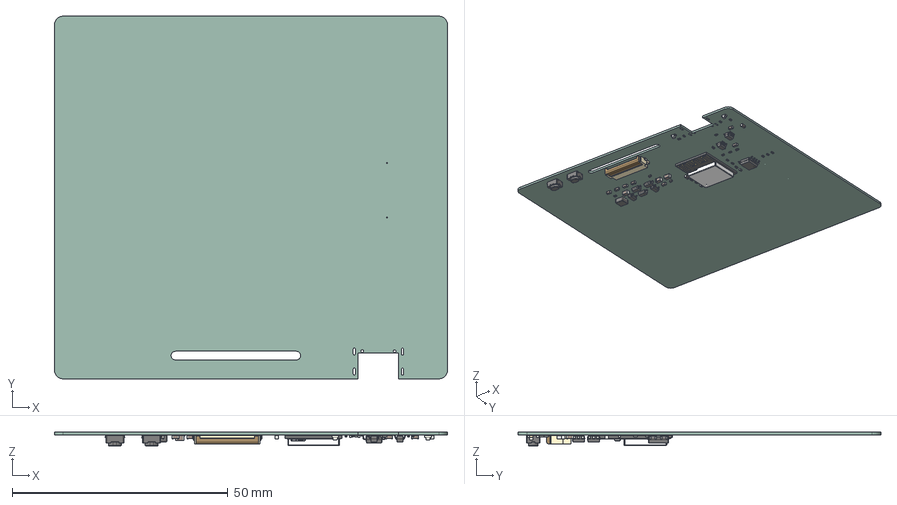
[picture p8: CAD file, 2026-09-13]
hardware/pcb/output/badge_full.step
91.0 x 84.0 x 3.29 mm
SW_SPST_PTS810 x 2
C_0603_1608Metric x 9
C_0402_1005Metric x 8
R_0402_1005Metric x 14
SOT-23-5 x 2
C_0805_2012Metric x 3
SOT-23 x 2
SOIC-8_3.9x4.9mm_P1.27mm
L_Changjiang_FNR3015S
D_SOD-123 x 3
LED_0603_1608Metric x 2
DFN1006.STEP^DFN1006.STEP_Submodel-SOD882_part_DesignRootModel_PCB_ ESP32-C3-MINI-1_V1(2)_PCB_ESP32-C3-MINI-1_V1
R0201_20210301.STEP^R0201_20210301.STEP_Submodel-R0201_part_ DesignRootModel_PCB_ESP32-C3-MINI-1_V1(2)_PCB_ESP32-C3-MINI-1_V1 x 3
placementOutline^Submodel-noModelForPart_MINI-ANT-TYPED-H_1968823293_ Submodel-MINI-ANT-TYPED-H_1968823293_part_DesignRootModel_PCB_ ESP32-C3-MINI-1_V1(2)_PCB_E
placementOutline-0^Submodel-noModelForPart_MINI-ANT-TYPED-H_1968823293_ Submodel-MINI-ANT-TYPED-H_1968823293_part_DesignRootModel_PCB_ ESP32-C3-MINI-1_V1(2)_PCB
placementOutline-1^Submodel-noModelForPart_MINI-ANT-TYPED-H_1968823293_ Submodel-MINI-ANT-TYPED-H_1968823293_part_DesignRootModel_PCB_ ESP32-C3-MINI-1_V1(2)_PCB
placementOutline-2^Submodel-noModelForPart_MINI-ANT-TYPED-H_1968823293_ Submodel-MINI-ANT-TYPED-H_1968823293_part_DesignRootModel_PCB_ ESP32-C3-MINI-1_V1(2)_PCB
placementOutline-3^Submodel-noModelForPart_MINI-ANT-TYPED-H_1968823293_ Submodel-MINI-ANT-TYPED-H_1968823293_part_DesignRootModel_PCB_ ESP32-C3-MINI-1_V1(2)_PCB
placementOutline-4^Submodel-noModelForPart_MINI-ANT-TYPED-H_1968823293_ Submodel-MINI-ANT-TYPED-H_1968823293_part_DesignRootModel_PCB_ ESP32-C3-MINI-1_V1(2)_PCB
placementOutline-5^Submodel-noModelForPart_MINI-ANT-TYPED-H_1968823293_ Submodel-MINI-ANT-TYPED-H_1968823293_part_DesignRootModel_PCB_ ESP32-C3-MINI-1_V1(2)_PCB
trace_4^Submodel-MINI-ANT-TYPED-H_1968823293_part_DesignRootModel_PCB_ ESP32-C3-MINI-1_V1(2)_PCB_ESP32-C3-MINI-1_V1
trace_1^Submodel-MINI-ANT-TYPED-H_1968823293_part_DesignRootModel_PCB_ ESP32-C3-MINI-1_V1(2)_PCB_ESP32-C3-MINI-1_V1
C0402_20210301.STEP^C0402_20210301.STEP_Submodel-C0402_part_ DesignRootModel_PCB_ESP32-C3-MINI-1_V1(2)_PCB_ESP32-C3-MINI-1_V1
C0201_20210301.STEP^C0201_20210301.STEP_Submodel-C0201_part_ DesignRootModel_PCB_ESP32-C3-MINI-1_V1(2)_PCB_ESP32-C3-MINI-1_V1 x 11
L0201_20210301.STEP^L0201_20210301.STEP_Submodel-L0201_part_ DesignRootModel_PCB_ESP32-C3-MINI-1_V1(2)_PCB_ESP32-C3-MINI-1_V1 x 2
XTAL3225_20210301.STEP^XTAL3225_20210301.STEP_Submodel-XTAL3225_part_ DesignRootModel_PCB_ESP32-C3-MINI-1_V1(2)_PCB_ESP32-C3-MINI-1_V1
ESP32-C3_20210301.STEP^ESP32-C3_20210301.STEP_Submodel-QFN32_0P5_5_ part_DesignRootModel_PCB_ESP32-C3-MINI-1_V1(2)_PCB_ESP32-C3-MINI-1_V1
uid__4^DesignRootModel_PCB_ESP32-C3-MINI-1_V1(2)_PCB_ESP32-C3-MINI-1_ V1
uid__4-22^DesignRootModel_PCB_ESP32-C3-MINI-1_V1(2)_PCB_ ESP32-C3-MINI-1_V1
uid__4-23^DesignRootModel_PCB_ESP32-C3-MINI-1_V1(2)_PCB_ ESP32-C3-MINI-1_V1
uid__4-24^DesignRootModel_PCB_ESP32-C3-MINI-1_V1(2)_PCB_ ESP32-C3-MINI-1_V1
uid__4-25^DesignRootModel_PCB_ESP32-C3-MINI-1_V1(2)_PCB_ ESP32-C3-MINI-1_V1
uid__4-26^DesignRootModel_PCB_ESP32-C3-MINI-1_V1(2)_PCB_ ESP32-C3-MINI-1_V1
uid__4-27^DesignRootModel_PCB_ESP32-C3-MINI-1_V1(2)_PCB_ ESP32-C3-MINI-1_V1
uid__4-28^DesignRootModel_PCB_ESP32-C3-MINI-1_V1(2)_PCB_ ESP32-C3-MINI-1_V1
uid__4-29^DesignRootModel_PCB_ESP32-C3-MINI-1_V1(2)_PCB_ ESP32-C3-MINI-1_V1
uid__4-30^DesignRootModel_PCB_ESP32-C3-MINI-1_V1(2)_PCB_ ESP32-C3-MINI-1_V1
uid__4-31^DesignRootModel_PCB_ESP32-C3-MINI-1_V1(2)_PCB_ ESP32-C3-MINI-1_V1
uid__4-32^DesignRootModel_PCB_ESP32-C3-MINI-1_V1(2)_PCB_ ESP32-C3-MINI-1_V1
uid__4-33^DesignRootModel_PCB_ESP32-C3-MINI-1_V1(2)_PCB_ ESP32-C3-MINI-1_V1
uid__4-34^DesignRootModel_PCB_ESP32-C3-MINI-1_V1(2)_PCB_ ESP32-C3-MINI-1_V1
uid__4-35^DesignRootModel_PCB_ESP32-C3-MINI-1_V1(2)_PCB_ ESP32-C3-MINI-1_V1
uid__4-36^DesignRootModel_PCB_ESP32-C3-MINI-1_V1(2)_PCB_ ESP32-C3-MINI-1_V1
uid__4-37^DesignRootModel_PCB_ESP32-C3-MINI-1_V1(2)_PCB_ ESP32-C3-MINI-1_V1
uid__4-38^DesignRootModel_PCB_ESP32-C3-MINI-1_V1(2)_PCB_ ESP32-C3-MINI-1_V1
uid__4-39^DesignRootModel_PCB_ESP32-C3-MINI-1_V1(2)_PCB_ ESP32-C3-MINI-1_V1
uid__4-40^DesignRootModel_PCB_ESP32-C3-MINI-1_V1(2)_PCB_ ESP32-C3-MINI-1_V1
uid__4-41^DesignRootModel_PCB_ESP32-C3-MINI-1_V1(2)_PCB_ ESP32-C3-MINI-1_V1
uid__4-42^DesignRootModel_PCB_ESP32-C3-MINI-1_V1(2)_PCB_ ESP32-C3-MINI-1_V1
uid__4-43^DesignRootModel_PCB_ESP32-C3-MINI-1_V1(2)_PCB_ ESP32-C3-MINI-1_V1
uid__4-44^DesignRootModel_PCB_ESP32-C3-MINI-1_V1(2)_PCB_ ESP32-C3-MINI-1_V1
uid__4-45^DesignRootModel_PCB_ESP32-C3-MINI-1_V1(2)_PCB_ ESP32-C3-MINI-1_V1
uid__4-46^DesignRootModel_PCB_ESP32-C3-MINI-1_V1(2)_PCB_ ESP32-C3-MINI-1_V1
uid__4-47^DesignRootModel_PCB_ESP32-C3-MINI-1_V1(2)_PCB_ ESP32-C3-MINI-1_V1
uid__4-48^DesignRootModel_PCB_ESP32-C3-MINI-1_V1(2)_PCB_ ESP32-C3-MINI-1_V1
uid__4-49^DesignRootModel_PCB_ESP32-C3-MINI-1_V1(2)_PCB_ ESP32-C3-MINI-1_V1
uid__4-50^DesignRootModel_PCB_ESP32-C3-MINI-1_V1(2)_PCB_ ESP32-C3-MINI-1_V1
uid__4-51^DesignRootModel_PCB_ESP32-C3-MINI-1_V1(2)_PCB_ ESP32-C3-MINI-1_V1
uid__4-52^DesignRootModel_PCB_ESP32-C3-MINI-1_V1(2)_PCB_ ESP32-C3-MINI-1_V1
uid__4-53^DesignRootModel_PCB_ESP32-C3-MINI-1_V1(2)_PCB_ ESP32-C3-MINI-1_V1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

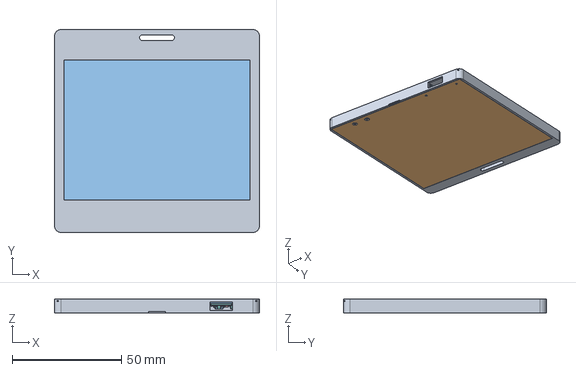
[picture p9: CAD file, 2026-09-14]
hardware/enclosure/output/badge_assembly.step
94.0 x 93.0 x 6.30 mm

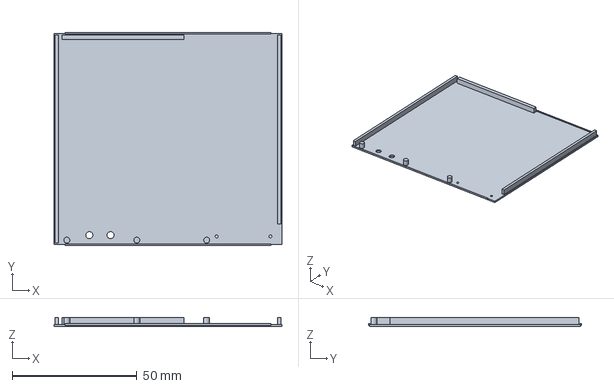
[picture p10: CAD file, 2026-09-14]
hardware/enclosure/output/badge_back_cover.step
91.3 x 85.2 x 3.50 mm

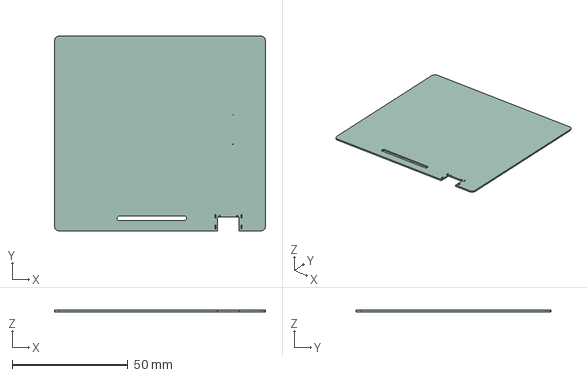
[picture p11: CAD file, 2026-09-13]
hardware/pcb/output/badge_board_only.step
91.0 x 84.0 x 0.71 mm

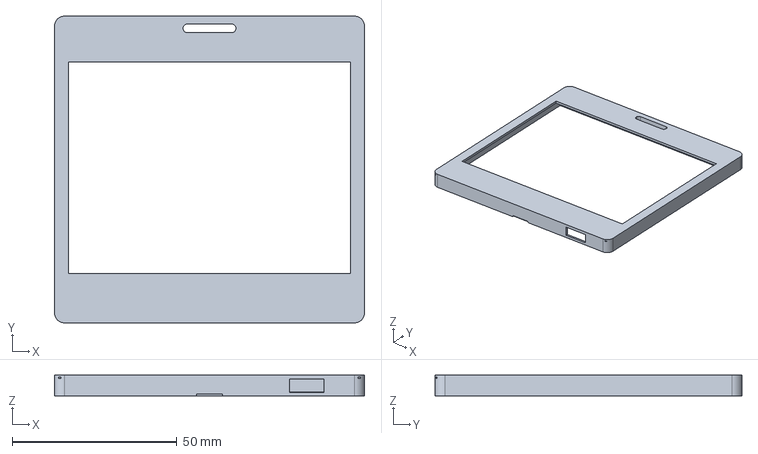
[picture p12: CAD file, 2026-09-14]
hardware/enclosure/output/badge_front_frame.step
94.0 x 93.0 x 6.30 mm

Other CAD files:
hardware/enclosure/output/badge_assembly.FCStd
hardware/enclosure/output/badge_back_cover.FCStd
hardware/enclosure/output/badge_back_cover.stl
hardware/enclosure/output/badge_front_frame.FCStd
hardware/enclosure/output/badge_front_frame.stl

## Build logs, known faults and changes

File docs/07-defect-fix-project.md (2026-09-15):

# BADGE-42C 产品缺陷修复项目（先硬件，后固件）

日期：2026-09-15。依据：[当前状态](06-current-status.md)、[合并计划](reviews/2026-09-14/integrated-plan.md)、[本机复审](reviews/2026-09-14/local-review.md)、[r2 复跑](reviews/2026-09-14-r2/rerun.md)。

**Wisdom 指定执行顺序：先修硬件，再修产品固件。** 审查原文曾建议先做固件错误可见（A1），那是为了实机调试时不被假成功骗过；本文件按你选定的「硬件先行」排期。架构不改：四色屏、ESP32-C3、ST25DV、电池+USB、板厚 0.8 mm。

硬件/固件内容基准：旧板 `ee978f0`；**H2 当前板** 680 段 / 115 过孔。KiCad 10.0.6 **全量 ERC/DRC 0**。仍不是生产包。

本文件记录修复项目。H2 规格项已按 2026-09-15 Wisdom「矫枉必须过正」授权改到 `design.py` 并重布。USB 0.8 mm、NFC 线圈盖绿油仍不重开。

---

## 1. 现在进度（一句话）

| 层 | 做到哪 | 没做到哪 |
|---|---|---|
| 设计 | 原理图/PCB/外壳/v0.2 自检可构建 | 未下单、无实物 |
| 检查 | H1 门禁；KiCad 10 全量 0；GitHub CI（网表/探针/pio） | 无生产 zip；CI ≠ DRC |
| 固件 | v0.2 F1；平台钉 7.1.3；v0.1 bin 保留 | 无实机；无 NDEF/FTM |
| 流程 | LICENSE.md、贴胶 467MP、08 已关闭拍板 | F08 路线未选 |
| 硬件 H2 | 脚7 NC、升压第29页、LDO 近端电容、TP4054+202545、Power/NFC 宽度、包络 3D | 无实机；候选≠生产 |

---

## 2. H2 规格项（2026-09-15 已按授权落地）

原「必须先问再动铜皮」表已执行。USB 0.8 mm、NFC 线圈盖绿油：**已决策，不重开。**

| 编号 | 落地 |
|---|---|
| F06 | J1.7 NC Keep Open；`apply_extra_gnd_pads` 禁止再接地 |
| N01 | L1=47µH FNR4018S470MT；C15=4.7µF/25V；R15=1M；Q1=Si1308EDL；R14=2.2Ω 0603 |
| F07 | C3=10µF CIN、C4=4.7µF CL |
| F17 | U3=TP4054；电芯 202545 250mAh 2.0mm PCM |
| F05 | Power 走线 ≥0.3 mm（GND 以铺铜为电流路径）；NFC 0.5 mm。Freerouting 会收细，`enforce_netclass_widths` 后处理 |
| F03 | ADR 续航改为待测 |
| F16 | J3/J2 包络 STEP 在仓库；包络 ≠ 官方 CAD |

---

## 3. 硬件修复怎么排（本阶段）

原则：能不动铜皮就不动；`gen_pcb.py` 会清全部布线，禁止当普通检查。Freerouting 仅在 Wisdom 批准铜皮/焊盘/板框变化后，按交接第 3 节交互 shell + 相对路径。

### 工作包 H1 — 检查与制造门禁（建议最先，几乎不改电路）

不修这些就不要声称「可以下 Gerber」。

| 编号 | 改哪里 | 注意 |
|---|---|---|
| F04 | `hardware/pcb/scripts/export.sh` | **已实现门禁**：去掉 DRC `\|\| true`；`--exit-code-violations`；失败非零；失败不写 zip。`--production` 直接拒绝 |
| F19 | `route_pcb.py::drc_json` | **已实现**：每次新文件；rc 非 0/5 或无新报告则抛错，不读旧 `drc_tmp.json` |
| F18 / N02 | 制造包流程 | **已实现候选流**：`output/exports/<stamp>-candidate/` 新目录+新 zip；不碰 `output/gerbers` 与旧 zip。**不是生产发布** |
| F15 | BOM/位置 | **已实现分类**：`badge_bom_engineering.csv` / `badge_bom_assembly.csv`；C11 首件 DNP |
| F16（模型） | `lib/3d/README.md` + `check_3d_models.py` | **H2 包络 STEP 已就位**（≠ 官方 CAD）。`--fail-missing` 0。STEP rc=0 ≠ 装配覆盖 |

**本机验收（无板）：** `fault_probes` 断言已改为 fail-closed。全量 warning 进 [drc-warning-register.md](hardware/drc-warning-register.md)，**全部未豁免**。H2/H3 提问见 [08-h2-h3-questions.md](08-h2-h3-questions.md)。

H1 关闭范围：检查/导出**流程**。H2 规格已落地。仍不关闭「可下生产 Gerber」。

### 工作包 H2 — 规格冻结后的原理图/BOM（**已执行 2026-09-15**）

入口 `design.py` → `gen_schematic.py` → 备份旧板 → `gen_pcb.py` → Freerouting → 缝合 → 宽度后处理。不要手改 `.kicad_sch`。

- 当前板 680/115。KiCad 10.0.6 全量 ERC/DRC 0。旧指纹 `2d96f275…` 的板在 `agent-tools/badge-pre-h2.kicad_pcb`。
- 丝印与 schematic_parity 已在活板清零。禁止为丝印再 Freerouting。

### 工作包 H3 — 不改电路、但要登记的硬件债

| 编号 | 做什么 | 不要做什么 |
|---|---|---|
| F13 | 追 USB D+/D− 端到端和回流，写审查笔记 | 不要用网络总长当差分失配；未批准不要重布 USB |
| F14 | C11 DNP/实装调谐表 | 不要为了 3D 好看重开线圈阻焊 |
| F03 硬件侧 | ADR 已改为待测 | 未测电流不要编新的虚假续航数字 |

外壳 FPC/胶/真电池包络：有板再测，H 阶段只补模型与文档，不宣称装配通过。

---

## 4. 固件修复怎么排（硬件门禁和规格讨论之后）

保留 `firmware/output/badge-42c-v0.1.bin` 作基线，新版本升号（如 v0.2），不要覆盖 v0.1 三份 bin 当「没变过」。修完后 `host_probes` **必须改期望**：BUSY 恒高、关电超时不得再报成功。

### 工作包 F1 — 让错误可见（先于收图）

| 编号 | 文件 | 怎么修 | 注意 |
|---|---|---|---|
| F01 | `firmware/src/main.cpp::go_sleep` | **已改**：mask 仅 GPIO1；检查返回值 | 无实机 100 次 GPO 唤醒 |
| F02 | `setup` + `firmware/README.md` | **已改**：USB 就绪后 5 s 内发 `W`；BOOT+RESET = ROM 下载 | 冷启动/RESET/烧录后未实机复测 |
| F09 | `firmware/src/epd.cpp` | **已改**：BUSY 须 LOW→HIGH；上电/刷新/关电进返回值；`last_fail` 阶段名 | 第 31 页 OTP 未推翻；实屏时序未测 |
| F12 | `main.cpp` 状态 | 失败路径仍 `power_off()` 拉高 `EPD_PWR_EN` | 反灌/hold 要实机 |

本包 **不要** 同时做 NDEF、FTM、BLE、工牌 UI。

### 工作包 F2 — NFC 与一图（F1 之后）

| 编号 | 内容 |
|---|---|
| F10 | UID/型号/配置可读回；ACK ≠ FTM ready |
| F08 | Wisdom 选定 **一条** 路线：原生 FTM **或** NDEF 打开页再 BLE/SoftAP。Chrome Web NFC **不能**当 FTM 邮箱 |
| F11 | 30 KB 图 > 8 KB EEPROM；256 B 邮箱分片；校验完再刷屏；半图不显示 |
| F20 | 锁定已验证的 PlatformIO 平台版本；许可证见 `LICENSE.md`（硬件 CERN-OHL-P-2.0，固件 MIT）；CI 见 `.github/workflows/ci.yml` |

---

## 5. 验收用词（禁止混用）

| 说法 | 含义 |
|---|---|
| 已讨论 / 已批准偏离 | 有 Wisdom 记录、型号版本、批次 |
| 已实现 | 代码或 `design.py` 已改 |
| 本机验证 | 隔离审查/编译/探针按 **新** 期望通过 |
| 实机通过 | 有板号、条件、日志/波形 |
| 生产包 | 门禁通过后的新 zip+manifest；诊断 Gerber 不算 |

关闭模板仍用合并计划第 5 节。不要用「排上计划」「编译过了」「DRC 无 error」代替关闭。

---

## 6. 下一会话（H1/F1 已完成后）

硬件门禁与 F1 源码已落地。新会话用 [03-handoff.md](03-handoff.md) 文首粘贴块。

仍未覆盖：实机、生产包、F2 传图。F08 须 Wisdom 选定路线。

---

## 7. 建议的检查点

1. CI 绿（网表 / host_probes / pio）≠ 全量 DRC ≠ 生产包。
2. H2 规格已落地，不要再问 F06/N01/F07/F17。
3. 有板之后才做合并计划第 4 节实物单；未测项保持待验证。

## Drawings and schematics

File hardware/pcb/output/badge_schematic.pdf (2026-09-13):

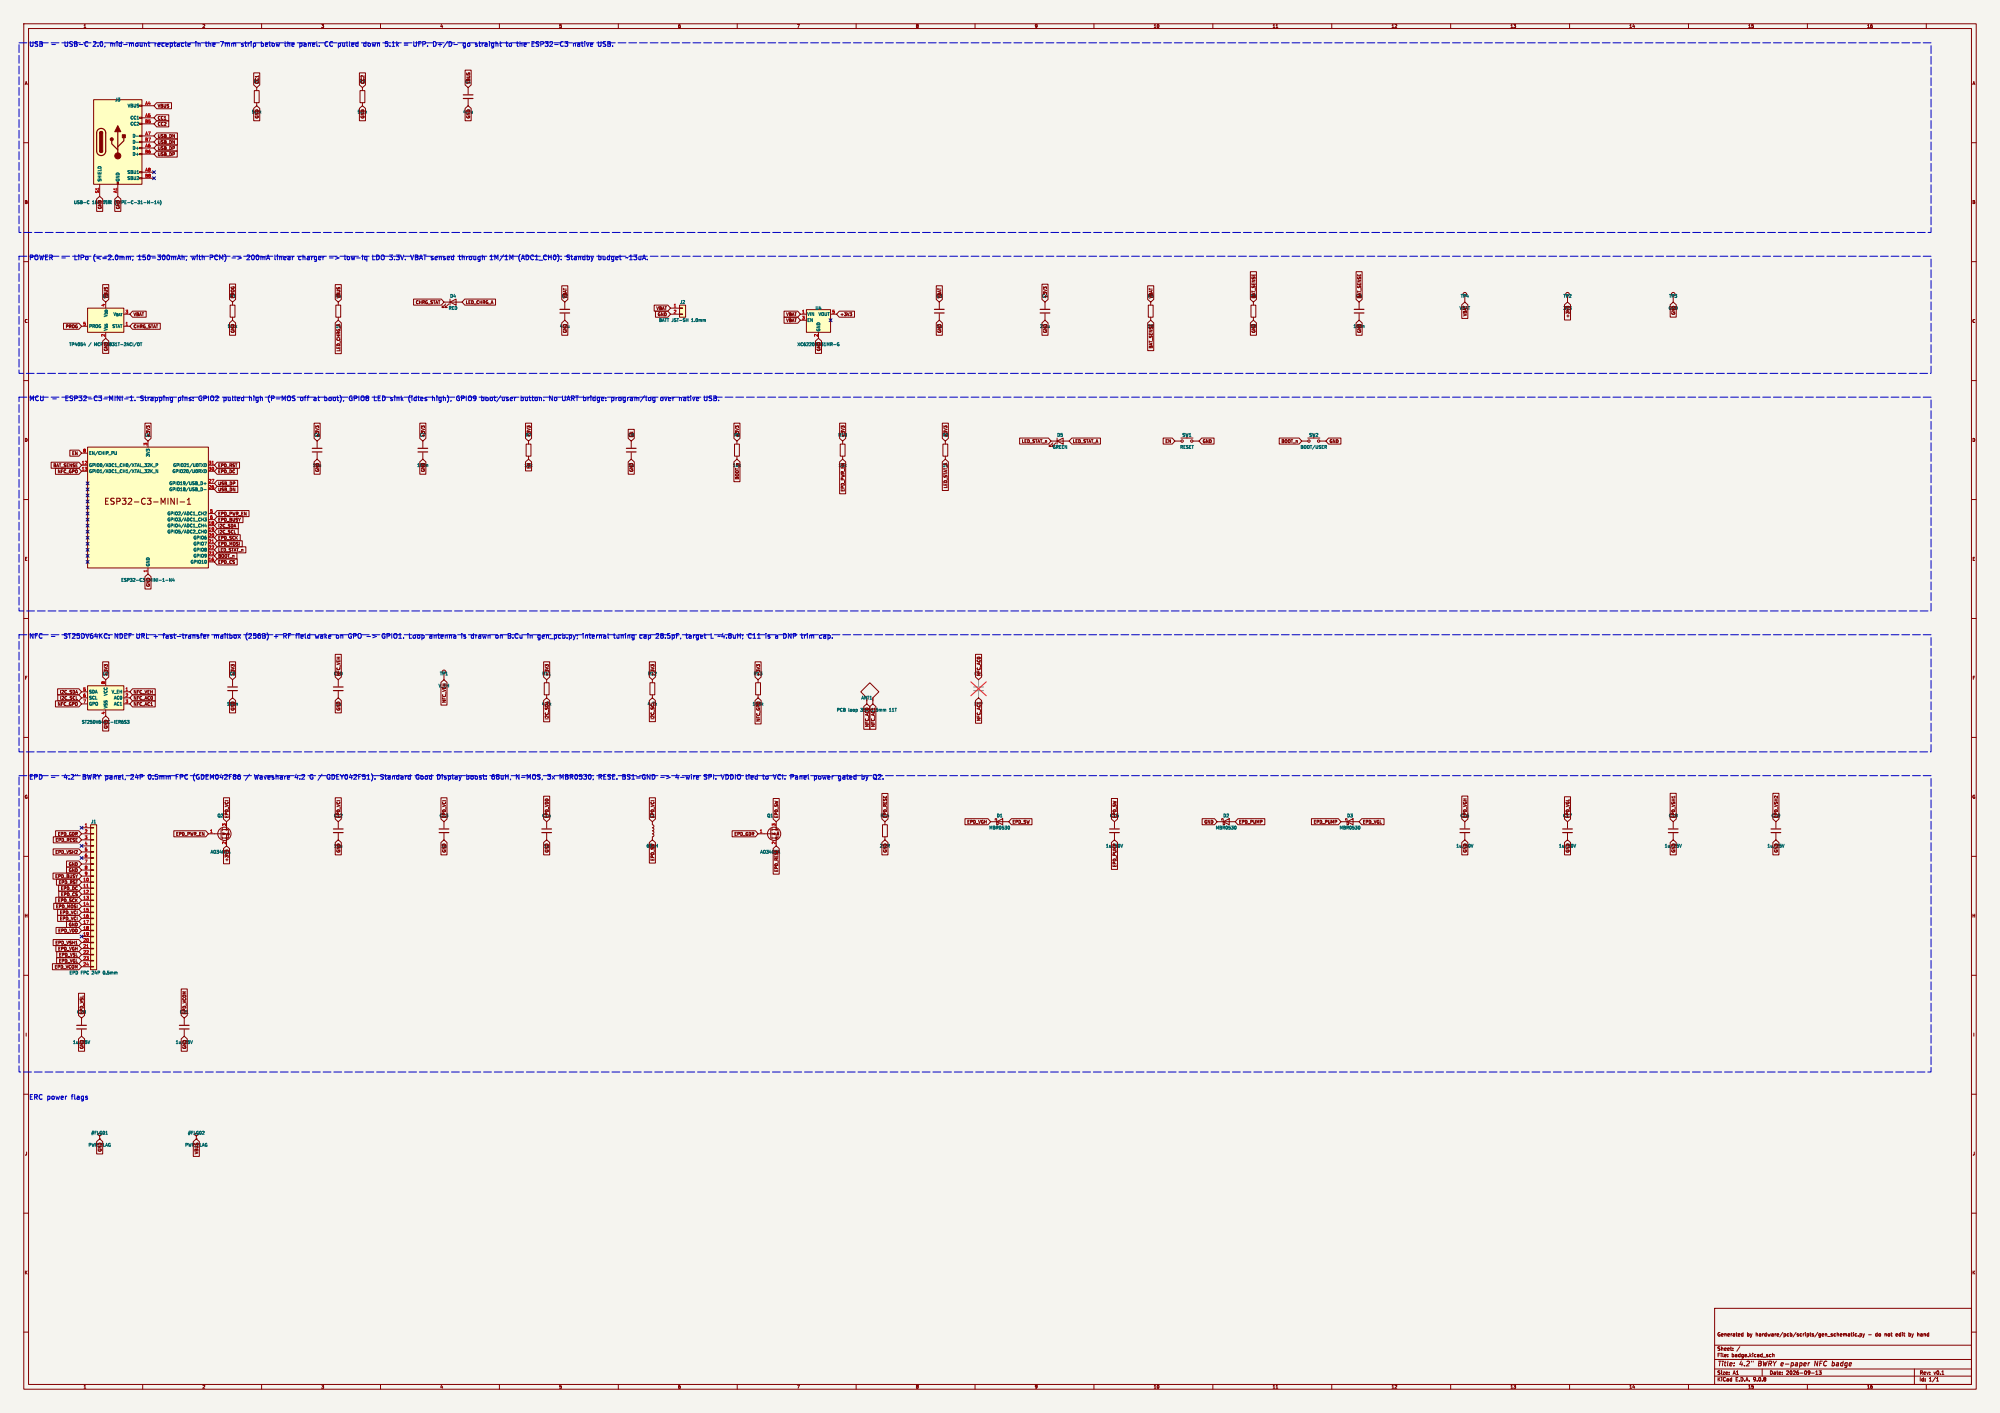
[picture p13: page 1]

1 GPIO21/U0TXD 31 GPIO20/U0RXD 30 GPIO19/USB_D+ 27 GPIO18/USB_D- 26 GPIO2/ADC1_CH2 5 GPIO3/ADC1_CH3 6 GPIO4/ADC1_CH4 18 GPIO5/ADC2_CH0 19 GPIO6 20 GPIO7 21 GPIO8 22 GPIO9 23 GPIO10 16 U1 ESP32-C3-MINI-1-N4 SHIELD S1 GND A1 VBUS A4 CC1 A5 CC2 B5 D- A7 D- B7 D+ A6 D+ B6 SBU1 A8 SBU2 B8

J2 BATT JST-SH 1.0mm ESP32-C3-MINI-1

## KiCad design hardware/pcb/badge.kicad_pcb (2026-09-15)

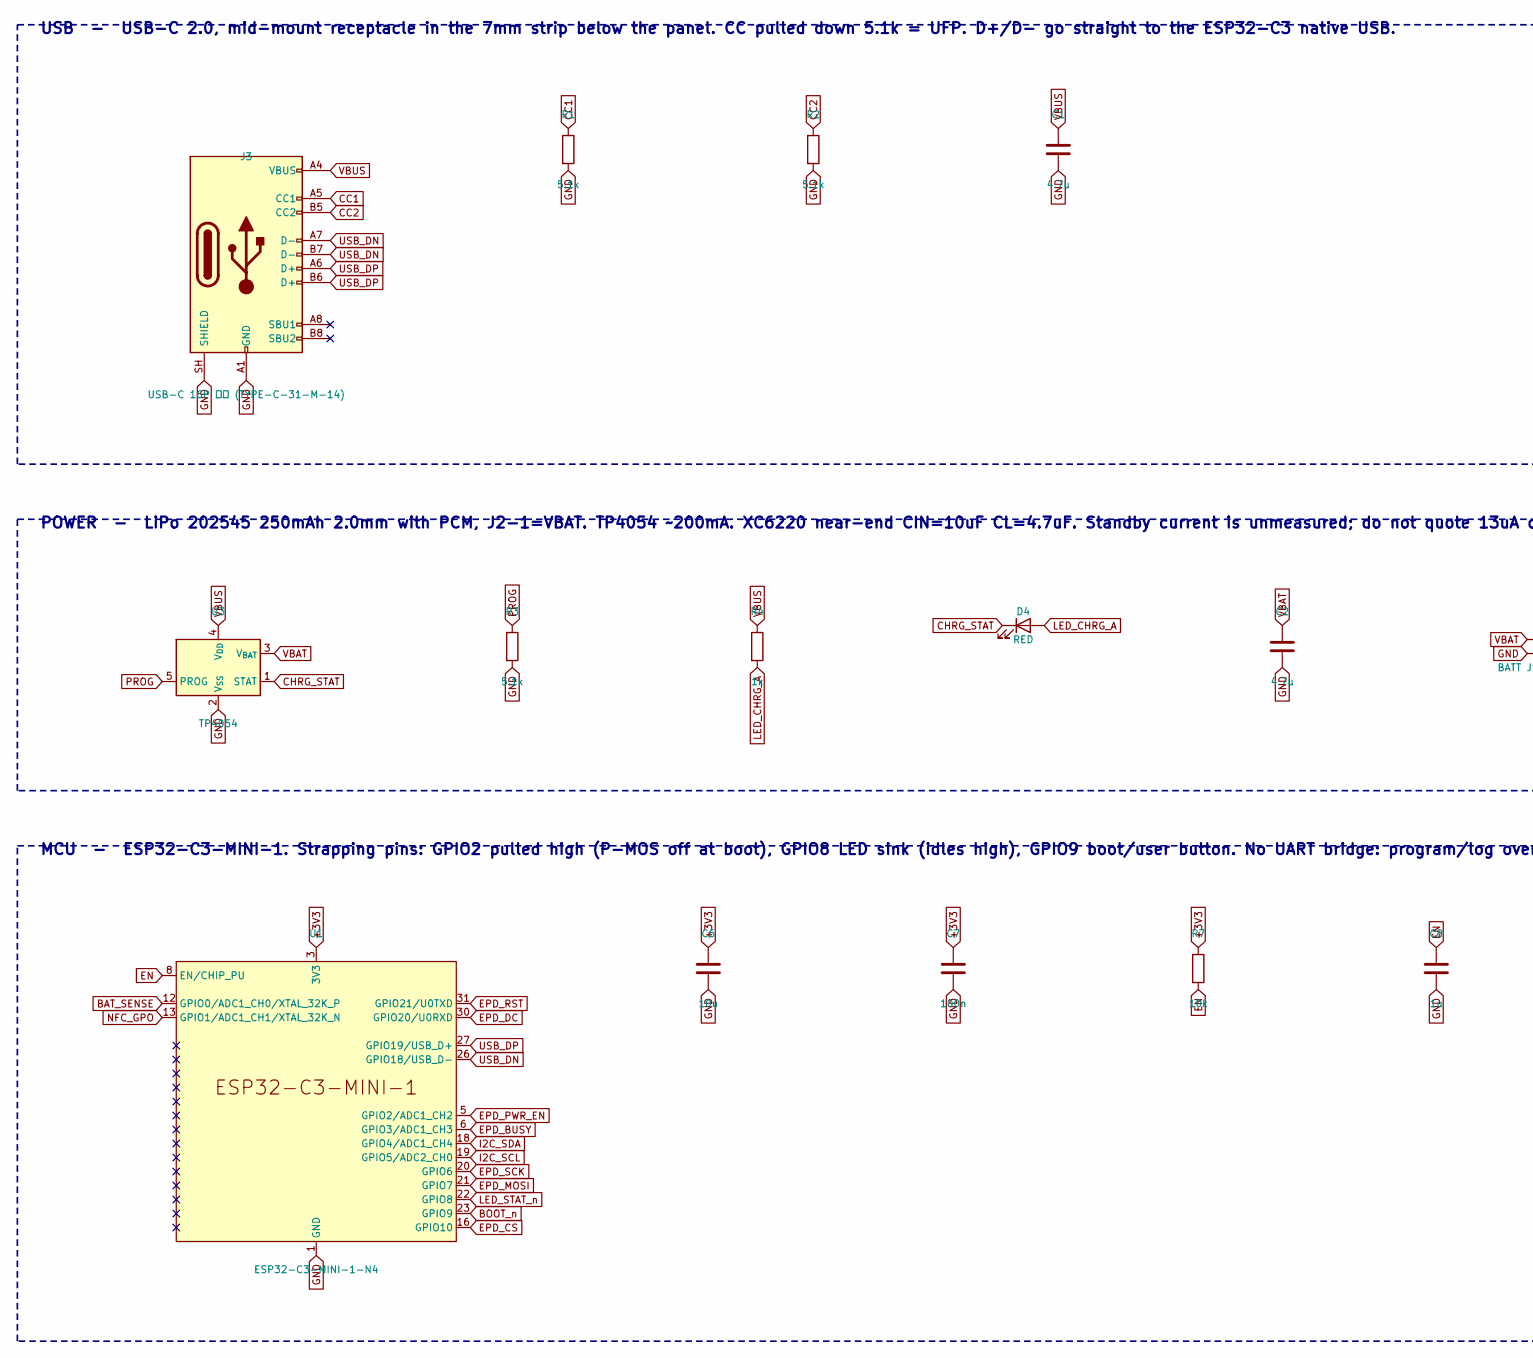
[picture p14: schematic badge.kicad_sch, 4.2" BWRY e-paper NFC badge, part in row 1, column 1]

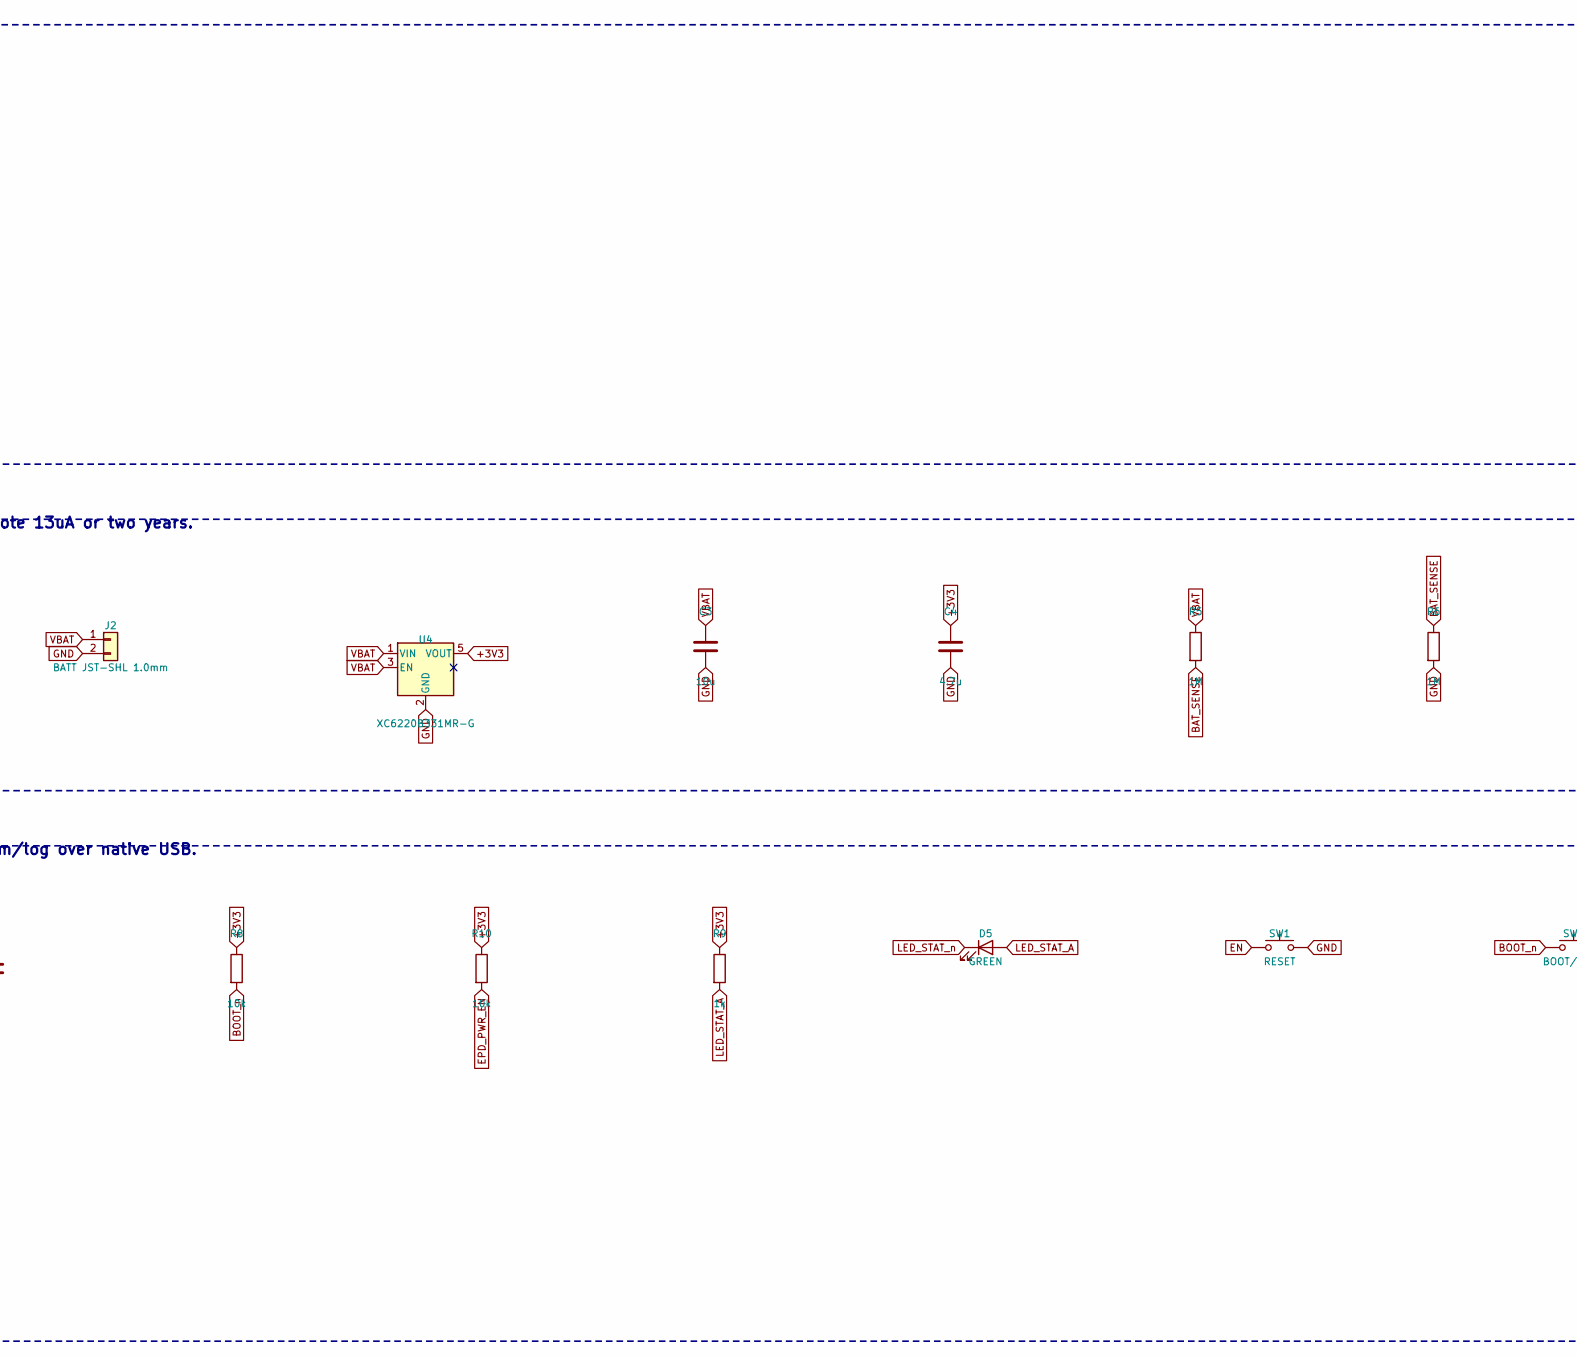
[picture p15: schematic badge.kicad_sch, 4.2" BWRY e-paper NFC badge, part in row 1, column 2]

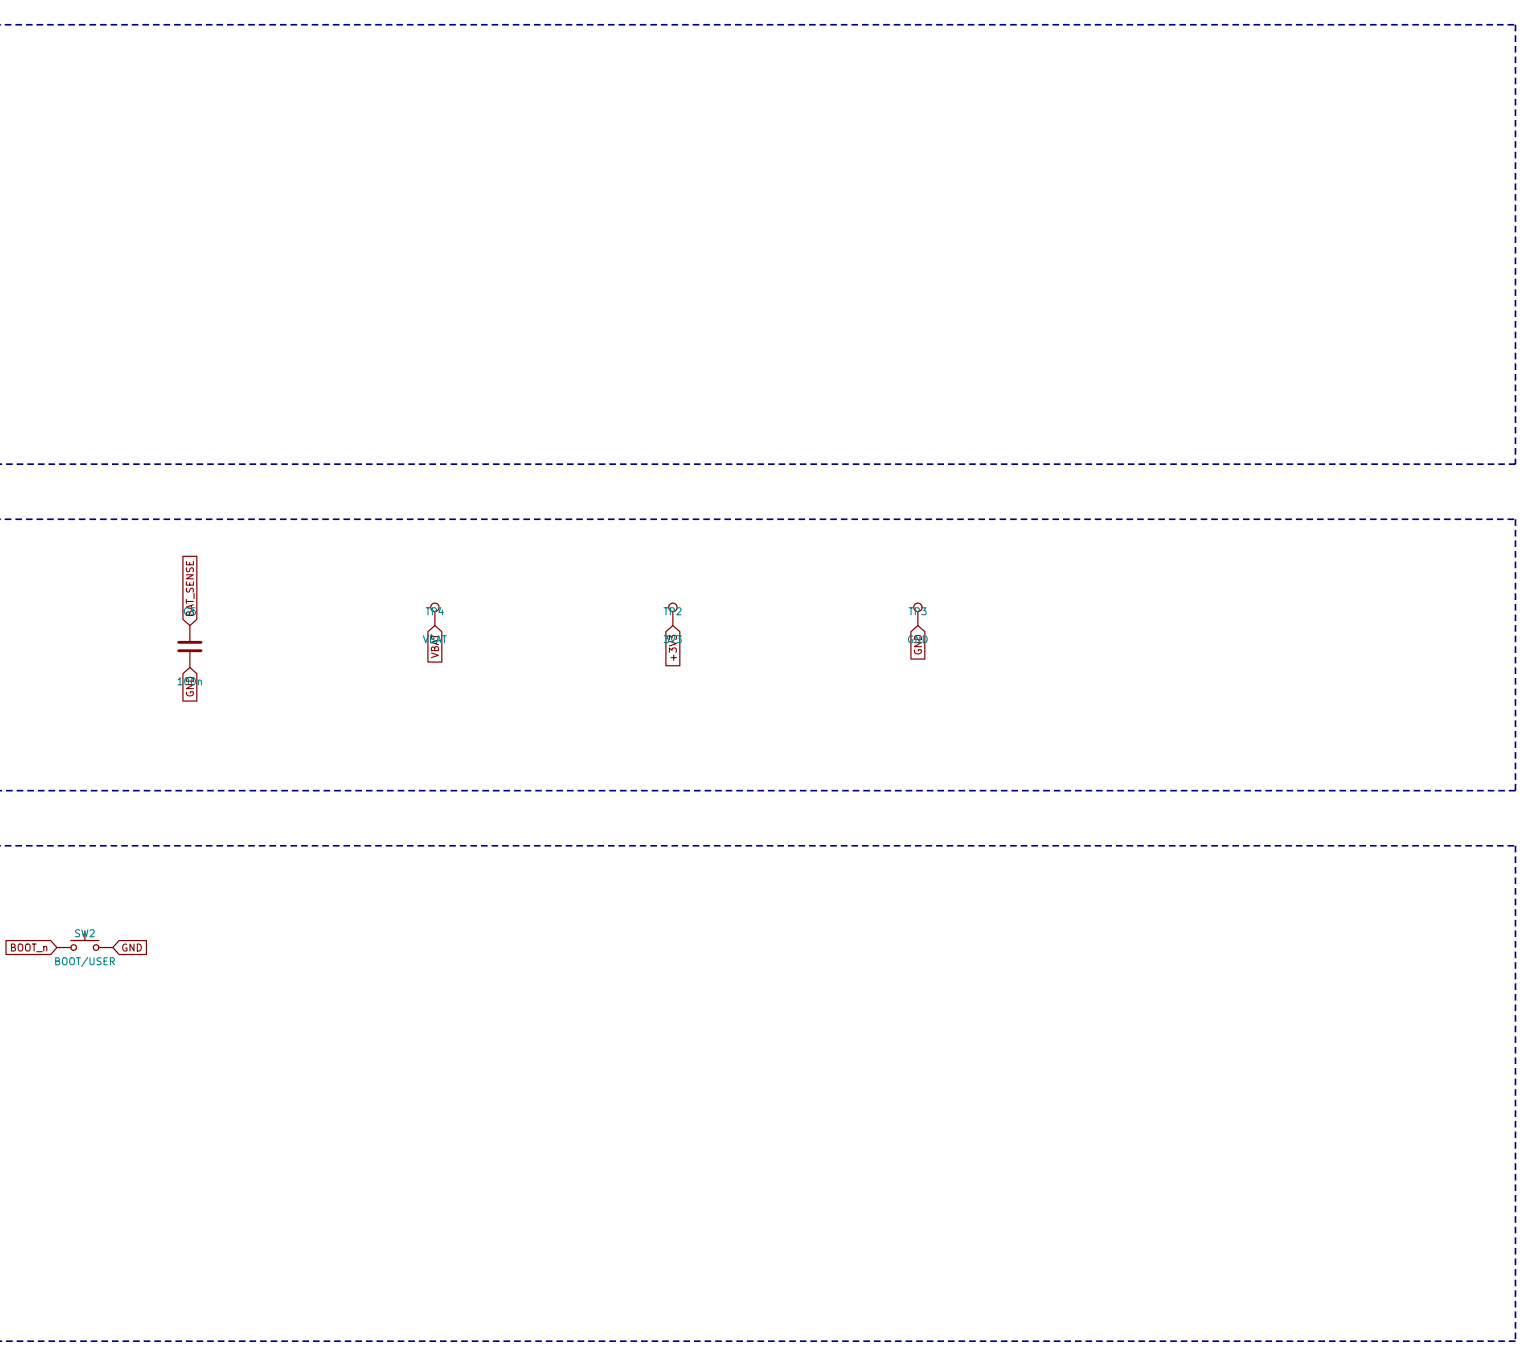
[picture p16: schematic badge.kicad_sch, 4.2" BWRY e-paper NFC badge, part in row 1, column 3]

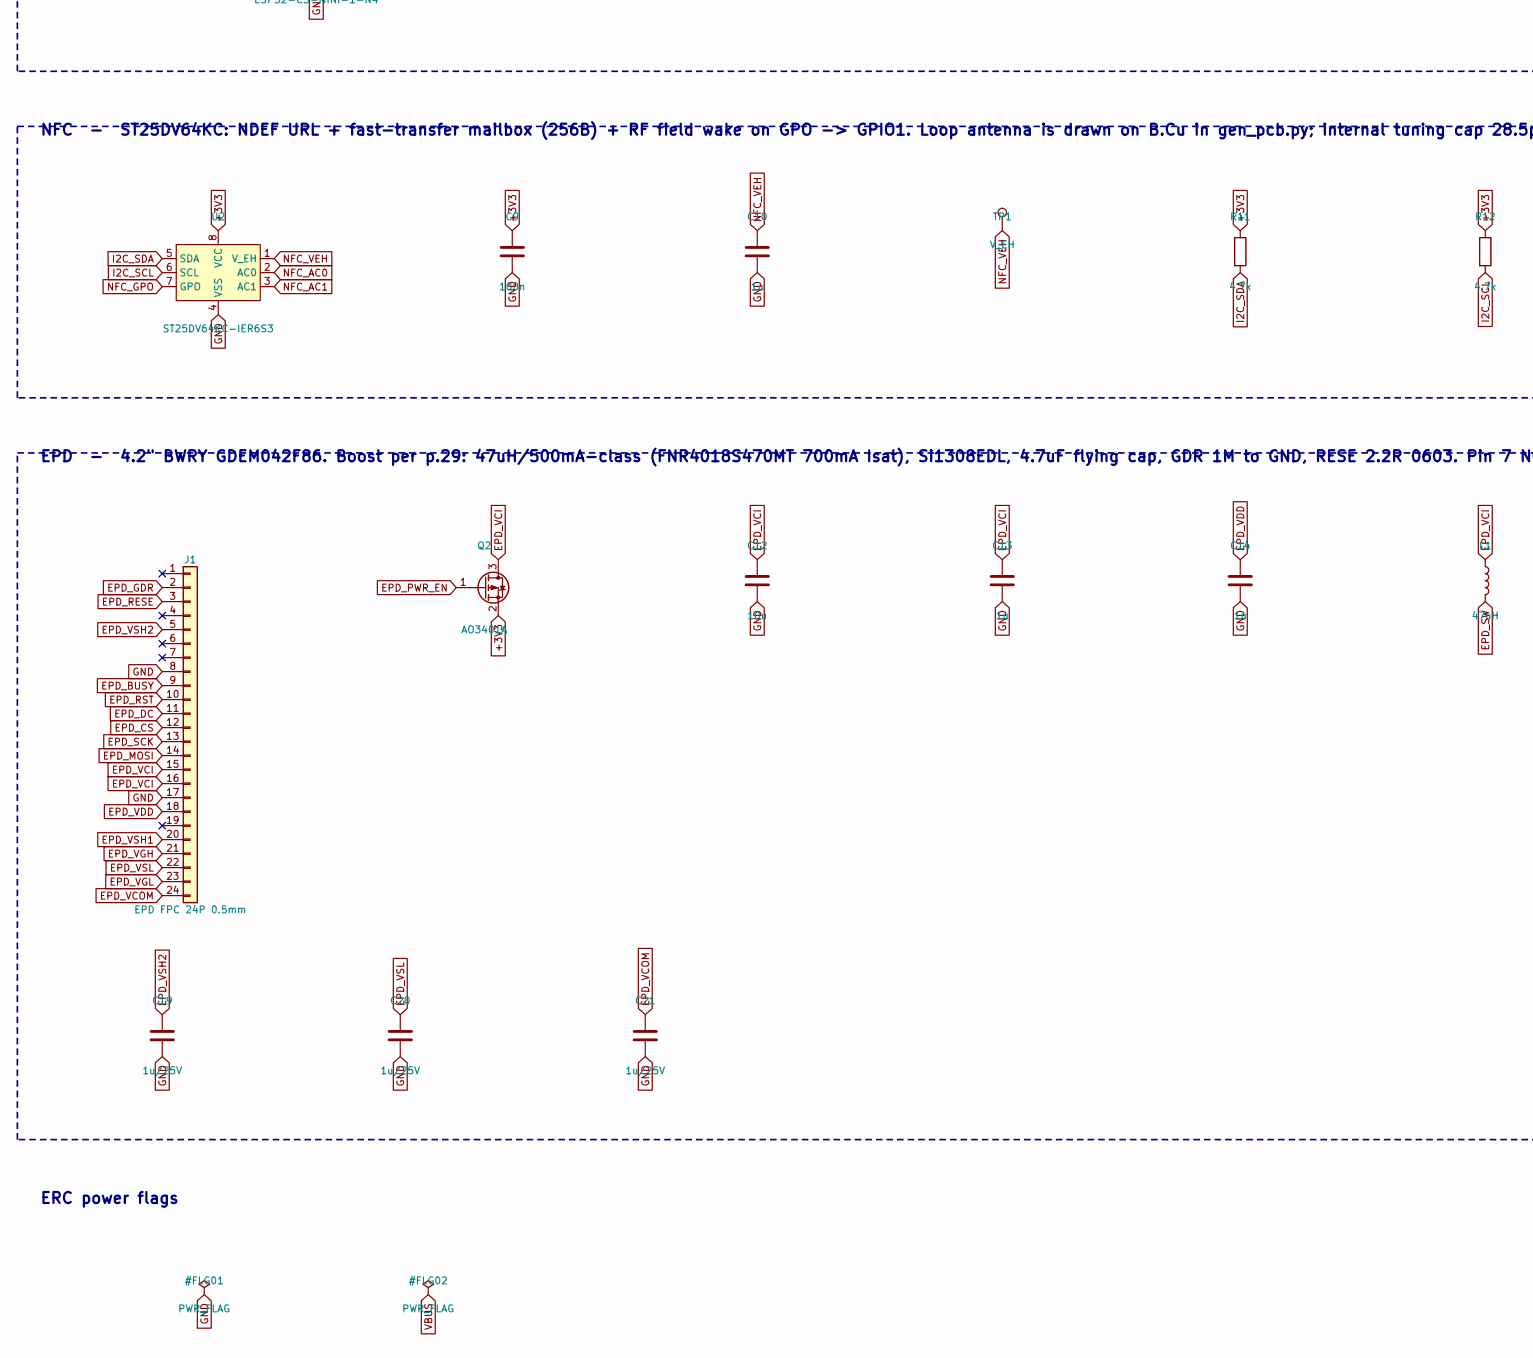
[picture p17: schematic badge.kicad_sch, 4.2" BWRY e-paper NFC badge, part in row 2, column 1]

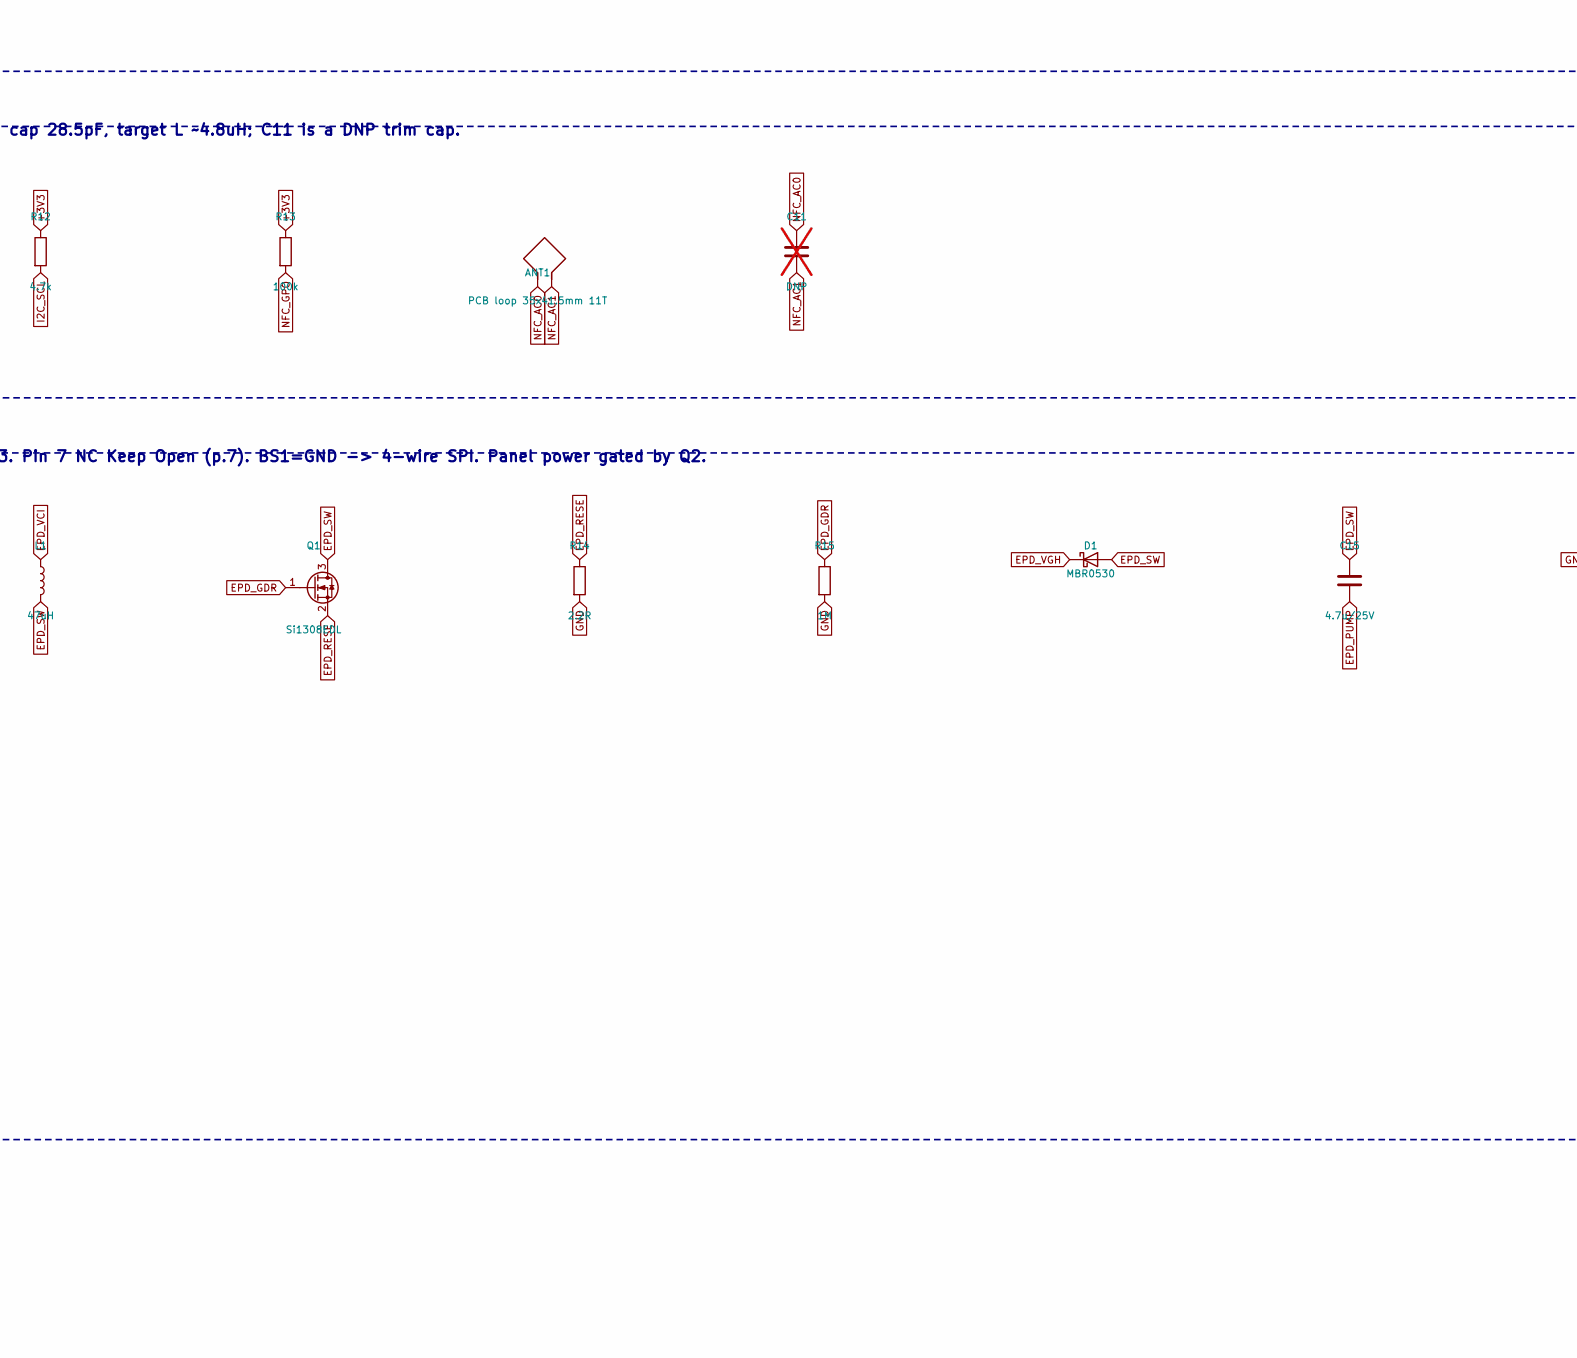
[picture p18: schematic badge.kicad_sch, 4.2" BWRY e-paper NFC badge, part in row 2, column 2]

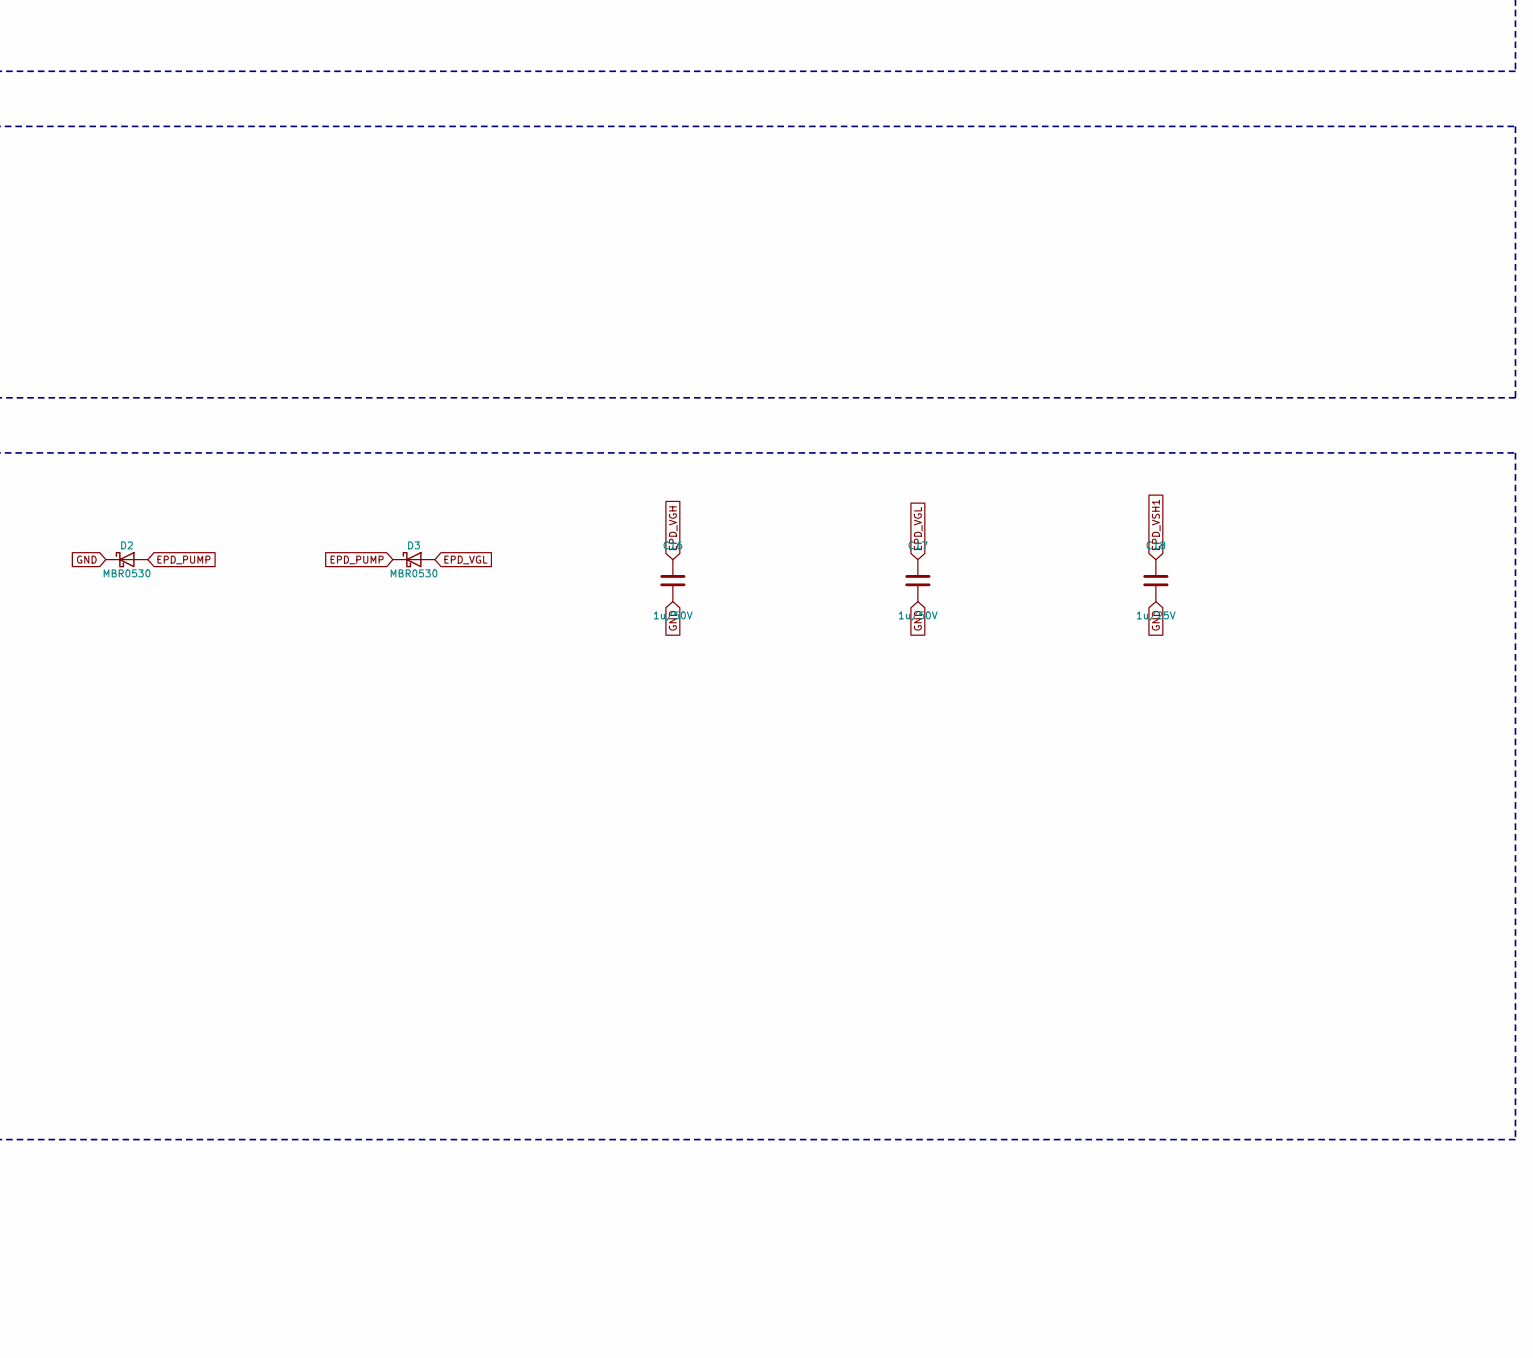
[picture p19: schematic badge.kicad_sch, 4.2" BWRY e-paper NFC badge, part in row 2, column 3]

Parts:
ANT1: PCB loop 35x41.5mm 11T; NFC_Loop
C1, C2, C4: 4.7u; C_0603_1608Metric
C3, C6, C12: 10u; C_0603_1608Metric
C5, C7, C9: 100n; C_0402_1005Metric
C8, C10, C13, C14: 1u; C_0402_1005Metric
C11: DNP; C_0402_1005Metric; not fitted
C15: 4.7u/25V; C_0805_2012Metric
C16, C17: 1u/50V; C_0805_2012Metric
C18, C19, C20, C21: 1u/25V; C_0603_1608Metric
D1, D2, D3: MBR0530; D_SOD-123; LCSC C77896
D4: RED; LED_0603_1608Metric
D5: GREEN; LED_0603_1608Metric
J1: EPD FPC 24P 0.5mm; Hirose_FH12-24S-0.5SH_1x24-1MP_P0.50mm_Horizontal; LCSC C262657
J2: BATT JST-SHL 1.0mm; JST_SHL_SM02B-SHLS-TF_1x02-1MP_P1.00mm_Horizontal; LCSC C145956
J3: USB-C 16P 沉板 (TYPE-C-31-M-14); TYPE-C-31-M-14; LCSC C223907
L1: 47uH; L_Changjiang_FNR4018S; LCSC C167813
Q1: Si1308EDL; SOT-323_SC-70; LCSC C469327
Q2: AO3401A; SOT-23; LCSC C15127
R1, R2, R3: 5.1k; R_0402_1005Metric
R4, R9: 1k; R_0402_1005Metric
R5, R6, R15: 1M; R_0402_1005Metric
R7, R8, R10: 10k; R_0402_1005Metric
R11, R12: 4.7k; R_0402_1005Metric
R13: 100k; R_0402_1005Metric
R14: 2.2R; R_0603_1608Metric
SW1: RESET; SW_SPST_PTS810; LCSC C221929
SW2: BOOT/USER; SW_SPST_PTS810; LCSC C221929
TP1: V_EH; TestPoint_Pad_D1.0mm
TP2: 3V3; TestPoint_Pad_D1.0mm
TP3: GND; TestPoint_Pad_D1.0mm
TP4: VBAT; TestPoint_Pad_D1.0mm
U1: ESP32-C3-MINI-1-N4; ESP32-C3-MINI-1; LCSC C2934569
U2: ST25DV64KC-IER6S3; SOIC-8_3.9x4.9mm_P1.27mm; LCSC C2830253
U3: TP4054; SOT-23-5; LCSC C32574
U4: XC6220B331MR-G; SOT-23-5; LCSC C86534

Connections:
+3V3: C4.1, C6.1, C7.1, C9.1, Q2.2 (S), R7.1, R8.1, R9.1, R10.1, R11.1, R12.1, R13.1, TP2.1, U1.3 (3V3), U2.8 (VCC), U4.5 (VOUT)
BAT_SENSE: C5.1, R5.2, R6.1, U1.12 (GPIO0/ADC1_CH0/XTAL_32K_P)
BOOT_n: R8.2, SW2.1, U1.23 (GPIO9)
CC1: J3.A5 (CC1), R1.1
CC2: J3.B5 (CC2), R2.1
CHRG_STAT: D4.1 (K), U3.1 (STAT)
EN: C8.1, R7.2, SW1.1, U1.8 (EN/CHIP_PU)
EPD_BUSY: J1.9, U1.6 (GPIO3/ADC1_CH3)
EPD_CS: J1.12, U1.16 (GPIO10)
EPD_DC: J1.11, U1.30 (GPIO20/U0RXD)
EPD_GDR: J1.2, Q1.1 (G), R15.1
EPD_MOSI: J1.14, U1.21 (GPIO7)
EPD_PUMP: C15.2, D2.2 (A), D3.1 (K)
EPD_PWR_EN: Q2.1 (G), R10.2, U1.5 (GPIO2/ADC1_CH2)
EPD_RESE: J1.3, Q1.2 (S), R14.1
EPD_RST: J1.10, U1.31 (GPIO21/U0TXD)
EPD_SCK: J1.13, U1.20 (GPIO6)
EPD_SW: C15.1, D1.2 (A), L1.2, Q1.3 (D)
EPD_VCI: C12.1, C13.1, J1.15, J1.16, L1.1, Q2.3 (D)
EPD_VCOM: C21.1, J1.24
EPD_VDD: C14.1, J1.18
EPD_VGH: C16.1, D1.1 (K), J1.21
EPD_VGL: C17.1, D3.2 (A), J1.23
EPD_VSH1: C18.1, J1.20
EPD_VSH2: C19.1, J1.5
EPD_VSL: C20.1, J1.22
GND: C1.2, C2.2, C3.2, C4.2, C5.2, C6.2, C7.2, C8.2, C9.2, C10.2, C12.2, C13.2, C14.2, C16.2, C17.2, C18.2, C19.2, C20.2, C21.2, D2.1 (K), J1.8, J1.17, J2.2, J3.A1 (GND), J3.A12 (GND), J3.B1 (GND), J3.B12 (GND), J3.SH (SHIELD), R1.2, R2.2, R3.2, R6.2, R14.2, R15.2, SW1.2, SW2.2, TP3.1, U1.1 (GND), U1.2 (GND), U1.11 (GND), U1.14 (GND), U1.36 (GND), U1.37 (GND), U1.38 (GND), U1.39 (GND), U1.40 (GND), U1.41 (GND), U1.42 (GND), U1.43 (GND), U1.44 (GND), U1.45 (GND), U1.46 (GND), U1.47 (GND), U1.48 (GND), U1.49 (GND), U1.50 (GND), U1.51 (GND), U1.52 (GND), U1.53 (GND), U2.4 (VSS), U3.2 (V_{SS}), U4.2 (GND)
I2C_SCL: R12.2, U1.19 (GPIO5/ADC2_CH0), U2.6 (SCL)
I2C_SDA: R11.2, U1.18 (GPIO4/ADC1_CH4), U2.5 (SDA)
LED_CHRG_A: D4.2 (A), R4.2
LED_STAT_A: D5.2 (A), R9.2
LED_STAT_n: D5.1 (K), U1.22 (GPIO8)
NFC_AC0: ANT1.1, C11.1, U2.2 (AC0)
NFC_AC1: ANT1.2, C11.2, U2.3 (AC1)
NFC_GPO: R13.2, U1.13 (GPIO1/ADC1_CH1/XTAL_32K_N), U2.7 (GPO)
NFC_VEH: C10.1, TP1.1, U2.1 (V_EH)
PROG: R3.1, U3.5 (PROG)
USB_DN: J3.A7 (D-), J3.B7 (D-), U1.26 (GPIO18/USB_D-)
USB_DP: J3.A6 (D+), J3.B6 (D+), U1.27 (GPIO19/USB_D+)
VBAT: C2.1, C3.1, J2.1, R5.1, TP4.1, U3.3 (V_{BAT}), U4.1 (VIN), U4.3 (EN)
VBUS: C1.1, J3.A4 (VBUS), J3.A9 (VBUS), J3.B4 (VBUS), J3.B9 (VBUS), R4.1, U3.4 (V_{DD})

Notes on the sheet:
USB - USB-C 2.0, mid-mount receptacle in the 7mm strip below the panel. CC pulled down 5.1k = UFP. D+/D- go straight to the ESP32-C3 native USB.
POWER - LiPo 202545 250mAh 2.0mm with PCM, J2-1=VBAT. TP4054 ~200mA. XC6220 near-end CIN=10uF CL=4.7uF. Standby current is unmeasured; do not quote 13uA or two years.
MCU - ESP32-C3-MINI-1. Strapping pins: GPIO2 pulled high (P-MOS off at boot), GPIO8 LED sink (idles high), GPIO9 boot/user button. No UART bridge: program/log over native USB.
NFC - ST25DV64KC: NDEF URL + fast-transfer mailbox (256B) + RF field wake on GPO -> GPIO1. Loop antenna is drawn on B.Cu in gen_pcb.py; internal tuning cap 28.5pF, target L ~4.8uH; C11 is a DNP trim cap.
EPD - 4.2" BWRY GDEM042F86. Boost per p.29: 47uH/500mA-class (FNR4018S470MT 700mA Isat), Si1308EDL, 4.7uF flying cap, GDR 1M to GND, RESE 2.2R 0603. Pin 7 NC Keep Open (p.7). BS1=GND -> 4-wire SPI. Panel power gated by Q2.
ERC power flags

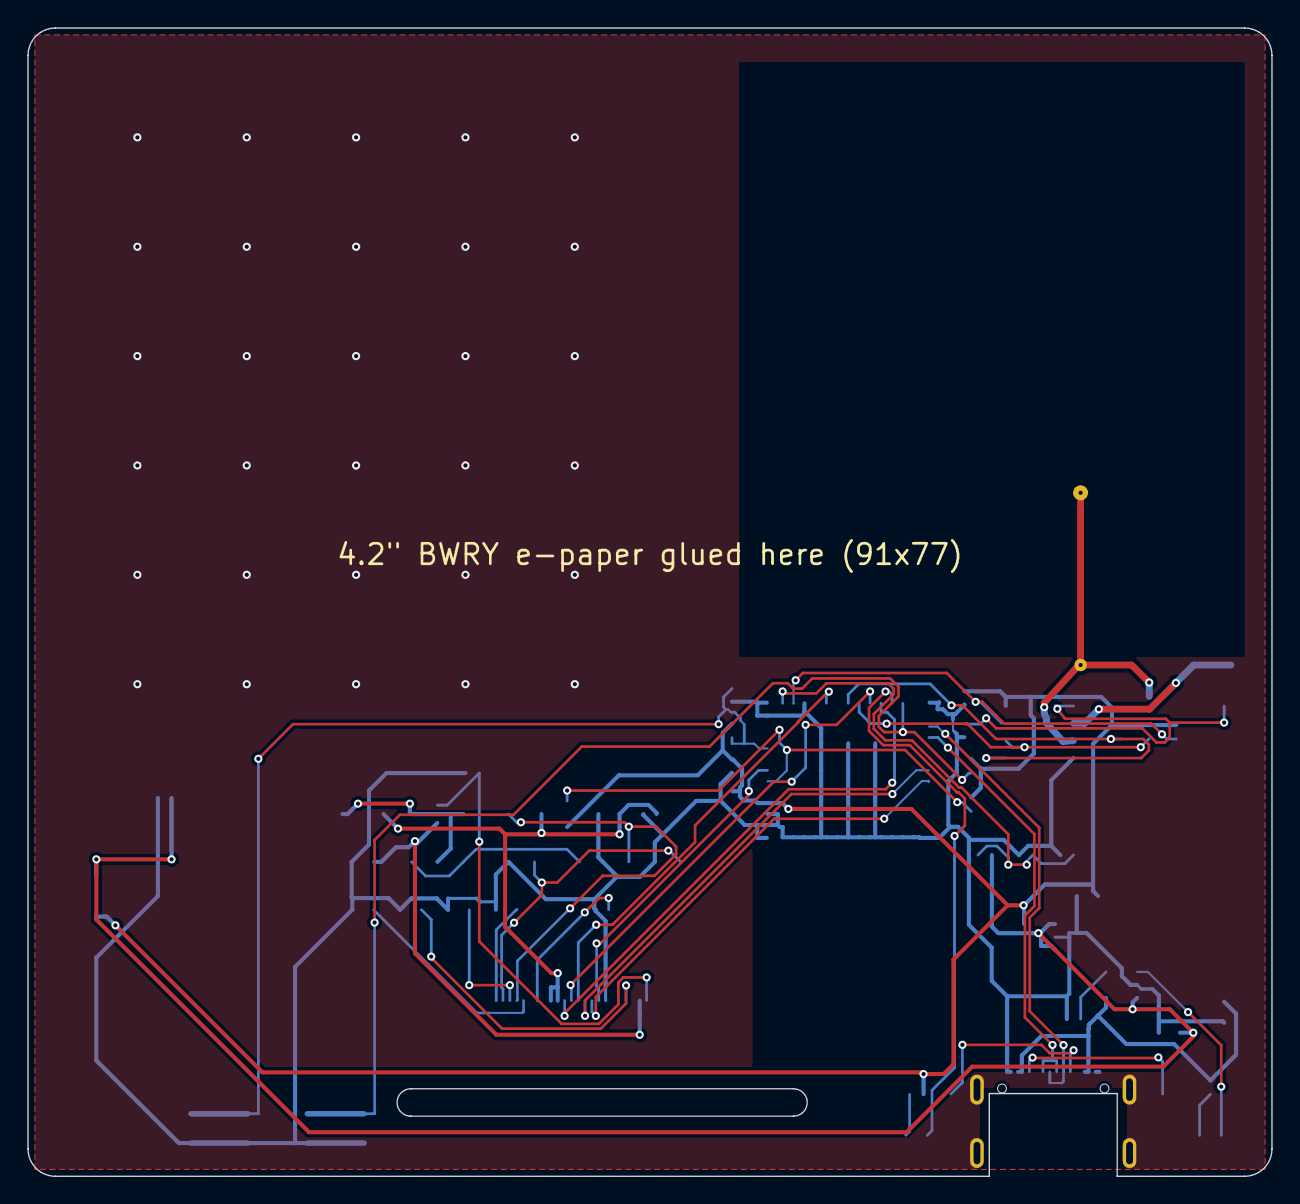
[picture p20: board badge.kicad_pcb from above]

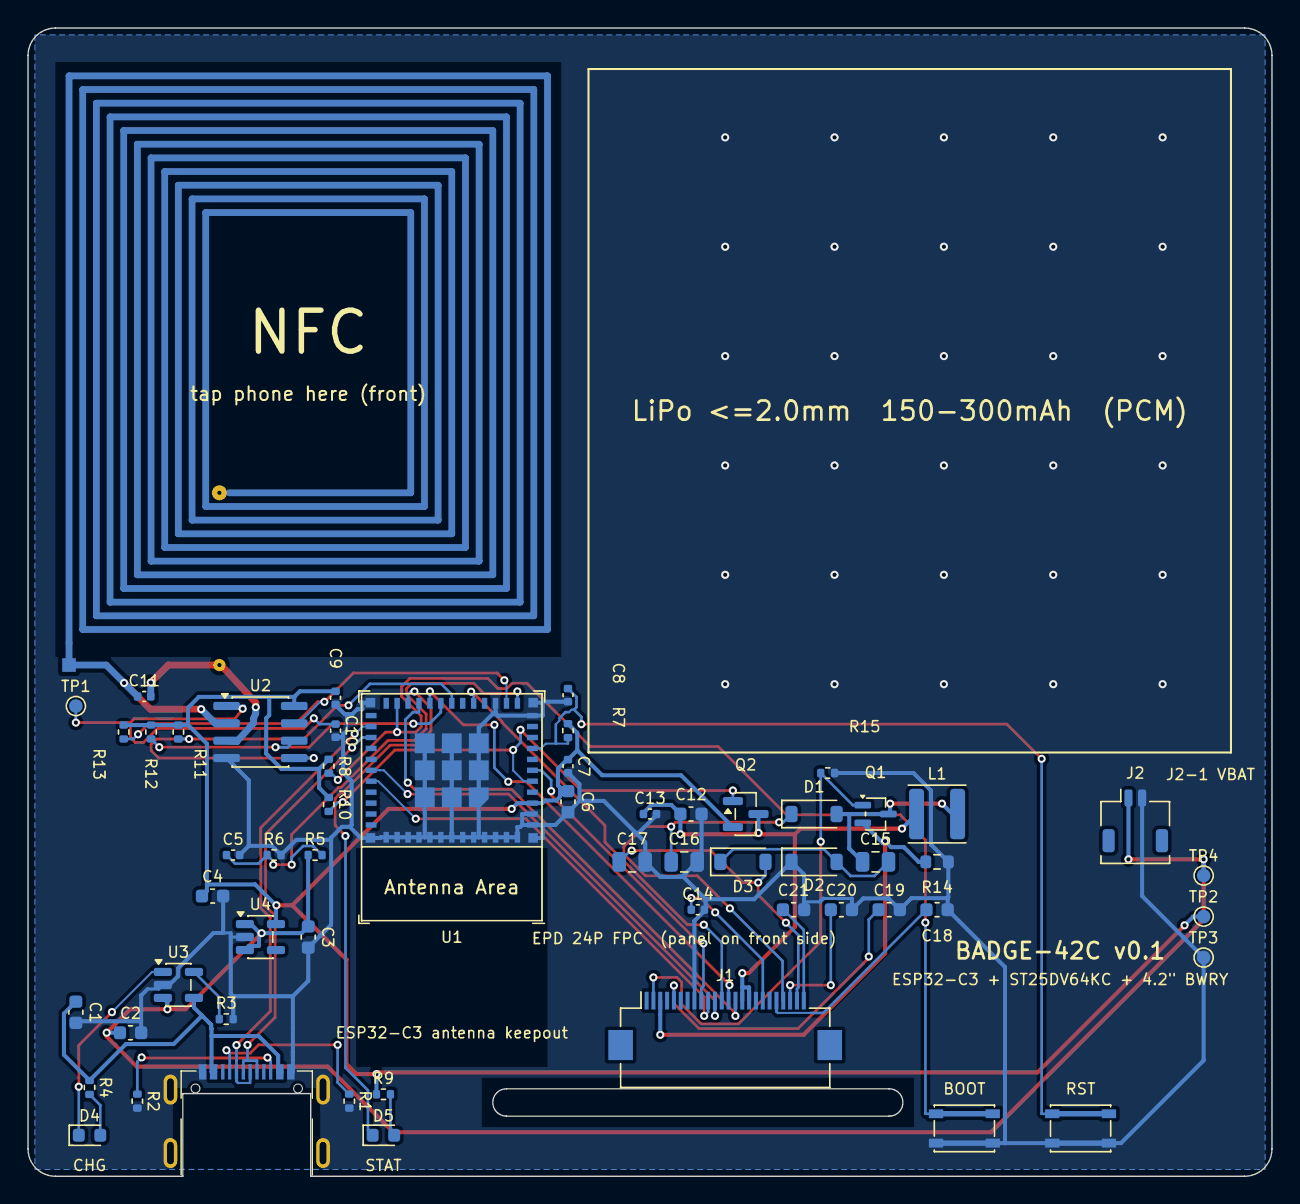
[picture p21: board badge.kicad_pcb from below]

Board: 2 copper layers, 91.0 x 84.0 mm, 58 parts (58 on the bottom side), 41 nets.

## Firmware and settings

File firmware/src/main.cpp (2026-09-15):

#include "epd.h"
#include "nfc.h"
#include "pins.h"

#include <Arduino.h>
#include <esp_sleep.h>

namespace {

void led(bool on) { digitalWrite(pins::LED_STAT_n, on ? LOW : HIGH); }

float vbat_volts() {
    // 1M/1M divider, 12-bit ADC, 11 dB attenuation ~ 0..2.5 V at pin.
    analogSetPinAttenuation(pins::BAT_SENSE, ADC_11db);
    uint32_t acc = 0;
    for (int i = 0; i < 8; i++) {
        acc += analogReadMilliVolts(pins::BAT_SENSE);
    }
    return (acc / 8.0f) * 2.0f / 1000.0f;
}

void blink(int n) {
    for (int i = 0; i < n; i++) {
        led(true);
        delay(80);
        led(false);
        delay(80);
    }
}

void go_sleep() {
    pinMode(pins::NFC_GPO, INPUT_PULLUP);
    pinMode(pins::BOOT_n, INPUT_PULLUP);
    digitalWrite(pins::EPD_PWR_EN, HIGH);
    gpio_hold_en(pins::GPIO_PWR_EN);
    gpio_deep_sleep_hold_en();
    // IDF 4.4.7 light-sleep/deep-sleep GPIO wake is GPIO0–5 only.
    // GPIO9 is strapping / ROM download, not a deep-sleep wake source.
    const uint64_t mask = (1ULL << pins::NFC_GPO);
    esp_err_t err = esp_deep_sleep_enable_gpio_wakeup(mask, ESP_GPIO_WAKEUP_GPIO_LOW);
    if (err != ESP_OK) {
        Serial.printf("sleep: gpio wakeup failed (%d)\n", static_cast<int>(err));
    } else {
        Serial.println("sleep: wake on NFC_GPO (GPIO1)");
    }
    Serial.flush();
    delay(20);
    esp_deep_sleep_start();
}

}  // namespace

void setup() {
    Serial.begin(115200);
    delay(400);
    Serial.println();
    Serial.println("BADGE-42C firmware v0.2");

    pinMode(pins::LED_STAT_n, OUTPUT);
    led(false);
    pinMode(pins::BOOT_n, INPUT_PULLUP);
    pinMode(pins::NFC_GPO, INPUT_PULLUP);

    epd::begin();
    nfc::begin();

    Serial.printf("VBAT ~ %.2f V\n", vbat_volts());
    Serial.printf("ST25DV %s at 0x%02X\n", nfc::present() ? "ACK" : "no ACK", nfc::ADDR_USER);
    Serial.printf("BOOT=%d GPO=%d\n", digitalRead(pins::BOOT_n), digitalRead(pins::NFC_GPO));

    gpio_hold_dis(pins::GPIO_PWR_EN);
    gpio_deep_sleep_hold_dis();

    // ROM download: hold BOOT (GPIO9) through RESET. Do not treat that as EPD self-test.
    uint32_t wait_cdc = millis();
    while (!Serial && (millis() - wait_cdc) < 8000) {
        delay(10);
    }
    Serial.println("send W within 5s for EPD white self-test");
    Serial.flush();
    bool want_white = false;
    uint32_t t0 = millis();
    while (millis() - t0 < 5000) {
        if (Serial.available()) {
            char c = static_cast<char>(Serial.read());
            if (c == 'W' || c == 'w') {
                want_white = true;
                break;
            }
        }
        delay(10);
    }

    if (want_white) {
        Serial.println("serial W: EPD OTP white refresh");
        led(true);
        bool ok = epd::refresh_solid(epd::Color::White);
        if (ok) {
            Serial.println("EPD refresh done");
        } else {
            Serial.printf("EPD refresh TIMEOUT at %s\n",
                          epd::last_fail[0] ? epd::last_fail : "unknown");
        }
        led(false);
    } else {
        blink(3);
    }

    go_sleep();
}

void loop() {}

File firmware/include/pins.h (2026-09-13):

#pragma once
/* BADGE-42C pin map. Source of truth: hardware/pcb/scripts/design.py */

#include <cstdint>
#include <driver/gpio.h>

namespace pins {

constexpr int BAT_SENSE   = 0;   // ADC1_CH0, VBAT / 2
constexpr int NFC_GPO     = 1;   // ST25DV GPO, open-drain, wake (active low)
constexpr int EPD_PWR_EN  = 2;   // P-MOS gate, active low; 10k pull-up, off at boot
constexpr int EPD_BUSY    = 3;   // busy while LOW (GDEM042F86 p.7 note 5-4)
constexpr int I2C_SDA     = 4;
constexpr int I2C_SCL     = 5;
constexpr int EPD_SCK     = 6;
constexpr int EPD_MOSI    = 7;
constexpr int LED_STAT_n  = 8;   // green, sink, idle HIGH
constexpr int BOOT_n      = 9;   // SW2, 10k pull-up, pressed LOW
constexpr int EPD_CS      = 10;
constexpr int EPD_DC      = 20;
constexpr int EPD_RST     = 21;

constexpr gpio_num_t GPIO_NFC_GPO = GPIO_NUM_1;
constexpr gpio_num_t GPIO_BOOT    = GPIO_NUM_9;
constexpr gpio_num_t GPIO_PWR_EN  = GPIO_NUM_2;

}  // namespace pins

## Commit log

2026-09-13 Add architecture decisions, KiCad schematic/PCB generators and unrouted board
    [badge.kicad_pcb, badge.kicad_sch]
2026-09-13 Route PCB (Freerouting + GND stitching), add enclosure, BOM, firmware pin map, export script
    [badge.kicad_pcb, badge_assembly.FCStd, badge_assembly.step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]
2026-09-13 Add README, handoff document, export outputs and enclosure assembly with routed PCB
    [badge-B_Cu.gbr, badge-B_Mask.gbr, badge-B_Paste.gbr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]
2026-09-13 Stitch GND pour islands to DRC-clean PCB and write handoff for next session
    Current board is 564 tracks / 128 vias with zero DRC errors. route_pcb.py
    gains island stitching, J1 pin 7 to GND, ESP GND net-tie, and via nudge.
    Handoff and review checklist capture remaining work: make stitching
    reproducible, NFC soldermask, fab review, firmware.
    [badge-B_Cu.gbr, badge-B_Mask.gbr, badge-B_Paste.gbr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]
2026-09-13 Add local Cursor rules so a desktop session can continue without the cloud
    AGENTS.md and always-on Cursor rules capture conventions, current PCB
    status, and the next hardware steps. README now points at the GitHub clone URL.
2026-09-13 Make GND stitching reproducible from the 78-via routed board
    Leftover B.Cu islands now drop occupying vias that miss F.Cu main only when an overlap via actually fits, then restore them otherwise. From bce5813 this yields 564 segments / 128 vias with DRC 0, and a second --skip-route is a no-op.
    [badge-B_Cu.gbr, badge-B_Mask.gbr, badge-B_Paste.gbr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]
2026-09-13 Cover NFC coil with soldermask without re-routing
    Drop F.Mask/B.Mask from ANT1 SMD pads in gen_nfc_footprint.py. A full gen_pcb + Freerouting pass shorted USB D+/D- at J3, so the DRC-clean 564/128 board only had ANT1 SMD mask/paste stripped in place. Through-hole pad 2 stays tented-open. DRC 0.
    [badge-B_Cu.gbr, badge-B_Mask.gbr, badge-B_Paste.gbr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]
2026-09-13 Correct NFC soldermask docs: do not re-route for mask-only changes
    The old handoff required gen_pcb.py plus Freerouting after covering the coil. That was wrong: copper did not change, and a trial re-route shorted USB D+/D-. Also require asking before overriding the docs.
2026-09-13 Rearrange back silkscreen so labels no longer overlap J1 and BOOT/RST
    The chipset line sat on J1; SW1/SW2 refs sat on the button labels. Silk only, no re-route.
    [badge.kicad_pcb]
2026-09-13 Add a visual-check checklist so 3D uncertainty is classified before asking
    J1 looked unknown because the close-up missed the connector. Next time: re-read this doc, inspect design.py, re-shoot, then ask only if the board is actually wrong.
2026-09-13 Record that NFC 3D is green because the coil is under soldermask
    Copper is still there; yellow would mean exposed ENIG. Close J1 on the review checklist and log the enclosure coord mismatches to discuss before changing.
2026-09-13 Set enclosure ACTIVE_TOP to 6.7 mm from the GDEM042F86 drawing
    Official spec p.6 centers the 63.60 mm AA in the 77 mm outline; 4.5 mm would crop the image. Pin table and 2.2 ohm RESE also match the PDF.
    [badge_assembly.FCStd, badge_assembly.step, badge_back_cover.FCStd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]
2026-09-13 Add ESP32-C3 bring-up firmware with OTP white refresh
    USB CDC, battery ADC, ST25DV probe, and a GDEM042F86 LUT-from-OTP fill when BOOT is held. Then deep sleep on GPO or BOOT.
2026-09-14 Accept 0.8 mm PCB for JLCPCB and close the USB thickness item.
    [badge_assembly.FCStd, badge_assembly.step, badge_back_cover.FCStd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]
2026-09-14 Record that the FreeCAD assembly is gray CAD, not the KiCad board render.
2026-09-15 Land H2 board (KiCad 10 full ERC/DRC 0) and firmware v0.2 F1.
    Freeze the 680/115 board, hygiene scripts, and self-test fixes (GPIO1 wake, serial W, BUSY fail-closed) so GitHub matches the local pass. v0.1 bins stay as baseline.
    [badge.kicad_pcb, badge.kicad_sch, badge_bom_assembly.csv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]
2026-09-15 Align docs, license, CI, and adhesive spec with the H2 board.
    Stop treating the old 564-track / pin-7 GND snapshot as current, pin espressif32@7.1.3, and close the process debt (CERN-OHL-P + MIT, GitHub Actions, 3M 467MP).
